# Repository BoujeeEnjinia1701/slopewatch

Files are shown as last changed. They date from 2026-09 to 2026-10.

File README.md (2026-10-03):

# SlopeWatch

     

**Area:** Mining · **TRL:** 3 of 9 (proof of concept on paper) · **Value-engineering target:** about $250 USD · **Difficulty:** 3 of 5

A network of low-cost tilt and displacement sensors for waste dumps, tailings dams, pit walls and landslide-prone slopes, reporting through FieldNode and alerting when movement accelerates.

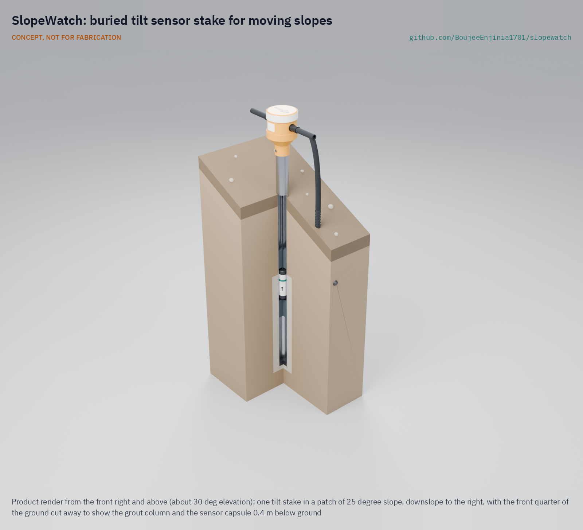
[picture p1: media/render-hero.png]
SlopeWatch: buried tilt sensor stake for moving slopes, product render


[Exploded render](media/render-exploded.png) · [Detail render](media/render-detail.png) · [Interactive 3D model](media/viewer.html) · [Concept blueprint (PDF)](media/concept-blueprint.pdf) · [General arrangement SLW-DWG-001 (PDF)](cad/drawings/SLW-DWG-001.pdf) · [Calculations SLW-CAL-001](docs/04-calcs/01-sizing.md) · [Prototype build plan](docs/05-build-plan.md) · [Design decisions register](docs/06-design-decisions.md) · [Review note](docs/REVIEW.md)

## Concept rationale

Many slopes speed up before they fail, and the rate of movement, not a single position, is what tells people to leave. SlopeWatch measures that rate with MEMS tilt sensors buried in grouted stakes and a crack gauge at the crest, following a published surface-tilt method with precaution and warning thresholds of 0.01 and 0.1 degrees per hour ([Uchimura et al., 2015](https://www.sciencedirect.com/science/article/pii/S0038080615001122)). All sensors share one FieldNode power and radio core, and the siren and beacon on site are driven by that node directly, so the alarm still works when the network does not.

It is open and garage-buildable because the sites that most need monitoring, small mines, quarries and hillside villages, cannot buy slope radar or pay for geotechnical staff. The stakes are steel pipe and hand-mixed grout, the electronics are off the shelf, and the data format and alert rules are open, so a local partner can build, repair and audit the system and an engineer can check every reading.

## Burning platform

Landslides killed 55,997 people in 4,862 non-seismic events from 2004 to 2016, and slides triggered by human activity, including illegal mining and hill cutting, are increasing ([Froude and Petley, 2018](https://nhess.copernicus.org/articles/18/2161/2018/)). Mining failures add to the toll: the Brumadinho tailings dam collapse in Brazil killed 270 people in 2019 ([Zhu, Zhang and Puzrin, 2024](https://www.nature.com/articles/s43247-023-01086-9)), and the 2020 slope failure at the Hpakant jade mines in Myanmar killed at least 172 miners after about half a year of accelerating movement visible from satellite ([Hpakant multi-sensor study, 2021](https://www.sciencedirect.com/science/article/pii/S0924271621001489)).

The people most exposed have the least monitoring. An estimated 44 million people work in artisanal and small-scale mining across 80 countries ([World Bank, 2021](https://www.worldbank.org/en/news/press-release/2021/05/03/better-working-conditions-can-improve-safety-and-productivity-of-artisanal-and-small-scale-miners-around-t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)), mostly without any instrument on the pit walls and dumps above them. Not every failure gives surface warning (Brumadinho moved only about 30 mm in its final year; [Zhu, Zhang and Puzrin, 2024](https://www.nature.com/articles/s43247-023-01086-9)), so SlopeWatch is a first layer for slopes that move progressively, not a guarantee.

## Where it could be used

### By industry

| Industry | Use |
| --- | --- |
| Artisanal and small-scale mining | Tilt stakes on pit walls and benches above working areas, with a siren where people dig |
| Quarrying and aggregates | Monitoring benches, stockpiles and overburden dumps at sites with no geotechnical system |
| Mine waste management | Waste rock dumps and, with the owner's and engineer of record's permission, a supplementary layer on tailings embankments |
| Roads and railways | Cut slopes above roads in hill districts, alerting maintenance crews after heavy rain |
| Disaster risk management | Community landslide early warning run by a district disaster office or village committee |
| Research and education | An open, repeatable field instrument for university geotechnical projects and threshold studies |

### By country or region

| Country or region | Why it matters there |
| --- | --- |
| Brazil | The Fundão (2015, 19 deaths) and Brumadinho (2019, 270 deaths) tailings failures ([UK House of Commons Library](https://commonslibrary.parliament.uk/research-briefings/cdp-2023-0133/); [Zhu, Zhang and Puzrin, 2024](https://www.nature.com/articles/s43247-023-01086-9)) show the stakes; Brumadinho moved only about 30 mm in its last year, so SlopeWatch would suit the many smaller dumps and pit walls that move progressively, not a dam of that kind. |
| Myanmar | The 2020 Hpakant jade mine failure killed at least 172 miners after months of accelerating movement ([Hpakant multi-sensor study, 2021](https://www.sciencedirect.com/science/article/pii/S0924271621001489)); a rate-of-movement alarm is built to catch that kind of acceleration. |
| Ghana | On 3 September 2026 an illegal (galamsey) gold pit collapsed at Manso Keniago in the Ashanti Region, killing eight of the twelve miners inside ([Ghana Broadcasting Corporation](https://www.gbcghanaonline.com/general/eight-illegal-miners-confirmed-dead-after-pit-collapse-in-amansie-south/2026/2/)); worldwide, landslides triggered by illegal mining are increasing ([Froude and Petley, 2018](https://nhess.copernicus.org/articles/18/2161/2018/)). |
| India | Asia accounts for 75 % of fatal landslides ([Froude and Petley, 2018](https://nhess.copernicus.org/articles/18/2161/2018/)); a university wireless sensor network in Munnar, Kerala, delivered real-time warnings that led to evacuation alerts ([Amrita](https://www.amrita.edu/center/awna/landslide/)), showing that local networks can work. |
| Italy | The national inventory lists more than 620,000 landslides ([ISPRA IFFI](https://www.progettoiffi.isprambiente.it/en/inventory/)); low-cost stakes suit the many small slopes that official networks cannot cover. |
| Japan | The surface-tilt method and thresholds SlopeWatch adopts were developed on slopes in Japan and China ([Uchimura et al., 2015](https://www.sciencedirect.com/science/article/pii/S0038080615001122)), giving a high-income reference for validation. |

## What sparked the idea

The starting point was the Aberfan disaster of 21 October 1966, when colliery spoil Tip 7 slid onto a village and its school in South Wales and killed 144 people, 116 of them children ([Glamorgan Archives](https://glamarchives.gov.uk/blood/aberfan); [Institution of Civil Engineers](https://www.ice.org.uk/what-is-civil-engineering/infrastructure-projects/aberfan-disaster-lessons-learned)). An earlier tip on the same mountainside, Tip 4, had suffered a rotational slip followed by a flow slide in 1944 ([Hansard, House of Commons, 26 October 1967](https://api.parliament.uk/historic-hansard/commons/1967/oct/26/aberfan-disaster)), and on the morning of the disaster the crew found the point of Tip 7 had sunk by 9 to 10 ft (about 3 m), and then by about 20 ft (6 m), before the slide, as recorded by the Tribunal of inquiry ([Tribunal findings, quoted by the Northern Mine Research Society](https://nmrs.org.uk/mines-map/accidents-disasters/glamorganshire/aberfan-disaster-merthyr-tydfil-1966/)). The movement was seen, yet nothing turned it into a timely warning for the people below. The Tribunal found that blame rested on the National Coal Board, and the Mines and Quarries (Tips) Act 1969 followed to set safety rules for tips in Britain ([Hansard](https://api.parliament.uk/historic-hansard/commons/1967/oct/26/aberfan-disaster); [Glamorgan Archives](https://glamarchives.gov.uk/blood/aberfan)); SlopeWatch asks what a low-cost rate-of-movement alarm could do for the waste dumps and informal pits that have no such regime.

## Problem

Slope and tailings failures often give warning through slow movement, but monitoring is costly and many small mines and hillside communities have none.

## Concept

A network of low-cost tilt and displacement sensors for waste dumps, tailings dams, pit walls and landslide-prone slopes, reporting through FieldNode and alerting when movement accelerates.

Full design precis: [docs/02-concept.md](docs/02-concept.md)

## Key components

- Three tilt stakes: 48.3 mm steel pipe grouted 0.8 m into the slope, each with a sealed MEMS inclinometer capsule held on the pipe axis 0.4 m below ground, and a head made from stock drainage fittings that joins the capsule to the bus
- Crack displacement gauge (100 mm range) with its own bus reader, across a tension crack at the crest
- RS-485 sensor bus cable in conduit
- FieldNode power and radio core (shared lab component) on an existing pole at the toe, or on the optional mast
- Siren and beacon alert unit driven by the node, clamped to the pole like the FieldNode core, with a keyed silence switch on its own post about 5 m from the mast
- Gateway and alert software: any LoRaWAN server, SMS alerts and an inverse-velocity plot

Checked by calculation at TRL 3 ([SLW-CAL-001](docs/04-calcs/01-sizing.md)): readings every 10 min; the siren starts about 13 s after a confirmed warning with no network; temperature drift of a buried capsule stays within 0.0012 degrees per hour, about eight times below the precaution threshold; five sunless days in the precaution state with one alarm use about 7.3 Wh of the FieldNode cell's 13.1 Wh at -10 °C. Under Amish's decisions of 2026-09-25 ([SLW-DDR-002](docs/decisions/0002-recommendations-accepted.md)), the reference site mounts the node on an existing pole, with the mast as a site option, and the keyed silence switch stands on its own post about 5 m from the mast, where the siren gives about 95 dB(A) instead of about 105 dB(A). Value-engineering target: USD 250. Estimated cost of the constructable design: USD 304.00 per reference site for the SlopeWatch-specific parts (USD 54.00 over the target; $332.00 where a new mast is needed); the FieldNode core ($126) is costed in its own project. Siren reach near machinery, the FieldNode 12 V rail current, the FieldNode enclosure temperature and the remote alert time at the slowest radio setting are at risk. See the [design precis](docs/02-concept.md) and [requirements](docs/03-requirements.md).

The priced bill of materials is in [bom/bom.csv](bom/bom.csv); the parametric model is `cad/src/model.py`, with STEP and STL files in `cad/step/` and `cad/stl/`.

## Building the prototype

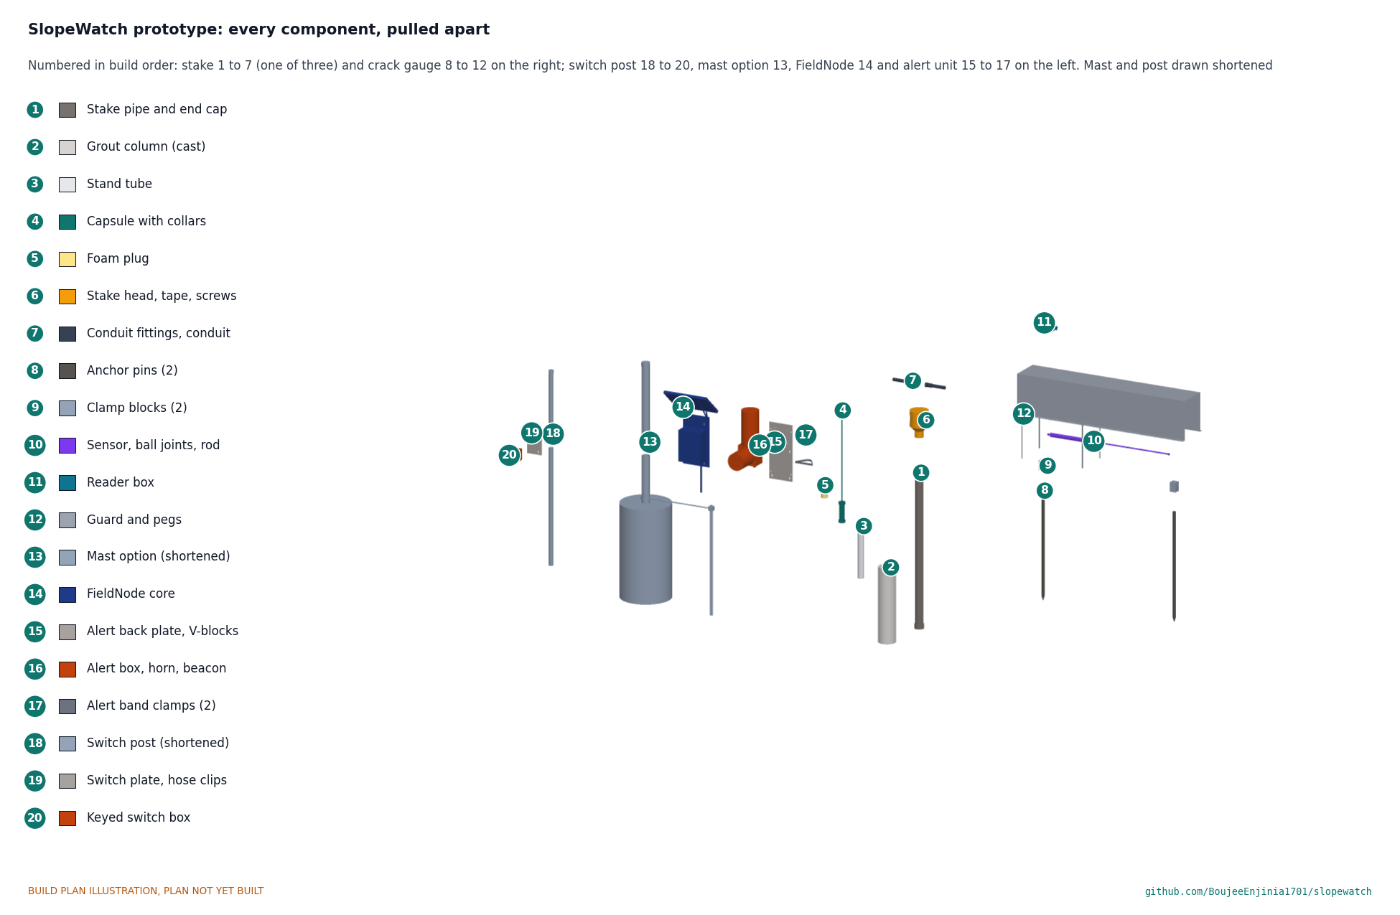
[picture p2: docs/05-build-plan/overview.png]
SlopeWatch prototype: every component pulled apart and numbered in build order


The [prototype build plan](docs/05-build-plan.md) (SLW-BLD-001) shows, in pictures, how to make each of the twenty components of one site kit and put them together in eighteen steps; nothing has been built yet. The made parts are the steel stakes with their stand tubes, printed collars and potted capsules, stake heads from stock drainage fittings, the crack gauge's pins, clamp blocks, rod and folded guard, and the aluminium and steel plates that clamp the alert unit and the keyed switch to their posts. Writing the plan made the design buildable: the capsule is now held on the pipe axis, the head can join the bus in and out, the gauge and its guard have real fixings, and the alert unit clamps to a pole the same way as the FieldNode core ([SLW-DDR-003](docs/decisions/0003-design-for-construction.md), accepted by Amish on 2026-10-02). Every picture is drawn from the model, and the model checks that each part touches what it should and clears what it should not.

## Safety

> Installing sensors on unstable ground is hazardous. Only trained teams should work on slopes, never below an actively moving face, and never on a tailings dam without the owner's permit and the engineer of record's agreement. The system is a research prototype that does not replace engineered monitoring: a silent siren is not proof of a safe slope, and some failures give no surface warning.
>
> The FieldNode core holds a LiFePO4 cell: use its fuse and cold-charge lockout. Wet cement grout burns skin and eyes; wear gloves and eye protection. Bond the mast to an earth rod and keep clear of overhead power lines.

## Repository layout

| Folder | Contents |
| --- | --- |
| `docs/` | Problem, concept, requirements, calculations and design decisions |
| `cad/src/` | build123d Python source, the source of truth for all geometry |
| `cad/step/`, `cad/stl/` | Exported models for FreeCAD, other CAD tools and printing |
| `cad/drawings/` | 2D sketches and dimensioned drawings |
| `bom/` | Bill of materials |
| `electronics/` | KiCad schematics and PCB layouts |
| `firmware/` | Microcontroller code |
| `media/` | Renders, perspectives and photos |
| `build-log/` | Dated prototyping notes |

## Documentation

Controlled documents follow the portfolio [documentation standard](.kit/STANDARDS.md). Each carries a document ID (SLW-PRC-001 for the precis), a version and a revision history. Branded PDFs are built with `python .kit/render.py` and attached to GitHub Releases when a document is tagged, for example `SLW-PRC-001/v1.0`.

## Credits

Designed by Amish Chadha. See [CONTRIBUTORS.md](CONTRIBUTORS.md) for roles. To cite this design, use [CITATION.cff](CITATION.cff) (GitHub shows it as "Cite this repository").

AI assistance (Claude) was used to accelerate concept renders, prototype documentation and first-pass sizing calculations. Design direction and all decisions are Amish Chadha's, recorded in this repository's decision records (`docs/decisions/`).

## Licenses

- **Hardware** (CAD, drawings, BOM, electronics): [CERN-OHL-S v2](LICENSE)
- **Software** (firmware, scripts, notebooks): [MIT](LICENSE-SOFTWARE)

A project of the [Design Molecule](https://designmolecule.com) lab.

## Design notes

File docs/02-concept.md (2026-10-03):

---
doc_id: SLW-PRC-001
title: SlopeWatch design precis
project: SlopeWatch
doc_type: Design precis
version: "0.7"
status: Draft
date: '2026-10-02'
author: Amish Chadha
license: CERN-OHL-S-2.0
revisions:
- version: "0.1"
  date: '2026-09-25'
  author: Amish Chadha
  change: Initial scaffold
- version: "0.2"
  date: '2026-09-25'
  author: Amish Chadha
  change: Populate to TRL 2 (architecture, alert logic, first-order numbers, safety, media)
- version: "0.3"
  date: '2026-09-25'
  author: Amish Chadha
  change: TRL 3 update from SLW-DDR-001 and SLW-CAL-001 (choices adopted for TRL 3 work, capsule 0.4 m deep, crack-gauge reader, beacon duty, checked numbers, cost, drawing SLW-DWG-001)
- version: "0.4"
  date: '2026-09-25'
  author: Amish Chadha
  change: Recommendations accepted by Amish (DDR-002)
- version: "0.5"
  date: '2026-10-01'
  author: Amish Chadha
  change: Constructable design (SLW-DDR-003) and build plan SLW-BLD-001; cost against the value-engineering target; key numbers from SLW-CAL-001 v0.3
- version: "0.6"
  date: '2026-10-02'
  author: Amish Chadha
  change: "Decisions of 2026-10-02 carried in: thresholds for logging only until set per site, mast conditions, second alert unit at machinery sites, cable protection and fault message, stake marking, wall holes, pinout, first partner"
- version: "0.7"
  date: '2026-10-02'
  author: Amish Chadha
  change: "Approved decisions carried into the figures: stake head marking cost, 60.3 mm site mast case and gust condition, alert back plate wall holes, port pin assignment; cost from SLW-CAL-001 v0.4"
---

# SlopeWatch design precis

SlopeWatch watches a slope for accelerating movement with three grouted tilt stakes and a crack gauge, cabled to one FieldNode core on an existing pole (or an optional mast) at the toe, and sounds a siren and beacon on site when the tilt rate passes a warning threshold, while sending an SMS through LoRaWAN. The TRL 3 calculations (SLW-CAL-001) show that the inclinometer resolves the tilt-rate thresholds with a wide margin, that a capsule 0.4 m deep keeps temperature drift within R2 even in wet soil, that the siren starts about 13 s after a confirmed warning, and that the FieldNode cell covers five sunless days with an alarm. Amish accepted the recommended choices on 2026-09-25 (SLW-DDR-002): the reference site uses an existing pole, with the mast as a site option, and the keyed silence switch stands on its own post about 5 m from the siren. Making the design physically buildable (SLW-DDR-003, accepted by Amish on 2026-10-02) added end caps, stand tubes and centring collars to the stakes, stake heads from stock drainage fittings with conduit fittings, clamp blocks and ball joints on the crack gauge, and a pole mounting for the alert unit; the prototype build plan is SLW-BLD-001. Value-engineering target: USD 250. Estimated cost of the constructable design: USD 304.00 for the SlopeWatch-specific parts of the reference site (USD 54.00 over the target), or $332.00 where a new mast is needed; the FieldNode core ($126) is costed in its own project. The main risks are siren reach near machinery, the unrated FieldNode 12 V rail current and the remote alert time at the slowest radio setting.

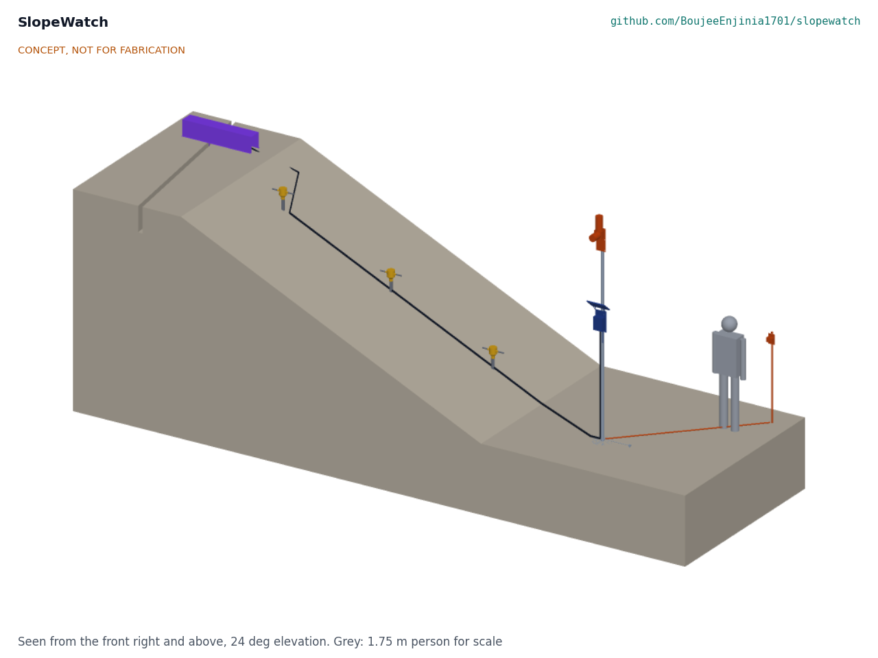
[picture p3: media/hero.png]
Hero render


*Figure 1. SlopeWatch on a 25 degree slope (spacing compressed for the picture; the reference site has stakes 10 m apart): three tilt stakes on the fall line, a crack gauge (purple) across a tension crack at the crest, the mast (a site option; an existing pole in the reference site) with FieldNode core, siren and beacon at the toe, and the keyed switch on its own post. Grey figure: 1.75 m person for scale.*

## How it works

1. **Sense tilt.** Each tilt stake is a 48 mm steel pipe grouted 0.8 m into the slope's surface layer. A sealed capsule with a MEMS inclinometer sits inside the pipe 0.4 m below ground, between two foam plugs. When the surface layer creeps downslope, the stake rotates with it; the approach and its thresholds follow Uchimura et al. ([2015](https://www.sciencedirect.com/science/article/pii/S0038080615001122)).
2. **Sense cracks.** A crack gauge spans a tension crack near the crest, where movement often shows first: two anchor pins either side of the crack and a 100 mm linear displacement sensor between them, under a guard, with a small reader board that puts the gauge on the same bus as the capsules.
3. **Collect.** A four-core cable in conduit links all sensors on an RS-485 bus to one of the FieldNode core's M12 ports, powered from its 5 V rail. Every 10 min the node switches the bus on for about 12 s, reads a 10 s average from each capsule and the gauge, and switches it off.
4. **Decide.** The node computes the tilt and opening rate for each sensor and runs the alert rules below. Raw readings are kept on the node's flash for at least 90 days.
5. **Alarm.** In the warning state the node drives the siren and beacon through the second M12 port from its 12 V rail, with no network needed, and raises its uplink rate from hourly to every 10 min.
6. **Notify and review.** Readings reach any LoRaWAN server (the lab's TwinKit gateway or The Things Network). An open alert service sends SMS or app messages to named people and plots inverse velocity against time ([Fukuzono, 1985](https://www.jstage.jst.go.jp/article/jls1964/22/2/22_2_8/_article)) for the engineer.

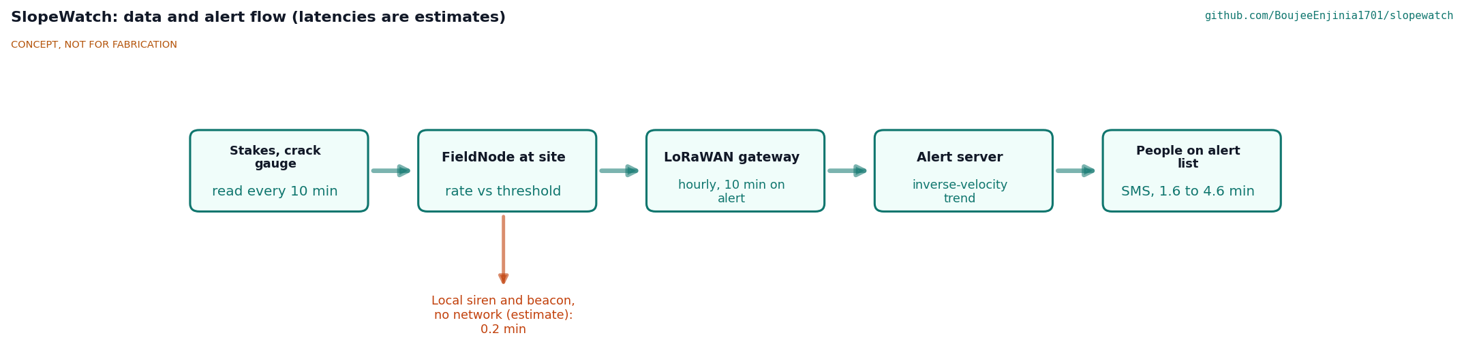
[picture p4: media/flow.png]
Data and alert flow


*Figure 2. Data and alert flow for one site. The local siren path does not depend on the network. All latencies are estimates.*

### Alert rules

The tilt rules below were decided by Amish on 2026-09-25 (SLW-DDR-001 D6, SLW-DDR-002). The crack-opening thresholds are placeholders. A geotechnical partner sets the thresholds per site before any alarm goes live; until then the tilt-rate thresholds and the crack placeholders are used for logging only, not for public alarms (decided by Amish, 2026-10-02; SLW-DDR-001 O3).

Table 1. Alert states.

| State | Entered when | Action |
| --- | --- | --- |
| Normal | No condition below | Read every 10 min; uplink hourly |
| Precaution | Any stake tilts faster than 0.01 degrees per hour averaged over 3 h, or the crack opens faster than 1 mm per day over 24 h (placeholder) | Uplink every 10 min; message to the site manager and engineer; beacon flashes slowly at 1 % duty or less (for example 100 ms every 10 s) |
| Warning | Any stake tilts faster than 0.1 degrees per hour over 1 h, confirmed on two consecutive readings, or the crack opens faster than 1 mm per hour (placeholder) | Siren and fast beacon on site; SMS to everyone on the list; inverse-velocity plot flagged |
| Silenced | Keyed switch on its post about 5 m from the mast | Siren off for 30 min, beacon stays on; the node re-arms automatically |

## Main components

Numbers match the exploded view (Figure 3) and `bom/bom.csv`.

Table 2. Main components.

| # | Component | Choice (decided by Amish, 2026-09-25) | Notes |
| --- | --- | --- | --- |
| 1 | Tilt stake (3 per site) | 48.3 x 3.2 mm galvanized steel pipe, 1.0 m long, 0.8 m in ground, screwed end cap, lower 450 mm in a 110 mm grout column | Couples the stake to the surface layer; steel passes R2 (SLW-CAL-001, section B) |
| 2 | Tilt sensor capsule (3) | Murata SCL3300 inclinometer in mode 1, small microcontroller, RS-485 transceiver and 3.3 V regulator, potted in a 34 x 130 mm tube with two centring collars | Sits 0.4 m below ground on a stand tube, under a foam plug, to damp temperature swings |
| 3 | Stake head (3) | 110 mm PVC drainage reducer, pipe and cap, with conduit fittings for the bus in (upslope) and out (downslope) | Keeps rain out of the pipe; joins the capsule to the bus; marks the stake: signal amber with a retroreflective band, a stake ID label and a downslope arrow on the crown (decided 2026-10-02) |
| 4 | Crack displacement gauge | 100 mm linear potentiometer displacement sensor on ball joints between clamp blocks on two anchor pins, under a folded guard, with an RS-485 reader | Re-settable when the crack opens past range |
| 5 | Sensor bus cable | Four-core shielded outdoor cable (power and RS-485) in corrugated conduit, about 60 m | Surface-laid in the prototype; buried in conduit where the ground allows, armoured cable only across rockfall zones; a fault message whenever a stake stops answering (decided 2026-10-02) |
| 6 | FieldNode core | Lab shared node: IP65 box, 6 W panel, LiFePO4 3.2 V 6 Ah, MPPT charger, STM32WL-class LoRaWAN radio, two M12 ports | Costed in the FieldNode project (SLW-DDR-001 D1) |
| 7 | Siren and beacon alert unit | 12 V piezo siren, about 110 dB(A) at 1 m, and an amber LED beacon, switched by the node, in an alert box on a back plate clamped to the pole with V-blocks and band clamps | Keyed silence switch on its own post about 5 m from the mast, on a 7 m lead (SLW-DDR-002) |
| 8 | Mast and footing (site option) | 48.3 x 3.2 mm galvanized pipe, 3.2 m above ground, in a 320 mm x 0.6 m concrete footing, with an earth rod | Only where no existing pole or building can carry the node (SLW-DDR-002); built for the first prototype; 60.3 mm pipe for site installations unless local gust data show winds well below 35 m/s (decided 2026-10-02) |
| 9 | Gateway and alert software | Any LoRaWAN server; open alert service with SMS and inverse-velocity plot | Not shown in the media; gateway (TwinKit, about $290) not in site cost |

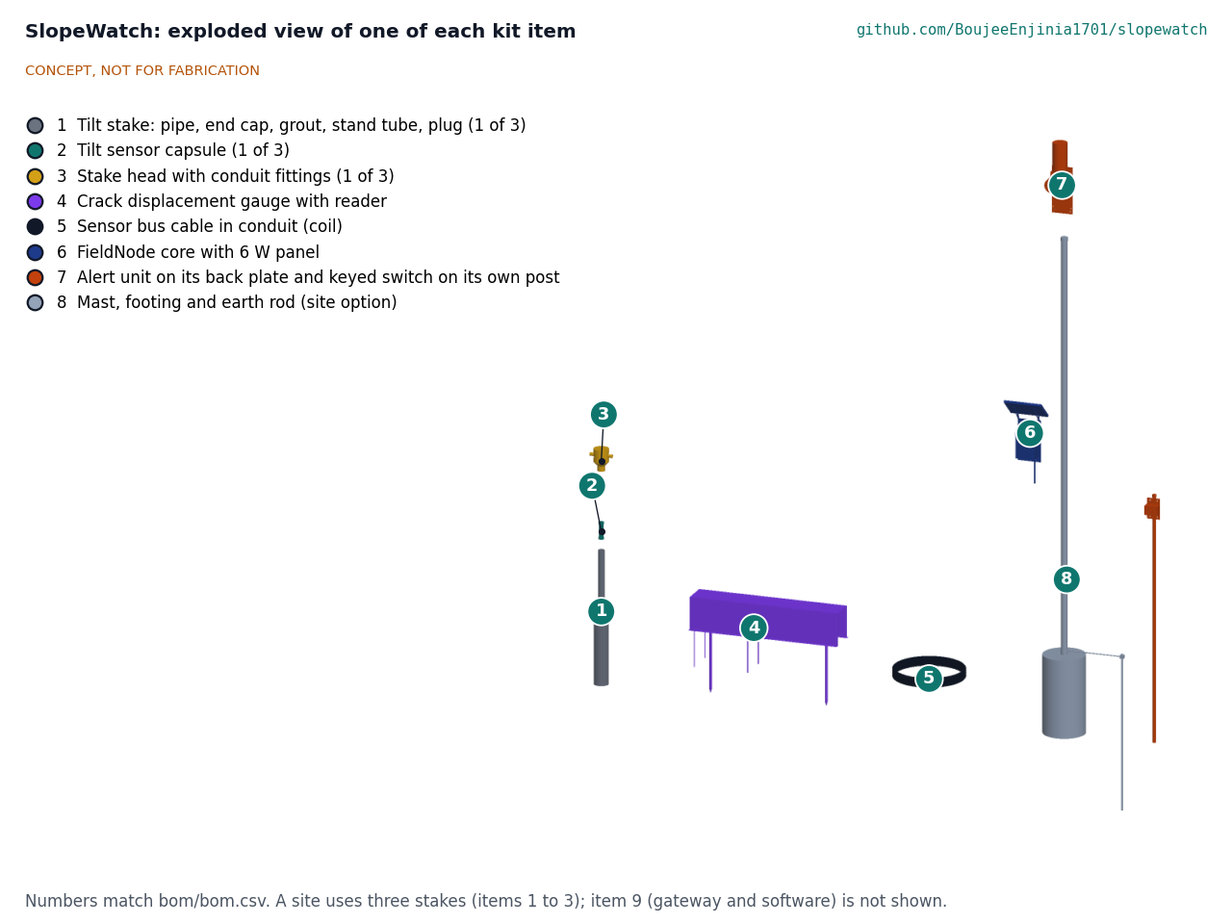
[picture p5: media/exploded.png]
Exploded view


*Figure 3. Exploded view of one of each kit item, with numbered callouts matching the BOM. A site uses three stakes (items 1 to 3).*

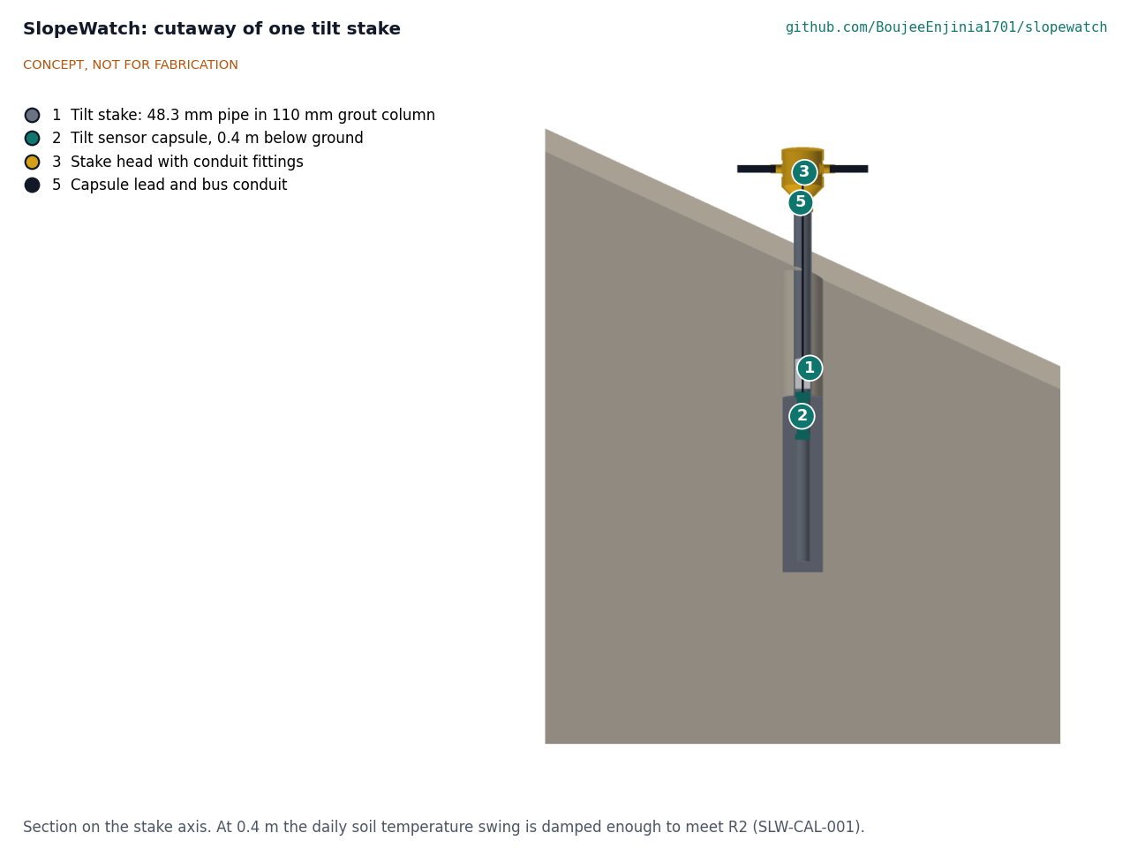
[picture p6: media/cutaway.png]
Cutaway of one tilt stake


*Figure 4. Section through one tilt stake on its axis, showing the grout column, the capsule 0.4 m below ground between foam plugs, and the lead to the cable gland.*

The general arrangement drawing [SLW-DWG-001](../cad/drawings/SLW-DWG-001.pdf) (Rev P4) gives the main dimensions of the stake, crack gauge, mast and switch post, generated from the parametric model `cad/src/model.py`.

## Key numbers (SLW-CAL-001)

All values are calculations for a paper proof of concept, from `docs/04-calcs/sizing.py`. They replace the TRL 2 estimates.

Table 3. Key numbers and requirement status.

| Quantity | Value | Requirement |
| --- | --- | --- |
| Inclinometer output step; noise over a 10 s average | 0.0055 degrees; 0.00054 degrees (mode 1, ±90 degrees) | R1 met on paper |
| Tilt-rate noise over 1 h | 0.00061 degrees per hour, 164 times below the warning rate | |
| Thermal drift, capsule 0.4 m deep, wet soil | 0.0092 degrees per day, peak 0.0012 degrees per hour | R2 met on paper |
| Same at 0.3 m (TRL 2 depth), wet soil | 0.0170 degrees per day, peak 0.0022 degrees per hour | Would miss R2 |
| Crack gauge step; thermal swing of the gauge | 0.024 mm; 0.39 mm per day (precaution rate taken over 24 h) | R3 met by design |
| Airtime per uplink | 0.45 s (SF10), 1.81 s (SF12); 0.30 % of time at SF12 | R4 met on paper |
| Confirmed warning to siren | about 13 s | R5 met by design |
| Warning to SMS | 1.6 min at the first try; 4.6 min at SF12 with one lost uplink | R6 at risk |
| Siren at 100 m | 65.5 to 68.5 dB(A) in open ground; about 5 m of reach over running plant | R7 at risk |
| Sensor load; precaution load | 2.67 mW; 29.8 mW with the beacon at 1 % duty | Within the FieldNode 100 mW allowance |
| 30 min alarm | 3.00 Wh, 0.45 A at 12 V, 2.00 A from the cell | R8 at risk on rail current |
| 5 sunless days in precaution with one alarm | 7.3 Wh of 13.1 Wh usable at -10 °C | R8 met on energy |
| Bus cable; voltage drop | 59.2 m; 0.096 V on the 5 V rail | |
| Mast in a 35 m/s gust (alert unit side-mounted) | 48.3 mm test mast 136 MPa (factor 1.7), footing factor 2.2; 60.3 mm site mast 82 MPa (factor 2.9), footing factor 2.1; 48.3 mm only where the local gust is below 33 m/s | |
| Siren level at the keyed switch | about 95 dB(A) on its post 5 m away (42 min NIOSH allowance); about 106 dB(A) on the mast (4 min) | Safety |
| Stake installation | 44 min estimated; 3.7 L of grout | R10 not verifiable at TRL 3 |
| 90 days of raw data | 363 kB | R12 met on paper |

### Cost

Table 4. Parts cost for the reference site (see `bom/bom.csv`). Value-engineering target: USD 250 (`budget_usd`, a hypothetical control target, not a limit). Estimated cost of the constructable design: USD 304.00 (USD 54.00 over the target).

| Group | Cost | Requirement |
| --- | --- | --- |
| Stakes, capsules and heads (items 1 to 3, three sets) | $162.00 | |
| Crack gauge with reader, cable, alert unit with switch post, consumables (items 4, 5, 7, 10) | $142.00 | |
| **SlopeWatch-specific parts, reference site (existing pole)** | **$304.00** | R11 over the value-engineering target by $54.00 |
| Optional mast and footing (item 8), where no pole exists | +$28, giving $332.00; the 60.3 mm site mast (item 11) +$37 in its place | Site option (SLW-DDR-002) |
| Site options outside the totals: second alert unit (item 12), armoured cable per 10 m (item 13), alert unit battery (item 14) | $64, $38, $20 | Decided 2026-10-02 |
| FieldNode core (item 6, costed in FieldNode) | $126 | Outside R11 |
| Reference site total with FieldNode | $430.00 | |
| LoRaWAN gateway, if the site has no coverage | not in site cost (TwinKit gateway about $290) | |

## Key design choices

Amish accepted every recommended choice on 2026-09-25 ("i accept all your recommendations, go with them across all repos"), recorded in SLW-DDR-002. Each choice below is decided by Amish, 2026-09-25: go with recommendation.

- **Budget (D1).** The FieldNode core is costed in its own project, as SunSpoke does with the SwapCell pack; the $250 value-engineering target covers SlopeWatch-specific parts.
- **Reference site on an existing pole (DDR-002 item 4).** The node and alert unit go on an existing pole or building; the mast and footing (item 8) are a site option. This closed the $11 gap that a new mast left at the time.
- **Tailings dams in the pitch (D2).** Kept, with the scope limits in SLW-PRB-001 stated in every document: supplementary layer only, installed with the owner's and engineer of record's permission, no claim to detect brittle failure.
- **Surface tilt stakes plus a crack gauge (D3),** rather than borehole in-place inclinometers (deep movement, but a drill rig and far higher cost), GNSS receivers (costly and slower to resolve millimeters) or crack gauges alone.
- **Wired bus to one FieldNode (D4).** About $41 per extra stake plus cable, against a FieldNode on every stake. A wireless stake variant is recorded for later.
- **Inclinometer (D5).** SCL3300 in mode 1, with an ADXL355-class accelerometer as the fallback.
- **Alert rules (D6).** The published 0.01 and 0.1 degrees per hour tilt-rate thresholds as defaults; warning on one stake confirmed on two consecutive readings (20 min); keyed 30 min silence that re-arms. Site values are set by an engineer after a baseline period. The precaution beacon flashes at 1 % duty or less (DDR-002 item 7).
- **Alert unit location (D7).** On the pole or mast at the toe; a second unit near the work face or in the village, linked by LoRa, as an option after co-design. At sites with running machinery the second unit at the work face is required (decided 2026-10-02).
- **Wall and timber pole fixing (decided 2026-10-02).** Both back plates get four wall holes so the node and the alert unit can be coach-screwed to a timber pole or wall; the change is to be agreed with FieldNode.
- **M12 pinout (decided 2026-10-02).** FieldNode's candidate pinout (pin 1 switched rail, pin 2 data A, pin 3 ground, pin 4 data B, pin 5 analog): SlopeWatch uses 12 V on pin 1, the bus on pins 2 and 4, and the keyed switch input on pin 5 of port B.
- **Keyed switch on its own post (DDR-002 item 6).** The switch box stands on a 26.9 mm post about 5 m from the siren, on a 7 m lead in conduit, where the siren gives about 95 dB(A) instead of about 105 dB(A) under it (SLW-CAL-001, section E).
- **Own gateway at SF12 sites (DDR-002 item 8).** A site whose uplinks need SF12 uses a TwinKit gateway, because hourly uplinks at SF12 exceed The Things Network's 30 s daily fair use.
- **Changes from the calculations.** The capsule sits 0.4 m deep with foam plugs; the crack gauge has its own reader; the crack precaution rate is taken over 24 h.

## Safety

> **Safety:** SlopeWatch is installed on ground that may already be moving and is meant to protect people from a slope failure. The two main hazards are harm to the installers and false confidence in the system. It is a research prototype and does not replace engineered monitoring, a trigger action response plan or evacuation planning.

- **Working on unstable slopes.** Install and service only with a partner's trained team, after a visual check by a competent person; never work below an actively moving face, below overhanging material or on a tailings dam crest or face without the owner's permit and the engineer of record's approval. Use a spotter, keep an escape route clear, and stop work in or after heavy rain.
- **False confidence and missed warnings.** A system that is silent is not proof of a safe slope. Brittle failures, failures deeper than the stakes, failures between stakes, earthquakes and heavy rain can all bring a slope down with little surface warning. Every site sign, SMS and document must say what SlopeWatch cannot detect. Flat batteries, cut cables and silenced sirens must raise a fault message.
- **False alarms.** Repeated false alarms teach people to ignore the siren. Thresholds and confirmation rules must be set with the community and a geotechnical partner, per site, before any alarm goes live, and reviewed after each alarm; until then the system logs only.
- **Lithium cell.** The FieldNode core holds a 19 Wh LiFePO4 cell, which supplies about 2 A during an alarm. Use the FieldNode's fuse and cold-charge lockout, do not charge a damaged cell, and keep the box out of standing water.
- **Cement grout.** Wet cement is alkaline and can burn skin and eyes. Wear gloves and eye protection and wash off splashes at once.
- **Mast and height.** The prototype's 48.3 mm mast has a factor of 1.7 on yield in a 35 m/s gust: use it only on a fenced test slope and keep everyone from under it in high wind; site installations use the 60.3 mm mast unless local gust data show winds well below 35 m/s. Where the optional mast is used, erecting a 3.2 m mast needs two people; keep well clear of overhead power lines. An exposed mast on a ridge can attract lightning: bond the mast to an earth rod and fit surge protection where the long bus cable enters the node.
- **Noise.** A 110 dB(A) siren can damage hearing at close range: about 105 dB(A) directly below it, where the NIOSH limit allows about 4 min. The keyed switch therefore stands on its own post about 5 m away, at about 95 dB(A) (about 43 min allowed; SLW-CAL-001, section E). Mount the siren at least 3 m above ground, silence it only with the keyed switch, and keep people away from the mast during an alarm.

## Open questions

- FieldNode to confirm that its 12 V rail supplies at least 0.5 A continuously for 30 min (R8); decided by Amish as a request to FieldNode (SLW-DDR-002), not yet actioned there. If it is not rated before the TRL 4 build, the alert unit gets its own small battery (decided 2026-10-02).
- Set crack-gauge and tilt thresholds per site with a geotechnical partner before any alarm goes live (decided 2026-10-02; SLW-DDR-001 O3).
- Confirm LoRaWAN coverage at candidate sites; a site that needs SF12 gets a TwinKit gateway (SLW-DDR-002).
- Approach the first partner (decided 2026-10-02, not yet agreed): an operating aggregate quarry with a geotechnical engineer on staff, testing on a bench away from the work face; a hillside community and its district disaster office only after TRL 4 (SLW-DDR-001 O2).
- Measure temperature drift of a buried capsule in a chamber (CalRig) and at a site; this is TRL 4 work and on hold.

Concept media: [blueprint sheet](../media/concept-blueprint.pdf), [interactive 3D model](../media/viewer.html).

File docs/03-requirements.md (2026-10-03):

---
doc_id: SLW-REQ-001
title: SlopeWatch requirements
project: SlopeWatch
doc_type: Requirements
version: "0.7"
status: Draft
date: '2026-10-02'
author: Amish Chadha
license: CERN-OHL-S-2.0
revisions:
- version: "0.1"
  date: '2026-09-25'
  author: Amish Chadha
  change: Initial scaffold
- version: "0.2"
  date: '2026-09-25'
  author: Amish Chadha
  change: First measurable requirements for TRL 2, with status against the concept estimates
- version: "0.3"
  date: '2026-09-25'
  author: Amish Chadha
  change: TRL 3 status from SLW-CAL-001; R11 redefined to SlopeWatch-specific parts (SLW-DDR-001 D1); reference-site layout and FieldNode port assumptions stated
- version: "0.4"
  date: '2026-09-25'
  author: Amish Chadha
  change: Recommendations accepted by Amish (DDR-002)
- version: "0.5"
  date: '2026-10-01'
  author: Amish Chadha
  change: Status from SLW-CAL-001 v0.3 for the constructable design (SLW-DDR-003); R11 reported against the value-engineering target
- version: "0.6"
  date: '2026-10-02'
  author: Amish Chadha
  change: R7, R8 and threshold notes from the decisions of 2026-10-02 (SLW-DEC-001); no requirement changed status
- version: "0.7"
  date: '2026-10-02'
  author: Amish Chadha
  change: "R11 figures from SLW-CAL-001 v0.4 (stake head marking, USD 54.00 over the target); no requirement changed status"
---

# SlopeWatch requirements

These are first-pass requirements for one monitored site. Four of the thirteen are met on paper by calculation and two by design; four are at risk, two can only be shown in the field, and R11 (cost) is reported against its value-engineering target (SLW-CAL-001 v0.4, Table 3). None is unmet. The `budget_usd` figure of $250 is a hypothetical value-engineering target, not a spending limit. Value-engineering target: USD 250. Estimated cost of the constructable design (SLW-DDR-003): USD 304.00 for the reference site (USD 54.00 over the target), and $332.00 where a new mast is needed. Amish decided on 2026-09-25 (SLW-DDR-002) that the reference site mounts the node on an existing pole, with a new mast as a site option. R11 was redefined under SLW-DDR-001 D1 (the FieldNode core is costed in the FieldNode project), now also decided by Amish. Targets are still proposals, not yet validated with users, and will be revised after co-design sessions (see SLW-PRB-001). "Met on paper" means shown by calculation, not by test.

The **reference site** is a slope or dump face up to about 50 m wide with three tilt stakes 10 m apart on the fall line, one crack gauge across a tension crack at the crest, and the FieldNode core and alert unit on an existing pole or building 15 m beyond the toe, within 60 m of cable, with the keyed silence switch on its own post about 5 m from the siren. Where no pole exists, the optional mast (BOM line 8) takes its place (SLW-DDR-002).

Table 1. SlopeWatch requirements for one site.

| ID | Requirement | Target | Verification (TRL 3 or later) | Status at TRL 3 (SLW-CAL-001) |
| --- | --- | --- | --- | --- |
| R1 | Measure surface tilt | Resolution 0.01 degrees or finer; range ±30 degrees or more on two axes | Datasheet and calculation; later bench tilt table | Met on paper: 0.0055 degree step and ±90 degrees in the sensor's mode 1 (modes 3 and 4 stop at ±10 degrees) |
| R2 | Limit false tilt from temperature | Apparent tilt change from the daily soil temperature cycle 0.02 degrees or less per day, and 0.002 degrees per hour or less, without software correction | Thermal calculation; later chamber test (CalRig) | Met on paper with the capsule 0.4 m deep: 0.0092 degrees per day and 0.0012 degrees per hour in wet soil; not met at the TRL 2 depth of 0.3 m in wet soil |
| R3 | Measure crack opening | Range 100 mm or more; resolution 0.1 mm; re-settable in the field without tools beyond a spanner | Datasheet and design review | Met by design (datasheet class); precaution rate taken over 24 h because of the gauge's own thermal swing |
| R4 | Sample and report often enough to see acceleration | Every sensor read every 10 min or faster; uplink every 60 min in the normal state and every 10 min in the precaution or warning state | Firmware sketch review; airtime calculation | Met on paper: 0.30 % of time at SF12 against the 1 % EU868 limit; a site that runs at SF12 uses a TwinKit gateway rather than The Things Network (SLW-DDR-002) |
| R5 | Local alarm without a network | Siren and beacon start within 60 s of a warning condition, driven by the on-site node alone | Design review; later bench test | Met by design: about 13 s |
| R6 | Remote alert | At least two named people notified by SMS or app within 5 min of a warning, where gateway and mobile coverage exist | Latency calculation; later end-to-end test | **At risk:** 1.6 min at the first try, 4.6 min at SF12 with one lost uplink; no remote alert at a site without a gateway |
| R7 | Alarm audible where people work | 65 dB(A) or more at 100 m from the mast in open ground | Spreading-loss calculation; later field measurement | **At risk:** 65.5 to 68.5 dB(A) in open ground; **not met** near running machinery. The keyed switch now sits about 5 m from the mast, at about 95 dB(A) instead of 105 dB(A) (SLW-DDR-002). Sites with running machinery get a second alert unit at the work face, linked by LoRa (decided 2026-10-02) |
| R8 | Energy autonomy | 5 days with no sun, including one 30 min alarm, on the FieldNode cell | Energy calculation | Met on energy (7.3 Wh of 13.1 Wh at -10 °C, with the precaution beacon at 1 % duty or less, decided in SLW-DDR-002); **at risk** on the FieldNode 12 V rail current (0.45 A, no rating stated; FieldNode asked to rate it at 0.5 A or more, SLW-DDR-002); if FieldNode has not rated it before the TRL 4 build, the alert unit gets its own small battery (decided 2026-10-02) |
| R9 | Survive burial and weather | Capsule and stake head IP67 and buried to 0.4 m; node IP65; operate -10 to 50 °C; cable in conduit rated for burial and UV | Datasheets and design review | **At risk:** SlopeWatch parts met by choice of parts; the FieldNode enclosure exceeds 60 °C in 45 °C sun (FND-CAL-001) |
| R10 | Installable by a small team | Each stake installed by two trained people with hand tools (post-hole auger or driven pilot, hand-mixed grout) in 45 min or less; no work below an actively moving face | Method review; later timed trial | **Not verifiable at TRL 3:** 44 min estimated for the constructable design, at the limit |
| R11 | Affordable | Parts specific to SlopeWatch for one reference site (node on an existing pole) within the $250 value-engineering target, excluding the FieldNode core (costed in the FieldNode project), any LoRaWAN gateway and the optional mast, which is a site option (SLW-DDR-002) | Priced BOM (`bom/bom.csv`) | Over the value-engineering target by $54.00: $304.00 for the constructable design; $332.00 at a site that needs the optional mast |
| R12 | Open, local data | 90 days or more of raw readings kept on the node; open CSV export; works with any LoRaWAN server | Storage calculation and design review | Met on paper: 363 kB for 90 days on 16 MB of flash |
| R13 | Trustworthy alarms | No more than one false warning per site per year, and a documented statement of the failure modes the system cannot detect | Field trial with partner | **Not verifiable at TRL 3**; statement in SLW-PRC-001 |

## Assumptions

- Tilt thresholds of 0.01 degrees per hour (precaution) and 0.1 degrees per hour (warning) follow Uchimura et al. (2015); site-specific thresholds must be set with a geotechnical engineer after a baseline period. Until a geotechnical partner has set them for a site, the thresholds drive logging only, not public alarms (decided 2026-10-02).
- The FieldNode core provides about 19 Wh of LiFePO4 storage (3.2 V, 6 Ah), switched 3.3, 5 and 12 V rails on two M12 5-pin ports (one rail per port), SPI flash and a LoRaWAN radio, as described in FND-PRC-001 and FND-REQ-001 v0.3. SlopeWatch uses one port at 5 V for the sensor bus and the other at 12 V for the alert unit.
- Siren sound level 110 dB(A) at 1 m, from typical 12 V piezo sirens; spherical spreading with air absorption and 0 to 3 dB of ground attenuation (SLW-CAL-001, section E).
- Soil temperature ranges and properties as in SLW-CAL-001, Table 1.
- Stake spacing and site layout will change after co-design; R11 is stated for the reference site only.
- Network rule (SLW-DDR-002): a site whose uplinks need SF12 uses its own gateway (TwinKit), because hourly uplinks at SF12 take 43.5 s a day, over The Things Network's 30 s fair-use allowance.

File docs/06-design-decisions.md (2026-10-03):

---
doc_id: SLW-DEC-001
title: SlopeWatch design decisions register
project: SlopeWatch
doc_type: Design decisions register
version: "0.3"
status: Draft
date: '2026-10-02'
author: Amish Chadha
license: CERN-OHL-S-2.0
revisions:
  - version: "0.1"
    date: '2026-10-01'
    author: Amish Chadha
    change: Register opened with the open decisions from the review note, SLW-DDR-001 to SLW-DDR-003 and the build plan work; budget treated as a value-engineering target
  - version: "0.2"
    date: '2026-10-02'
    author: Amish Chadha
    change: Amish approved the recommendations for open decisions 1 to 12 (SLW-DDR-003 accepted); moved to decisions made
  - version: "0.3"
    date: '2026-10-02'
    author: Amish Chadha
    change: Decisions of 2026-10-02 priced in the BOM (stake head marking and four site options); value engineering figures updated (SLW-CAL-001 v0.4)
---

# SlopeWatch design decisions register

Every design decision still to be made, and every decision made, in one place. Each decision is argued in full in its decision record under `docs/decisions/`; this register is the index Amish works from. The build plan (`docs/05-build-plan.md`) describes the design as it stands and does not list open decisions.

## Open decisions

None. All open decisions were decided on 2026-10-02.

## To confirm when parts are bought

| # | What to confirm | Why it matters | Source |
| --- | --- | --- | --- |
| 1 | The 1.5 in end cap thread matches the pipe thread (BSP or NPT) | The cap must seal against grout and water | SLW-DDR-003, P2 |
| 2 | The 110 x 50 mm reducer's 50 mm socket is 50 to 51 mm inside | The tape wrap takes up only about 1 mm a side | SLW-DDR-003, P3 |
| 3 | The capsule board is at most 28 mm wide and fits the 30 mm bore of the tube | Sets the capsule tube size | SLW-DDR-003, P1 |
| 4 | The displacement sensor has an M6 rod-end ball joint at each end and a removable plunger-end joint, and its plunger thread fits the coupling | The rod and the ball joints are sized to it | SLW-DDR-003, P5 |
| 5 | The alert and switch boxes have four corner screw holes outside the lid seal, and their spacing matches the plate holes | The plates are drilled to suit | SLW-DDR-003, P8, P9 |
| 6 | The horn has a sealing flange and the beacon a gasketed base that cover a 10 mm hole | Keeps the alert box sealed | SLW-DDR-003, P8 |
| 7 | The conduit fittings' hole size and lock nut size fit inside the 110 mm head | Sets the 20.5 mm holes and the lock nut clearance | SLW-DDR-003, P4 |
| 8 | The existing pole at the test site, if used, is round, 40 to 70 mm, and sound enough to carry the node and alert unit in wind | The fixing and the wind case depend on it | SLW-CAL-001 [H1] |

## Value engineering

Value-engineering target: USD 250 (a hypothetical control target, not a limit). Estimated cost of the constructable design: USD 304.00 for the SlopeWatch-specific parts of the reference site, node on an existing pole (USD 54.00 over the target); USD 332.00 where the optional mast is needed. The FieldNode core (USD 126) is costed in its own project. Main cost drivers and savings worth trying:

- The largest lines are the three tilt sensor capsules (USD 82.50, mostly the three inclinometers at about USD 18 each), the crack gauge with its reader (USD 46), the alert unit with its switch post (USD 43), the bus cable in conduit (USD 42) and the three stakes (USD 39).
- Making the design constructable added USD 51.50: end caps and stand tubes (USD 12), collars (USD 1.50), stake heads from drainage fittings with conduit fittings and connectors (USD 18), the gauge's clamp blocks, ball joints, rod coupling, folded guard and pegs (USD 8), the alert and switch mounting plates and clamps (USD 10), and tape and a plug (USD 2).
- Decided on 2026-10-02 and now priced (bom/bom.csv): stake head marking (amber paint, retroreflective band, ID label and arrow, USD 2.50 a stake, USD 7.50 in the reference site); the wall holes in the alert back plate at no change in price; and, as site options outside every total, the 60.3 mm mast for site installations (USD 37.00, USD 9.00 more than line 8), a second alert unit at a machinery site (USD 64.00), armoured bus cable across a rockfall zone (USD 38.00 per 10 m) and an alert unit battery if FieldNode has not rated its 12 V rail (USD 20.00).
- Savings worth trying: bury the bus cable without conduit where the ground is soft and stable (up to about USD 15); buy the inclinometers and boards in a batch for several sites; make the guard from offcut sheet; use plain M20 cable glands on the stake heads where the conduit stops short of the head (about USD 2 a stake); price a second-source crack sensor with ball joints included.

## Decisions made

| Date | Decision | Decided by | Record |
| --- | --- | --- | --- |
| 2026-09-25 | TRL 2 review items D1 to D7: FieldNode core costed in FieldNode; tailings dams kept in the pitch with limits; surface tilt stakes plus a crack gauge; wired RS-485 bus; SCL3300 in mode 1; published tilt-rate thresholds and keyed 30 min silence; alert unit at the toe | Amish: "i accept all your recommendations, go with them across all repos." | SLW-DDR-001, SLW-DDR-002 |
| 2026-09-25 | Reference site on an existing pole, mast a site option; FieldNode asked to rate its 12 V rail; keyed switch on its own post about 5 m from the siren; precaution beacon at 1 % duty or less; own TwinKit gateway at SF12 sites | Amish, same instruction: go with recommendation | SLW-DDR-002, items 8 to 12 |
| 2026-09-30 | Make the design physically buildable while drawing the build plan, keeping what the product does; changes recorded for review and accepted on 2026-10-02 (below) | Amish: "If you are realising that the design cannot be built as per concept - fix the design assumptions to match and be physically feasible as you draw the illustrations." | SLW-DDR-003 (changes open for his review) |
| 2026-09-30 | Build plan format approved; open decisions kept out of the build plan, in this register | Amish: "this is the correct build plan ... this is a good quality document format. Extend this across all the other repos" | SLW-BLD-001, SLW-DEC-001 |
| 2026-10-01 | `budget_usd` is a hypothetical value-engineering target, not a limit; cost reported against it | Amish: "the budgets are a hypothethical control target to ensure we are thinking along a value engineering lens. its ok to ensure wording reflects that the hypothesis budget was x - the real cost being accrued is y" | This register, Value engineering; SLW-CAL-001 v0.3 |
| 2026-10-02 | Design for construction accepted: the changes P1 to P11, as made | Amish: "i approve your recommendations for all 555 open decisions." | SLW-DDR-003, Table 1 |
| 2026-10-02 | Mast factor of 1.7 on yield accepted for the prototype on a fenced test slope with no one under the mast in high wind; any site installation uses the 60.3 mm mast unless local gust data show winds well below 35 m/s | Amish: "i approve your recommendations for all 555 open decisions." | SLW-DDR-003, A1; SLW-CAL-001 [H2] |
| 2026-10-02 | Four wall holes are added to both back plates so the node and the alert unit can be coach-screwed to a timber pole or wall; the change is to be agreed with FieldNode | Amish: "i approve your recommendations for all 555 open decisions." | SLW-DDR-003, A2 |
| 2026-10-02 | The optional mast is built for the first prototype | Amish: "i approve your recommendations for all 555 open decisions." | SLW-DDR-003, A3 |
| 2026-10-02 | The `problem` wording "often give warning" is accepted | Amish: "i approve your recommendations for all 555 open decisions." | SLW-DDR-001 O1, SLW-DDR-002 |
| 2026-10-02 | First co-design partner and site type to approach: an operating aggregate quarry with a geotechnical engineer on staff, testing on a bench away from the work face; a hillside community and its district disaster office only after TRL 4 | Amish: "i approve your recommendations for all 555 open decisions." | SLW-DDR-001 O2 |
| 2026-10-02 | A geotechnical partner sets thresholds per site before any alarm goes live; until then the published tilt-rate thresholds and the crack-gauge placeholders are used for logging only, not for public alarms | Amish: "i approve your recommendations for all 555 open decisions." | SLW-DDR-001 O3 |
| 2026-10-02 | At sites with running machinery, a second alert unit at the work face, linked by LoRa; pagers stay a later option | Amish: "i approve your recommendations for all 555 open decisions." | SLW-PRC-001, open questions; SLW-CAL-001 [E3] |
| 2026-10-02 | A fault message whenever a stake stops answering; the bus runs in buried conduit where the ground allows, and armoured cable only across rockfall zones | Amish: "i approve your recommendations for all 555 open decisions." | SLW-PRC-001, open questions |
| 2026-10-02 | Stake heads in signal amber with a retroreflective band, a stake ID label and a downslope arrow on the crown | Amish: "i approve your recommendations for all 555 open decisions." | REVIEW 2026-09-26 |
| 2026-10-02 | The request to FieldNode for a 12 V rail rated at least 0.5 A continuous stands; if FieldNode has not rated it before the TRL 4 build, the alert unit gets its own small battery | Amish: "i approve your recommendations for all 555 open decisions." | SLW-DDR-002 item 9 |
| 2026-10-02 | FieldNode's candidate pinout adopted (pin 1 switched rail, pin 2 data A, pin 3 ground, pin 4 data B, pin 5 analog); SlopeWatch uses 12 V on pin 1 with the bus on pins 2 and 4, and the keyed switch input on pin 5 of port B | Amish: "i approve your recommendations for all 555 open decisions." | FND-DDR-001 O2 |

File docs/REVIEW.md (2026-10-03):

# Review note: SlopeWatch

## Session 2026-09-25: /populate to a strong TRL 2

### What was done

- `docs/01-problem.md` (SLW-PRB-001 v0.2): problem with cited figures, users, operating environment, constraints, out of scope (including failure modes it cannot detect), cited prior work, open questions; co-design checklist kept.
- `docs/03-requirements.md` (SLW-REQ-001 v0.2): 13 measurable requirements (R1 to R13) for a defined reference site, with a status column against the concept estimates.
- `docs/02-concept.md` (SLW-PRC-001 v0.2): how it works, proposed alert states, numbered components, first-order numbers (tilt resolution, temperature drift, crack gauge, airtime, energy, alarm reach, cost), design choices, safety, open questions.
- `cad/src/concept_media.py`: massing model of a 25 degree slope with three tilt stakes, crack gauge, bus cable, mast with FieldNode core, siren and beacon, and a 1.75 m person on the toe bench; a separate kit layout for the exploded view and a single-stake section for the cutaway.
- `media/`: `hero.png`, `concept-blueprint.png`/`.pdf`/`.svg`, `model.glb` and `viewer.html`, `exploded.png` (callouts 1 to 8 match the BOM), `cutaway.png` (one stake on its axis), `flow.png` (data and alert flow, latencies marked as estimates). Temporary `media/_views*` folders removed.
- `bom/bom.csv`: 10 lines with indicative prices, numbered to match the exploded view; `bom/bom-notes.md` updated.
- `README.md`: hero image and links line; concept rationale, burning platform, industry and region tables and spark expanded with cited sources; key components and safety updated.
- `project.yaml`: `problem` reworded from "Slope and tailings failures give warning" to "Slope and tailings failures often give warning", because the Brumadinho failure showed only about 30 mm of surface movement in its last year (Zhu, Zhang and Puzrin, 2024). Meaning kept; pitch, budget, TRL and other fields unchanged.
- `docs/pdf/`: branded PDFs of the three controlled documents.

### Key results (estimates, to be checked at TRL 3)

| Quantity | Estimate | Requirement |
| --- | --- | --- |
| Tilt sensitivity (SCL3300 datasheet) | 0.005 degrees | R1 met |
| Temperature drift, capsule 300 mm deep | about 0.010 to 0.015 degrees per day, peak about 0.002 degrees per hour | R2 met, thin margin |
| Same sensor unburied | about 0.1 degrees per day | Would trip precaution daily |
| Airtime at 6 uplinks per hour | 0.07 % (SF10) to 0.25 % (SF12) of the 1 % EU868 limit | R4 met |
| Average sensor load on FieldNode | under 1 mW | R8 met on energy |
| 30 min alarm | about 3.2 Wh (17 % of the cell), about 2 A from the cell | R8 at risk on 12 V rail current |
| Siren at 100 m | about 65 to 70 dB(A) in open ground | R7 at risk; not met near machinery |
| Parts per site | about $380 with FieldNode, about $254 without | **R11 not met** |

Requirements not met or at risk:

- **R11 (cost) not met:** about $380 per site with the FieldNode core (52 % over $250), about $254 without it (2 % over).
- **R6 (remote alert) not met** at sites without LoRaWAN and mobile coverage; the local siren still works.
- **R7 (alarm reach) at risk** in quiet ground and **not met** near running machinery.
- **R8 at risk:** the FieldNode README does not state the 12 V rail current; the alert unit needs about 0.45 A.
- **R2 thin margin:** heat conducted down a sunlit steel pipe is not included.
- **R9, R10 unverified; R13 cannot be verified at TRL 2.**

### Proposed, awaiting Amish

Status update 2026-09-25: items 1 to 7 are decided by Amish, 2026-09-25: go with recommendation (SLW-DDR-002); items 8 and 9 had no recommendation and remain "Proposed, awaiting Amish".

1. **Budget.** (A) Raise `budget_usd` to $400 so a full site with its FieldNode fits. (B) Cost the FieldNode core in its own project, as SunSpoke does with SwapCell, and use an existing pole instead of the mast where possible, so SlopeWatch-specific parts fit $250. (C) Two stakes per site (about $339 with FieldNode). Recommendation: B. `project.yaml` budget unchanged. Decided by Amish, 2026-09-25: go with recommendation (SLW-DDR-002).
2. **Tailings dams in the pitch.** Keep them with explicit limits (supplementary layer, owner and engineer of record permission, no claim to detect brittle failure), or narrow the pitch to waste dumps, pit walls and natural slopes. Recommendation: keep, with the limits stated. Pitch unchanged. Decided by Amish, 2026-09-25: go with recommendation (SLW-DDR-002).
3. Surface tilt stakes plus one crack gauge, rather than borehole inclinometers or GNSS. Decided by Amish, 2026-09-25: go with recommendation (SLW-DDR-002).
4. Wired RS-485 bus to one FieldNode for the prototype; wireless stakes as a later variant. Decided by Amish, 2026-09-25: go with recommendation (SLW-DDR-002).
5. Murata SCL3300 inclinometer, with an ADXL355-class accelerometer as fallback. Decided by Amish, 2026-09-25: go with recommendation (SLW-DDR-002).
6. Alert rules: published 0.01 and 0.1 degrees per hour thresholds as defaults; warning on one stake confirmed on two readings; keyed 30 min silence that re-arms. Decided by Amish, 2026-09-25: go with recommendation (SLW-DDR-002).
7. Alert unit on the mast at the toe; a second unit near the work face or in the village as an option. Decided by Amish, 2026-09-25: go with recommendation (SLW-DDR-002).
8. Accept the `problem` wording change in `project.yaml` ("often give warning"), or revert it.
9. First partner and site type for co-design (artisanal mining cooperative, quarry, or hillside community with a district disaster office).

### Safety concerns

- Installers working on moving ground; never below an active face or on a tailings dam without permits.
- False confidence: some failures give no surface warning; faults (flat battery, cut cable, silenced siren) must be reported.
- False alarms eroding trust in the siren; thresholds set with the community and an engineer.
- LiFePO4 cell in the FieldNode core; wet cement grout; mast erection near power lines; lightning on exposed masts; siren loudness at close range.

### Problems and notes

- The kit's cutaway cuts at the mean part center, which missed the stakes, and the 10 m site made the exploded view unreadable. `concept_media.py` therefore renders the exploded view from a kit layout (one of each item) and the cutaway from a single stake, both with the kit's `_render`. Scene parts in `render_all` have no explode offsets, so `render_all` does not overwrite these files.
- The 1.75 m person is passed as a context part so it stands on the toe bench; the kit helper would place it at the bottom of the ground block.
- The legacy `cad/src/model.py` placeholder is untouched (TRL 3 work).
- Sibling dependencies: FieldNode (power, radio, flash; figures from its README), TwinKit (optional gateway), CalRig (proposed for capsule temperature characterization). SwapCell is not used.

### Recommended next step

Review this note and the media, then decide items 1 and 2. If approved, run `/advance-trl3` to check the temperature drift (including pipe conduction), alarm energy and rail current, siren reach and cost by calculation, and to produce the parametric model and drawing sheet.

## Session 2026-09-25: TRL 3

On 2026-09-25 Amish asked for this batch of repos to go through the usual process with the instruction "you know the drill, nothing gets past TRL 3". He has not reviewed this repo's TRL 2 items one by one, so every item that carried a recommendation is adopted as recommended for TRL 3 under Amish's 2026-09-25 instruction, open for his review. This session ran `/advance-trl3` on that basis and stopped at TRL 3.

### What was done

- `docs/decisions/0001-trl2-review-decisions.md` (SLW-DDR-001 v0.1, status proposed): seven items adopted as recommended for TRL 3, open for Amish's review (D1 to D7), and three left open (O1 to O3).
- `docs/04-calcs/01-sizing.md` (SLW-CAL-001 v0.1) and `docs/04-calcs/sizing.py`: tilt resolution and rate noise, temperature drift with soil damping and pipe conduction, crack gauge, airtime and alert latency, siren reach, energy and rail current, bus cable, mast wind load and footing, installation time, data and cost, with a status for every requirement. The script imports the model, reads the BOM and `project.yaml`, prints every number the note quotes and writes `docs/04-calcs/results.csv`.
- `cad/src/model.py`: parametric build123d model of the tilt stake (pipe, grout column, capsule, foam plugs, head, gland, lead), the crack gauge (pins, clamps, sensor body, rod, guard, reader box) and the mast (pole, footing, earth rod, FieldNode massing from the FieldNode model's dimensions, siren, horn, beacon, switch box). Exports `cad/step/` and `cad/stl/` for `slopewatch-stake`, `slopewatch-crack-gauge`, `slopewatch-mast` and `slopewatch-arrangement`.
- `cad/src/sheets.py` and `cad/drawings/SLW-DWG-001.svg`, `.pdf`, `.png`: general arrangement at Rev P1, 1:50, with a 1:10 stake section (Detail A), marked "CONCEPT, NOT FOR FABRICATION" and "PRELIMINARY, NOT FOR FABRICATION". SLW-DWG-001 was free because the concept blueprint is SLW-DWG-010.
- `bom/bom.csv` (10 lines, all priced with a supplier or supplier type) and `bom/bom-notes.md`.
- `cad/src/concept_media.py` now takes the stake, gauge and mast from the model; all of `media/` was re-rendered and every image checked; temporary `_views` folders deleted.
- SLW-PRB-001, SLW-PRC-001 and SLW-REQ-001 revised to v0.3; `README.md` (TRL badge and line, links, key components and checked numbers) and `project.yaml` (`trl: 3`, `trl_target: 3`, evidence list) updated. PDFs rebuilt in `docs/pdf/`.

Design changes found necessary by the calculations, within the adopted choices: the capsule moves from 0.3 m to 0.4 m deep with foam plugs above and below (R2 fails at 0.3 m in wet soil); the crack gauge gets its own RS-485 reader (+$6); the precaution beacon is held to 1 % duty (at 5 % a long precaution spell drains the cell, R8); the crack-gauge precaution rate is taken over 24 h (its own thermal swing reads as 1.22 mm per day over 3 h).

### Requirement status (SLW-CAL-001, Table 3)

1 not met, 4 at risk, 4 met on paper, 2 met by design, 2 not verifiable at TRL 3.

| ID | Status | Key number |
| --- | --- | --- |
| R11 Affordable | **Not met** | $261 SlopeWatch-specific parts with a new mast against $250; $237 on an existing pole; $387 with the FieldNode core |
| R6 Remote alert | At risk | 1.6 min at the first try; 4.6 min at SF12 with one lost uplink (limit 5 min); needs coverage |
| R7 Alarm audible | At risk | 65.5 to 68.5 dB(A) at 100 m in open ground; about 5 m of useful reach over 80 dB(A) plant |
| R8 Energy autonomy | At risk | 7.3 Wh of 13.1 Wh for five sunless days in precaution with an alarm; 0.45 A on a FieldNode 12 V rail with no stated rating |
| R9 Survive burial and weather | At risk | SlopeWatch parts IP67 by choice; FieldNode enclosure above 60 °C in 45 °C sun (FND-CAL-001) |
| R1, R2, R4, R12 | Met on paper | 0.0055 degree step, ±90 degrees in mode 1; 0.0012 degrees per hour drift at 0.4 m in wet soil; 0.30 % airtime at SF12; 363 kB for 90 days |
| R3, R5 | Met by design | 0.024 mm gauge step; 13 s to siren |
| R10, R13 | Not verifiable at TRL 3 | 43 min per stake estimated (limit 45 min); false-alarm rate needs a field record |

Key numbers: tilt-rate noise 164 times below the warning rate; SF10 and SF12 airtime 0.453 s and 1.810 s (TRL 2 said 0.4 s and 1.5 s); sensor load 2.67 mW (TRL 2 said under 1 mW); 30 min alarm 3.00 Wh; bus cable 59.2 m with a 0.096 V drop; mast 115 MPa in a 35 m/s gust (factor 2.0), footing factor 2.6.

### Decisions recorded (SLW-DDR-001)

Decided by Amish, 2026-09-25: go with recommendation (SLW-DDR-002; previously adopted as recommended for TRL 3, open for his review): D1 budget option B (FieldNode core costed in FieldNode, existing pole where possible; R11 redefined to SlopeWatch-specific parts; `budget_usd` unchanged at $250, no new figure recommended); D2 tailings dams kept in the pitch with limits (pitch unchanged); D3 surface tilt stakes plus a crack gauge; D4 wired RS-485 bus; D5 SCL3300 (mode 1) with ADXL355-class fallback; D6 alert rules and thresholds; D7 alert unit on the mast at the toe, second unit optional.

### Still awaiting Amish

Status update 2026-09-25: O1 to O3 remain "Proposed, awaiting Amish"; items 4 to 8 are decided by Amish, 2026-09-25: go with recommendation (SLW-DDR-002).

1. **O1, `problem` wording** ("often give warning"), changed at TRL 2 with no recommendation. The wording stays in place; accept or revert.
2. **O2, first co-design partner and site type.** No preference stated.
3. **O3, crack-gauge thresholds** (placeholders 1 mm per day over 24 h and 1 mm per hour), to be set with a geotechnical partner.
4. **New, R11 gap with a new mast ($11).** Options: (a) treat the existing-pole case ($237) as the reference and list the mast as a site option; (b) a cheaper local mast (for example a treated timber post), which would need its own wind check; (c) raise `budget_usd` to $270. Recommendation: (a). Decided by Amish, 2026-09-25: go with recommendation (SLW-DDR-002). Applied: the existing-pole case is the reference site; `budget_usd` stays $250.
5. **New, FieldNode 12 V rail (R8).** Options: (a) ask FieldNode to specify at least 0.5 A continuous on its 12 V rail; (b) give the alert unit its own small battery and charger (roughly $15, estimate). Recommendation: (a). Decided by Amish, 2026-09-25: go with recommendation (SLW-DDR-002). Listed as a cross-repo action; FieldNode was not edited.
6. **New, keyed switch location (safety, R7).** The switch sits under a siren giving about 105 dB(A) there. Recommendation: move it about 5 m from the mast on its own lead. Decided by Amish, 2026-09-25: go with recommendation (SLW-DDR-002). Applied (switch post).
7. **New, precaution beacon duty.** Set at 1 % or less by SLW-CAL-001 (R8); flagged here because it changes how visible the precaution state is. Decided by Amish, 2026-09-25: go with recommendation (SLW-DDR-002). (1 % or less kept.)
8. **New, networks at SF12.** A site that lives at SF12 on The Things Network exceeds its 30 s per day fair use even when hourly (43.5 s). Recommendation: such sites use a TwinKit gateway. Decided by Amish, 2026-09-25: go with recommendation (SLW-DDR-002). Applied as a network rule.

Suggestion only, not in the repo: a cut-cable and flat-battery fault message as a firmware rule at TRL 4.

### Cross-repo consistency

- FieldNode (FND REVIEW, TRL 3): the FieldNode core stays $126.00, the figure used here. SlopeWatch uses one M12 port at 5 V for the bus and one at 12 V for the alert unit, consistent with FND-DDR-001's one switched rail per port; the pinout is still open there (FND O2). SlopeWatch's precaution load (29.8 mW) fits both the 115 mW and the proposed 100 mW allowance. **Conflict noted:** FieldNode's proposed firmware airtime rule (lengthen the interval at SF10 and slower on The Things Network) would stretch SlopeWatch's 10 min alert-state uplinks; SlopeWatch needs an exception for alert states or a private gateway. **Gap noted:** FieldNode does not rate its 12 V rail current (item 5 above). FieldNode's own R3 (interior temperature) is not met, which is why R9 here is at risk.
- TwinKit (TWK REVIEW, TRL 3): gateway about $290 in parts; figures here updated from $285. TwinKit's airtime figures (72 ms at SF7, 247 ms at SF9, 1.8 s at SF12) match SLW-CAL-001.
- CalRig (CLR REVIEW, TRL 2): proposed for capsule drift characterization; its 36 L chamber takes the 34 x 130 mm capsule, and its 10 to 40 °C range covers the capsule's daily swing. No conflict.
- CellGuard, MotionCore and ThermaCart are not used. SwapCell is not used.
- No other repo was edited.

### Safety concerns

- Installers working on moving ground; never below an active face or on a tailings dam without permits.
- False confidence: some failures give no surface warning; faults (flat battery, cut cable, silenced siren) must be reported.
- Siren at close range: about 105 dB(A) at the keyed switch, 4 min allowed by NIOSH; keep people away from the mast during an alarm (item 6).
- False alarms eroding trust in the siren; the crack-gauge rule must average over 24 h or its own thermal swing trips it.
- LiFePO4 cell in the FieldNode core supplying about 2 A in an alarm; wet cement grout; mast erection near power lines; lightning on exposed masts (earth rod now in the model and BOM).

### Gaps and notes

- Citations: the TRL 2 note listed no unchecked citations. The SCL3300 figures used in SLW-CAL-001 (mode ranges, noise density, 0.0055 degree output step, ±0.005 degrees per K offset drift) were checked on 2026-09-25 by WebFetch against Murata's product page and datasheet. Other citations were not re-checked this session.
- Assumptions only tests can settle: soil thermal properties, the pipe-heating model (steady state, an upper bound), siren output against its rating, auger rate and the FieldNode rail rating.
- Media: the site scene compresses the 10 m stake spacing so the parts stay visible; the calculations use the reference layout in `cad/src/model.py` (`SITE`). The kit's cutaway cuts near the mean part center, which misses the stakes, so `concept_media.py` renders the cutaway from a single stake with the kit's `_render`, as at TRL 2. In the exploded view the small capsule (item 2) sits under its callout at the scale set by the 3.8 m mast; the cutaway and Detail A on SLW-DWG-001 show it.
- Existing material beyond TRL 3: `build-log/README.md` (scaffold) is present, untouched and not extended. `electronics/` and `firmware/` hold only placeholders. No test, build or firmware material exists.

### Recommended next step

TRL 4 is on hold by Amish's instruction; this repo stops at TRL 3. Amish's review is needed on SLW-DDR-001 (D1 to D7), on O1 to O3 and on items 4 to 8 above. For the record only, TRL 4 would need: a bench build of one capsule and the crack-gauge reader on a FieldNode; a lab test report (TST, `environment: lab`) covering capsule offset drift over temperature in CalRig, tilt resolution on a tilt table, bus operation over 60 m of cable, siren output and 12 V rail current during a 30 min alarm; and build log entries. None of this has been started.

## Session 2026-09-25: recommendations accepted

On 2026-09-25 Amish wrote, in chat: "i accept all your recommendations, go with them across all repos." Every item with a recommendation is now "Decided by Amish, 2026-09-25: go with recommendation", recorded in `docs/decisions/0002-recommendations-accepted.md` (SLW-DDR-002 v0.1). This session also regenerated every PDF, drawing and media file so that the footers show designmolecule.com, and rewrote the README's "What sparked the idea".

### Decisions applied and what changed

- **D1 to D7 (SLW-DDR-001):** status changed to decided in SLW-DDR-001 v0.2 and in the documents; no numbers changed. `budget_usd` stays $250 (no new figure was recommended).
- **R11 reference site (TRL 3 item 4, option a):** the node goes on an existing pole; the mast (BOM line 8, $24) is a site option. R11 restated in SLW-REQ-001 v0.4. SlopeWatch-specific cost $261 with a new mast (not met) to **$245** for the reference site (met on paper, $5 within $250); $269 where the mast is needed.
- **Keyed switch (TRL 3 item 6):** moved from the mast to its own 26.9 mm post about 5 m away on a 7 m lead. `cad/src/model.py` gains `switch_post()`; new `cad/step/slopewatch-switch-post.step` and `.stl`; SLW-DWG-001 Rev P1 to **P2**; BOM line 7 $25 to $33. Siren level at the switch 105.4 to 95.5 dB(A); NIOSH allowance 4.3 to 43 min. With the box off the mast, the mast base moment falls from 550 to 541 N·m, stress 115 to 113 MPa (factor 2.0 to 2.1), footing factor 2.6 to 2.7.
- **Precaution beacon (item 7):** 1 % duty or less kept; wording only.
- **SF12 sites (item 8):** network rule added: a site that needs SF12 uses a TwinKit gateway (hourly SF12 uplinks take 43.5 s a day against The Things Network's 30 s).
- **FieldNode 12 V rail (item 5, option a):** a request to FieldNode; see cross-repo actions.
- Documents bumped: SLW-PRB-001 0.3 to 0.4, SLW-PRC-001 0.3 to 0.4, SLW-REQ-001 0.3 to 0.4, SLW-CAL-001 0.1 to 0.2, SLW-DDR-001 0.1 to 0.2; SLW-DDR-002 v0.1 new. `sizing.py` re-run and `results.csv` rewritten; `model.py`, `sheets.py` and `concept_media.py` re-run; hero, exploded view and blueprint checked; `media/_views*` removed. `project.yaml` evidence list gains DDR-002 and the switch-post STEP.
- **README:** "What sparked the idea" now traces the idea to the 1966 Aberfan colliery tip disaster (Tip 7 had sunk by about 20 ft before it slid), with ICE and Northern Mine Research Society sources; key numbers and components updated.

### Requirement status (SLW-CAL-001 v0.2)

0 not met, 4 at risk, 5 met on paper, 2 met by design, 2 not verifiable at TRL 3.

| ID | Status | Key number |
| --- | --- | --- |
| R6 Remote alert | At risk | 4.6 min at SF12 with one lost uplink (limit 5 min); needs coverage |
| R7 Alarm audible | At risk | 65.5 to 68.5 dB(A) at 100 m; about 5 m of reach over 80 dB(A) plant |
| R8 Energy autonomy | At risk | 7.3 Wh of 13.1 Wh; 0.45 A on an unrated FieldNode 12 V rail |
| R9 Survive burial and weather | At risk | FieldNode enclosure above 60 °C in 45 °C sun (FND-CAL-001) |
| R1, R2, R4, R11, R12 | Met on paper | R11 $245 against $250 (was not met at $261) |
| R3, R5 | Met by design | 0.024 mm gauge step; 13 s to siren |
| R10, R13 | Not verifiable at TRL 3 | 43 min per stake; false-alarm rate needs a field record |

### Still awaiting Amish

1. **O1, `problem` wording** ("often give warning"): no recommendation was made; wording stays.
2. **O2, first co-design partner and site type:** no preference stated.
3. **O3, crack-gauge thresholds:** placeholders; no recommendation.

### Cross-repo actions

- **FieldNode:** rate the 12 V rail at 0.5 A or more continuous for 30 min (SlopeWatch R8).
- **FieldNode:** its proposed airtime rule (longer intervals at SF10 and slower on The Things Network) needs an exception for SlopeWatch alert states; SlopeWatch sites that need SF12 now use a TwinKit gateway.
- **TwinKit:** note that SlopeWatch sites at SF12 rely on a TwinKit gateway (about $290 in parts, outside the SlopeWatch site cost).
- No other repo was edited.

### Safety

- The keyed switch now stands about 5 m from the siren (about 95 dB(A)); people should still keep away from the mast during an alarm.
- An existing pole must carry the node, siren and beacon in wind; the installer checks it with the site owner, since SLW-CAL-001 checks only the optional mast.
- All TRL 2 and TRL 3 safety concerns above still apply.

### TRL 4

TRL 4 remains on hold by Amish's instruction. `trl: 3` and `trl_target: 3` are unchanged. Decided but on hold: the cut-cable and flat-battery fault message (firmware), the CalRig capsule drift test, bench builds and any field trial. None was started.

## Session 2026-09-26: sources strengthened

README.md only; no controlled document changed and no budget change.

| Where | Old source | New source |
| --- | --- | --- |
| Country row: Ghana | Ghana News Agency (seven deaths, early report) | Ghana Broadcasting Corporation, the national public broadcaster (eight of twelve miners killed, confirmed by police, NADMO and the ambulance service), plus Froude and Petley (2018) on landslides from illegal mining; the unsourced "collapse regularly" claim removed |
| Country row: Brazil | House of Commons Library and Zhu, Zhang and Puzrin (2024) | Same sources; the unsourced claim that the failures "drove new rules for large dams" and that small mines "remain largely unmonitored" removed |
| Country row: Myanmar | Hpakant multi-sensor study | Same source; the unsourced claim that informal mining continues on waste slopes removed |
| Burning platform, Brumadinho 30 mm | None | Zhu, Zhang and Puzrin (2024) |
| What sparked the idea | Institution of Civil Engineers and Northern Mine Research Society | Glamorgan Archives and Hansard (House of Commons, 26 October 1967) added as primary sources; ICE kept; NMRS kept only for the Tribunal's record of the tip sinking on the morning, now attributed to the Tribunal. Corrected: the 1944 slip was on Tip 4, not ground under Tip 7. Tips Act 1969 now cited. Inspiration event unchanged |

Not verified this session: the full text of the 1967 Tribunal report (the Durham Mining Museum copy could not be fetched), so the 9 to 10 ft and 20 ft figures rest on the NMRS quotation of it.

## Session 2026-09-26: product appearance model and photoreal renders

Amish chose this repo for the first batch of product renders on 2026-09-26. This session added `cad/src/product_model.py` (an appearance model for one tilt stake, items 1 to 3 with its bus lead) and pointed the README hero image at `media/render-hero.png`, with a link to `media/render-exploded.png`. The render files are produced separately by the orchestrator. No controlled document, BOM line, budget or `model.py` dimension changed.

### What `product_model.py` adds

- `product_parts()`: 26 parts (13 shell, 9 internal, 4 context) with colour, material, BOM line, group and explode offset, all built from `PARAMS`, `SITE` and `derived()` in `model.py`.
- Stake head: 10 mm filleted crown, a molding line above the skirt, a white retroreflective band, a curved stake ID label with print and a teal tag, a raised teal arrow on the crown pointing downslope, two stainless cap screws, the reducer ring, and the M20 gland as a locknut, body and domed seal nut.
- Bus cable leaving the gland in a smooth drip loop into a short ribbed stub of the 20 mm corrugated conduit (item 5), which runs buried downslope.
- Below ground: the galvanized pipe, bottom plug and grout column; the potted sensor capsule with dark end caps, a teal band and a label with an up arrow; the two closed-cell foam plugs; and the capsule lead up to the gland.
- Context: a compact patch of 25 degree slope (subsoil, a 45 mm topsoil layer and a few surface stones). The front downslope quarter of the ground, grout, buried pipe and foam plugs is cut away so the capsule 0.4 m below ground shows.
- `TITLE` and three `RENDER_VIEWS`: hero (stake in the cut-away slope patch), exploded (head, pipe and grout, with the plugs, capsule and lead drawn out to the side) and detail (the stake head above ground, without the slope, so the head fills the frame).

### Where the appearance model differs from `model.py`

Each item is **Proposed, awaiting Amish**.

1. **Head colour.** The BOM says the head is "painted for visibility" without a colour. The model uses a signal amber with a white retroreflective band. Recommendation: adopt amber plus a retroreflective band, which reads at a distance and in headlamps on a working slope.
2. **Stake ID label and downslope arrow.** Neither is in the BOM. The label identifies each of the three stakes; the arrow on the crown shows that the gland must face downslope at installation. Recommendation: adopt both as item 10 consumables (printed outdoor label and a painted or molded arrow).
3. **Two cap screws.** `model.py` shows the head resting on its reducer ring with no fixing. The model adds two stainless screws through the head into the pipe, in the 40 mm overlap. Recommendation: adopt, so the head cannot be lifted or turned by animals or wind-blown debris; add them to item 10.
4. **Conduit stub at the stake.** `model.py` stops the bus lead 60 mm outside the head. The model adds a drip loop and a 20 mm conduit stub about 70 mm out of the ground, 175 mm downslope of the stake. Recommendation: adopt as the reference arrangement; the conduit is already in item 5.
5. **Lead routing inside the head.** In `model.py` the lead turns horizontal at 230 mm above ground; here it bends to the gland axis at 220 mm. The gland position and size are unchanged. No action needed beyond noting it.
6. **Pipe split at ground level.** The pipe is two render parts (above and below ground) so the detail view can omit the buried parts. Size and length are unchanged. No action needed.

The cable gland hex (30 mm across flats) is slightly larger than the 28 mm gland envelope in `model.py`; this is a cosmetic difference, not a change of gland size.

### Status

This is an appearance model only: no tolerances and no fabrication detail. `trl: 3` and `trl_target: 3` in `project.yaml` are unchanged, and TRL 4 remains on hold by Amish's instruction.

## Session 2026-09-27: kit 1.5.0 and image quality

- Kit 1.5.0 synced: STANDARDS v1.5 (sections 12 to 15: product renders, storefront images and image quality, public release, authorship and signing), `.kit/cards.py`, `.kit/image_qc.py`, `.kit/release_gate.py`, issue templates, and the `/render-product` and `/release` commands. `CLAUDE.md` now matches `.kit/CLAUDE.md`.
- Every `media/render-*.png` recaptioned from its original render with the new layout: the title, concept label and repository sit in a band above the render and the view note in a band below it, each line wrapped to the image width, so no text overlaps other text or the render or runs off the image. `media/card.png` and `media/social-preview.png` regenerated with the same rules.
- `python .kit/image_qc.py` and `python .kit/release_gate.py` pass. trl stays 3.

## Session 2026-10-01: build plan and design for construction (kit 1.7.0)

Amish approved the build plan format on 2026-09-30 and asked for it across all repos, with open decisions kept in a separate design decisions register. This session installed kit 1.7.0 (`CLAUDE.md` now matches `.kit/CLAUDE.md`), made the design constructable and wrote the build plan and the register. Nothing was built; TRL stays 3.

### What was done

- `cad/src/model.py`: rebuilt as separate components (`build_components()`), with 79 constructability checks (`python cad/src/model.py --check`), all passing. STEP and STL regenerated.
- `docs/decisions/0003-design-for-construction.md` (SLW-DDR-003 v0.1, Draft): every change below, made under Amish's 2026-09-30 instruction to make the design physically buildable; open for his review.
- `cad/src/build_plan_media.py`: overview, 16 making sketches (`cad/drawings/SLW-DWG-101` to `116`), 12 joint close-ups, 18 assembly step pictures, a bus wiring diagram and a site layout (`docs/05-build-plan/`).
- `docs/05-build-plan.md` (SLW-BLD-001 v0.1) and `docs/06-design-decisions.md` (SLW-DEC-001 v0.1).
- SLW-DWG-001 Rev P3 to P4; SLW-CAL-001 v0.3, SLW-REQ-001 v0.5, SLW-PRC-001 v0.5; `bom/bom.csv` and `bom/bom-notes.md`; concept media re-rendered; README links line and "Building the prototype" section; `project.yaml` gains `design_state: constructable` and the new documents in `trl_evidence`.

### Design changes made for construction (SLW-DDR-003)

1. Capsule held on the pipe axis by two printed centring collars and set at 0.4 m by a 40 mm PVC stand tube on the pipe's bottom cap (the lower foam plug is replaced by the stand tube).
2. Pipe bottom closed by a screwed 1.5 in malleable-iron end cap; hole augered 829 mm so grout runs under it.
3. Stake head made from stock 110 mm drainage fittings (110 x 50 mm reducer, 94 mm of pipe, end cap), sealed on a tape wrap and held by two M5 screws drilled through the socket into the pipe.
4. Two M20 conduit fittings on each head (bus in upslope, bus out downslope) with lever connectors inside, replacing the single cable gland.
5. Crack gauge: 40 x 40 x 60 mm aluminium clamp blocks with M8 set screws, M6 rod-end ball joints, a coupling and a 501 mm stainless extension rod.
6. Guard: folded 1.5 mm galvanized channel on feet, 48 mm above the pin tops, pegged on its upslope half only (it used to pass through both pins and float).
7. Reader box hung under the guard web on two M4 screws, with a conduit fitting on its downslope end.
8. Alert unit: alert box on a 160 x 360 mm aluminium back plate clamped to the pole or mast with two V-blocks and two band clamps (the FieldNode fixing); siren centre 3.23 m on the mast; push-on mast cap.
9. Keyed switch box on a galvanized back plate held to its post by two hose clips.
10. FieldNode massing updated to its constructable design (FND-DDR-003).
11. Earth bond with a rod clamp, a mast bonding clamp and a 16 mm² conductor.

### Key results

- Requirement status (SLW-CAL-001 v0.3): 0 not met, 4 at risk (R6, R7, R8, R9), 4 met on paper, 2 met by design, 2 not verifiable at TRL 3, and R11 over the value-engineering target.
- Value-engineering target: USD 250. Estimated cost of the constructable design: USD 296.50 for the reference site (USD 46.50 over the target); $324.50 with the optional mast.
- Optional mast in a 35 m/s gust: 136 MPa, factor 1.7 on yield (was 2.1), footing factor 2.2 (was 2.7), because the alert unit's back plate is now in the wind area.
- Crack gauge thermal swing 0.36 mm a day (was 0.39); installation estimate 44 min (was 43), at the R10 limit; level at the keyed switch 95.5 dB(A).

### Proposed, awaiting Amish

See the register (SLW-DEC-001). New from this session: accept SLW-DDR-003; the mast margin (A1, recommend accept 1.7 for the prototype); mounting on larger poles or walls (A2, recommend wall holes in both back plates); the pole for the first prototype (A3, recommend the mast). Still open from earlier sessions: O1 to O3, second alert unit near machinery, cable protection and cut-cable detection, head colour and marking, and the FieldNode 12 V rail rating and port pinout.

### Stale, to regenerate on Amish's Mac

`cad/src/product_model.py`, the photoreal renders `media/render-*.png`, `media/card.png` and `media/social-preview.png` show the concept stake head (120 mm cap, one gland, drip loop into a conduit stub); the head is now a 110 mm drainage-fitting head with two conduit fittings. They were not regenerated here. `media/render-hero.png` is not in this cloud copy.

### Safety

- The build plan carries safety stops S1 to S7 (slope work, augering, grout, the FieldNode cell, raising the mast, the first siren test, leaving the site).
- The optional mast's wind margin falls to 1.7 on yield; check it against local wind data before a site installation.
- All earlier safety concerns still apply.

### Recommended next step

Amish to review SLW-DDR-003 and decide items 1 to 4 of the register. TRL 4 (building to this plan) remains on hold.

## Session 2026-10-02: open decisions decided

On 2026-10-02 Amish approved every recommendation written for the open decisions: "i approve your recommendations for all 555 open decisions." Nothing was built or tested; TRL 4 remains on hold.

### Decisions recorded

12 decisions moved from "Open decisions" to "Decisions made" in the design decisions register, dated 2026-10-02. Design for construction (SLW-DDR-003) accepted with A1 (sharpened), A2 and A3; the problem wording kept; an operating aggregate quarry named as the first partner to approach; thresholds for logging only until set per site; a second alert unit at machinery sites; cable protection and a fault message; stake marking; a battery fallback for the alert unit; FieldNode's candidate M12 pinout adopted.

### Documents changed

- `docs/01-problem.md` (SLW-PRB-001 v0.5)
- `docs/02-concept.md` (SLW-PRC-001 v0.6)
- `docs/03-requirements.md` (SLW-REQ-001 v0.6)
- `docs/05-build-plan.md` (SLW-BLD-001 v0.2)
- `docs/06-design-decisions.md` (SLW-DEC-001 v0.2)
- `docs/decisions/0001-trl2-review-decisions.md` (SLW-DDR-001 v0.3)
- `docs/decisions/0002-recommendations-accepted.md` (SLW-DDR-002 v0.2)
- `docs/decisions/0003-design-for-construction.md` (SLW-DDR-003 v0.2)
- `bom/bom-notes.md` (not a controlled document)
- `README.md` (not a controlled document)
- `docs/pdf/`: every controlled document re-rendered.

### Follow-up actions to carry approved decisions into the design

The model, drawings, build plan pictures, BOM quantities and prices, and calculations were not changed in this session. These actions carry the approved decisions into them:

1. Decision 3 (model): Add four wall holes to the alert unit back plate in cad/src/model.py; agree the same change for the FieldNode back plate with FieldNode (cross-repo).
2. Decision 3 (drawings): Alert unit back plate making sketch: add the four wall holes and a coach-screw fixing note; build plan picture of the back plate.
3. Decision 2 (calcs): SLW-CAL-001 [H2]: add the 60.3 mm mast case for site installations and state the local gust condition.
4. Decision 2 (bom): BOM line 8: add the 60.3 mm mast as the site-installation option and price it.
5. Decision 7 (docs): Firmware notes (TRL 4): run in logging-only mode until site thresholds are set by a geotechnical partner.
6. Decision 8 (bom): Price a second alert unit as an option for sites with running machinery.
7. Decision 9 (docs): Firmware notes (TRL 4): a fault message whenever a stake stops answering.
8. Decision 9 (bom): Add armoured bus cable as a priced option for rockfall zones.
9. Decision 10 (pictures): Build plan: recolour the stake head in the step and making pictures to signal amber with a retroreflective band, ID label and downslope arrow; same in the appearance model and renders.
10. Decision 10 (bom): BOM line 3: add the amber paint, retroreflective band and labels.
11. Decision 11 (bom): If FieldNode has not rated its 12 V rail before the TRL 4 build, add a small battery for the alert unit and price it.
12. Decision 12 (drawings): Build plan section 3.17 and the wiring diagram: show the M12 pin assignment (12 V on pin 1, bus on pins 2 and 4, keyed switch input on pin 5 of port B) and label the port with its rail voltage.
13. Decision 12 (docs): Cross-repo: ask FieldNode to adopt its candidate M12 pinout and to label each port with its rail voltage.
14. Decision 1 (pictures): At the next render session on Amish's Mac, redraw the photoreal renders, card and social preview to the constructable design (stake head, conduit fittings, cap screws).

### Points found in the review

Raised when the recommendations were written (2026-10-01) and not yet acted on:

- The value-engineering section prices the FieldNode core at USD 126; FieldNode's constructable design is now USD 139.
- Open decision 11 is already decided as a request to FieldNode (SLW-DDR-002, 2026-09-25); only the fallback is open.
- FieldNode publishes a 100 mW sensor allowance, while the SlopeWatch alarm draws 0.45 A at 12 V (about 5.4 W) while sounding; FieldNode's rating needs to cover alarm peaks as well as averages.
- Cross-repo with NoiseMap: ports set to different rail voltages (3.3 V and 12 V) need clear labels.

## Session 2026-10-02: approved follow-ups carried out

Amish approved on 2026-10-02 that every follow-up action from the open-decision sign-off be carried out. trl stays 3; nothing was built, bought or tested. `budget_usd` ($250) is unchanged.

### Follow-ups

1. Done. Decision 3, model: the alert unit back plate has four 6.5 mm wall holes (70 mm each side of the centre line, 45 mm in from each end) in `cad/src/model.py`, with checks for the holes and for the coach screw heads. STEP and STL regenerated; 88 of 88 constructability checks pass, including a check that every mount and clearance still holds on the 60.3 mm mast. The FieldNode back plate part is a cross-repo action (below).
2. Done. Decision 3, drawings: making sketch SLW-DWG-111 (Rev P2) and build plan section 3.11 show the wall holes and a coach-screw fixing note.
3. Done. Decision 2, calculations: SLW-CAL-001 v0.4 adds the 60.3 x 3.6 mm site mast [H2b] (332 N, 707 N m, 82 MPa, factor 2.9, 38 mm top deflection; footing factor 2.1 [H4b]) and the local gust condition [H2c]: the 48.3 mm mast has a factor of 2.0 at a 33 m/s gust, so it is acceptable only where the local 3 s design gust is below that; otherwise 60.3 mm.
4. Done. Decision 2, BOM: new line 11, the 60.3 mm site mast, $37.00 (pipe about $6.50 per metre for 3.75 m, top cap, footing, rod and clamps); an option outside every total, +$9.00 over line 8. Line 8 stays the prototype's 48.3 mm test-slope mast.
5. Not done: logging-only firmware mode is TRL 4 firmware work.
6. Done. Decision 8: line 12, second alert unit with LoRa receiver and battery, $64.00 (option, outside the totals).
7. Not done: the stake fault message is TRL 4 firmware work.
8. Done. Decision 9: line 13, armoured bus cable per 10 m across a rockfall zone, $38.00 (option).
9. Done. Decision 10, pictures: the model now carries the marking (25 mm retroreflective band on the cap skirt, 40 x 30 mm ID label on the -Y side of the head tube, downslope arrow on the crown); stake heads are signal amber in the overview, joints, steps and SLW-DWG-105 (Rev P2). The appearance model `cad/src/product_model.py` now builds the head from the model's reducer, pipe, end cap, two M20 conduit fittings and marking.
10. Done. Decision 10, BOM: line 3 now $13.50 a stake (was $11.00): amber paint about $0.60, retroreflective tape about 0.35 m at about $3.40 per metre ($1.20), ID label and arrow vinyl about $0.70.
11. Done. Decision 11: line 14, alert unit battery fallback, $20.00 (option; fitted only if FieldNode has not rated its 12 V rail before the TRL 4 build).
12. Done. Decision 12, drawings: section 3.17 and the wiring diagram (`bus.png`) show the port A pins (1 +5 V, 2 RS-485 A, 3 0 V, 4 RS-485 B) and the port B pins used by the alert unit (1 12 V, 3 0 V, 5 keyed switch input), and label each port with its rail voltage. I read the decision's "bus on pins 2 and 4" as the bus on port A, so the alert unit leaves pins 2 and 4 of port B unused.
13. Not done here (cross-repo, listed below).
14. Not done: photoreal renders, card and social preview are made on Amish's Mac. The render scenes are exported (see below).

### Results

- Requirement status changes: none (R11 value only).
- Value-engineering target: USD 250. Estimated cost of the constructable design: USD 304.00 for the SlopeWatch-specific parts of the reference site (USD 54.00 over the target); USD 332.00 where the 48.3 mm mast is needed; USD 430.00 with the FieldNode core.
- Also corrected: Table 4 in the precis and the build plan introduction carried the old cost; the label side moved to -Y so it faces the usual camera.

### Render scenes

`/home/claude/renders/slopewatch` (hero, exploded, detail; one .npz and .json each, and `slopewatch__jobs.json`). The appearance model already existed and was updated, not created.

### Cross-repo actions

- FieldNode: add the same four wall holes to the FieldNode back plate (SLW-DEC-001, 2026-10-02).
- FieldNode: adopt its candidate M12 pinout and label each port with its rail voltage (5 V port A, 12 V port B); SlopeWatch now draws it that way.
- NoiseMap: ports set to different rail voltages (3.3 V and 12 V) need the same labels.
- FieldNode: its 12 V rail needs a rating covering alarm peaks (0.45 A at 12 V for the siren), and its core is now USD 139, not the USD 126 on BOM line 6; line 6 was not changed because it is costed in the FieldNode project.

### Documents changed

`docs/02-concept.md` v0.7, `docs/03-requirements.md` v0.7, `docs/04-calcs/01-sizing.md` v0.4 (with `sizing.py` and `results.csv`), `docs/05-build-plan.md` v0.3, `docs/06-design-decisions.md` v0.3, `docs/decisions/0003-design-for-construction.md` v0.3, `README.md`, `bom/bom.csv`, `bom/bom-notes.md`, drawings SLW-DWG-001 (Rev P5), 105, 111 and 116 (Rev P2).

## 2026-10-02: photoreal renders redone on the constructable design

Rendered with Blender Cycles on Amish's Mac from the updated appearance model; captioned with `.kit/photo_caption.py`; `media/card.png` and `media/social-preview.png` regenerated with `.kit/cards.py`. Views: hero, exploded, detail. image_qc passes. Appearance deviations are those logged above as proposed, awaiting Amish.

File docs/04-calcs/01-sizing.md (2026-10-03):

---
doc_id: SLW-CAL-001
title: SlopeWatch sizing calculations
project: SlopeWatch
doc_type: Calculation
version: "0.4"
status: Draft
date: '2026-10-01'
author: Amish Chadha
license: CERN-OHL-S-2.0
revisions:
- version: "0.1"
  date: '2026-09-25'
  author: Amish Chadha
  change: First issue for TRL 3 (tilt resolution, temperature drift with pipe conduction, crack gauge, airtime and latency, alarm reach, energy and rail current, bus cable, mast wind load, installation, data, cost)
- version: "0.2"
  date: '2026-09-25'
  author: Amish Chadha
  change: Recommendations accepted by Amish (DDR-002)
- version: "0.3"
  date: '2026-10-01'
  author: Amish Chadha
  change: Re-run for the constructable design (SLW-DDR-003); crack gauge rod, side-mounted alert unit, hole depth, install time and cost updated; cost reported against the value-engineering target
- version: "0.4"
  date: '2026-10-02'
  author: Amish Chadha
  change: "Decisions of 2026-10-02 carried in: 60.3 mm site mast case and local gust condition [H2b, H2c], stake head marking and four site options priced (BOM lines 3, 11 to 14); cost re-run; no requirement changed status"
---

# SlopeWatch sizing calculations

On paper, SlopeWatch meets six of its thirteen requirements (four by calculation, two by design), has four at risk, misses none, leaves two that only a field trial can show, and is over its value-engineering target on cost (R11). This issue (v0.3) re-runs the calculations for the constructable design of SLW-DDR-003: the parts added to make the design buildable bring the reference site to $296.50, $46.50 over the $250 value-engineering target (v0.4, after the stake head marking decided on 2026-10-02: $304.00, $54.00 over), and the side-mounted alert unit lowers the optional mast's factor on yield from 2.1 to 1.7. It keeps Amish's decisions of 2026-09-25 (SLW-DDR-002): the reference site mounts the node on an existing pole, with a new mast as a site option; and the keyed silence switch moves to its own post about 5 m from the siren, which cuts the level there from about 105 to about 95 dB(A). The four at risk are the remote alert time at the slowest radio setting (R6), siren reach (R7), the FieldNode 12 V rail current during an alarm (R8) and the FieldNode enclosure temperature (R9). The v0.1 calculations changed four details of the TRL 2 concept: the sensor capsule moves from 0.3 m to 0.4 m deep, because at 0.3 m wet soil lets the daily temperature cycle through faster than R2 allows; the crack gauge gets its own RS-485 reader; the precaution beacon is limited to 1 % duty, because a 5 % slow flash would drain the cell in a long precaution spell; and the crack-gauge precaution rate is taken over 24 h. Every number here is printed by `docs/04-calcs/sizing.py`; the tag in brackets, for example [B5], is the line of that script's output that carries it.

> **Safety:** These are first-principles estimates for a paper proof of concept. They do not show that any slope is safe or that an alarm will come in time. SlopeWatch cannot warn of brittle failures, deep-seated movement or failures between its stakes. See SLW-PRC-001, Safety.

## Scope and method

The note checks every requirement in SLW-REQ-001 v0.5 against the design in SLW-PRC-001 v0.5, the constructable design of SLW-DDR-003 and the parametric model `cad/src/model.py`. The script imports the model's `PARAMS`, `SITE` and `derived()`, so the pipe, capsule depth, grout column, gauge, mast and cable run used here are the ones in the STEP files and in drawing SLW-DWG-001. It reads `bom/bom.csv` and `budget_usd` in `project.yaml`, and writes the results table to `docs/04-calcs/results.csv`. Run it from the repo root with `python docs/04-calcs/sizing.py`.

The design case is the reference site of SLW-REQ-001: three stakes 10 m apart on the fall line of a 25 degree face (20 m of face, 8.5 m of rise), a crack gauge 8 m above the top stake, and the node on an existing pole (or the optional mast) 15 m beyond the toe, with the keyed switch on its own post about 5 m from the siren, and ambient -10 to 50 °C at the surface.

## Assumptions

*Table 1. Main assumptions.*

| Area | Assumption | Basis |
| --- | --- | --- |
| Inclinometer | SCL3300-D01 in mode 1: ±90 degrees, noise density 0.0024 degrees per √Hz, angle output 0.0055 degrees per LSB; offset temperature drift ±0.005 degrees per K | Murata [datasheet](https://www.murata.com/-/media/webrenewal/products/sensor/pdf/datasheet/datasheet_scl3300-d01.ashx) and [product page](https://www.murata.com/en-us/products/sensor/inclinometer/overview/lineup/scl3300), both checked 2026-09-25 |
| Reading | Bus on for 12 s every 10 min: 2 s start-up and a 10 s average | Design choice |
| Soil temperature | Sinusoidal daily cycle; surface range 20 K in moist and wet soil, 30 K in dry soil; diffusivity 0.3, 0.6 and 1.0 mm²/s and conductivity 0.4, 1.0 and 1.6 W/mK for dry, moist and wet soil | Handbook ranges for mineral soils; to be confirmed at a site |
| Pipe heating | 160 mm of bare pipe between ground and head in full sun (900 W/m², absorptance 0.6), 10 W/m²K to air; steel 50 W/mK; buried pipe treated as a fin losing heat to the soil; steady state (no heat capacity), so an upper bound | Screening values |
| Crack gauge | 12-bit converter on a 100 mm potentiometer of 0.1 % linearity; steel rod and aluminum body see a 30 K daily range under the guard | Typical parts |
| Radio | LoRaWAN EU868, 125 kHz, coding rate 4/5, 20-byte payload plus 13 bytes of overhead; 45 mA at 3.3 V while transmitting; network server 5 s, alert service 30 s and SMS delivery 60 s | Semtech airtime formula; service times assumed |
| Siren | 110 dB(A) at 1 m; spherical spreading; air absorption 0.015 dB/m near 3 kHz; 0 to 3 dB excess ground attenuation | Typical 12 V piezo siren; order of magnitude from ISO 9613-1 |
| Energy | FieldNode cell 3.2 V, 6 Ah, 80 % usable, 85 % of capacity at -10 °C; rail converters 90 %; core 4 mWh/day (FND-CAL-001); capsule 6 mA and reader 5.5 mA at 5 V; siren 0.25 A and beacon 0.2 A at 12 V | FieldNode figures; parts typical; cold factor assumed |
| Wind | 35 m/s gust (735 Pa); drag coefficients 1.2 (panel, pole, alert unit) and 1.3 (boxes); medium soil 18 kN/m³, Kp = 3 | Screening values as in FND-CAL-001 and WWT-CAL-001; not a code check |

## A. Tilt measurement (R1)

- **Resolution and range.** The angle output steps by 0.0055 degrees in every mode. Mode 1 spans ±90 degrees; modes 3 and 4, the low-noise inclination modes, stop at ±10 degrees [A1], which would not meet the ±30 degree range of R1. The firmware must therefore use mode 1.
- **Noise.** A 10 s average in mode 1 has 0.00054 degrees of noise [A2]. A least-squares rate over 1 h (7 readings) has 0.00061 degrees per hour of noise, 164 times below the warning rate; over 3 h (19 readings) it is 74 times below the precaution rate [A3], [A4].
- **Meaning.** The warning rate of 0.1 degrees per hour is 1.75 mm per hour at 1 m from the pivot, and the precaution change over 3 h is 5.5 output steps [A5]. **R1 is met on paper.**

## B. Temperature drift of a buried capsule (R2)

The daily soil temperature wave shrinks with depth by exp(-z/d), where d is the damping depth, 91 to 166 mm for dry to wet soil [B2]. Heat also runs down the steel pipe from its sunlit exposed length, which absorbs 4.17 W in full sun [B1] and would sit up to 8.8 K above the soil at ground level [B3]; the buried pipe sheds that heat to the soil within about 0.1 m.

*Table 2. Daily temperature range at the capsule and apparent tilt, against R2 (0.02 degrees per day and 0.002 degrees per hour) [B2].*

| Capsule depth | Soil, surface range | Soil range at capsule | Added by pipe | Apparent tilt per day | Peak apparent rate | R2 |
| --- | --- | --- | --- | --- | --- | --- |
| 0.3 m | Dry, 30 K | 1.10 K | 1.36 K | 0.0123 degrees | 0.00161 degrees/h | Met |
| 0.3 m | Moist, 20 K | 1.94 K | 0.34 K | 0.0114 degrees | 0.00149 degrees/h | Met |
| 0.3 m | Wet, 20 K | 3.28 K | 0.13 K | 0.0170 degrees | **0.00223 degrees/h** | **Not met** |
| 0.4 m | Dry, 30 K | 0.37 K | 0.82 K | 0.0059 degrees | 0.00078 degrees/h | Met |
| 0.4 m | Moist, 20 K | 0.89 K | 0.15 K | 0.0052 degrees | 0.00068 degrees/h | Met |
| 0.4 m | Wet, 20 K | 1.79 K | 0.05 K | 0.0092 degrees | 0.00120 degrees/h | Met |

- **The TRL 2 depth misses R2 in wet soil.** Wet soil carries the daily wave deeper, and the peak apparent rate at 0.3 m exceeds 0.002 degrees per hour. At 0.4 m every case passes; the design case (wet soil) has a margin of 1.66 on the hourly limit and 2.18 on the daily limit, and the precaution threshold is 8.3 times the thermal rate [B5]. The capsule now sits 0.4 m deep, the depth R9 already names.
- **Pipe conduction matters in dry soil.** In dry soil the pipe adds more than the soil does (0.82 K against 0.37 K at 0.4 m), because dry soil conducts heat away poorly. The steel pipe still passes, so the TRL 2 question of steel or plastic pipe does not need a plastic pipe for R2. Closed-cell foam plugs above and below the capsule stop air in the pipe from carrying heat down.
- **Unburied, the sensor would fail.** At the surface the same sensor would show 0.100 degrees per day and 0.0131 degrees per hour [B4], above the precaution threshold every sunny day. The TRL 2 figures stand.
- **R2 is met on paper.** It rests on the handbook soil values and on a steady-state pipe model; rain soaking into warm ground can change soil temperature faster than a daily sine wave, which only site data can show.

## C. Crack gauge (R3)

- **Resolution.** A 12-bit reading of the 100 mm stroke steps by 0.0244 mm; the 0.1 % linearity class gives 0.10 mm of absolute error [C1]. The rate of opening, which drives the alerts, depends on repeatability rather than linearity. **R3 is met by design** (datasheet class); re-setting after 100 mm needs only an Allen key on a clamp block set screw.
- **Thermal swing.** The 501 mm steel extension rod and 260 mm aluminum body under the guard change length by 0.36 mm over a 30 K day, a peak apparent rate of 0.047 mm per hour [C2]. Over a 3 h window that reads as up to 1.13 mm per day, above the 1 mm per day precaution placeholder; over a 24 h window it cancels [C3]. The crack-gauge precaution rate is therefore taken over 24 h. The 1 mm per hour warning placeholder is 21 times the thermal rate, and at that rate the stroke lasts 100 h [C4].
- **Reader.** The gauge sits about 60 m of cable from the node, too far for a clean analog signal on a cable shared with the RS-485 bus. It gets the capsule's board without the inclinometer, in a small IP67 box (BOM line 4, +$6).

## D. Sampling, airtime and alert latency (R4, R5, R6)

- **Airtime.** A 20-byte uplink takes 72 ms at SF7, 247 ms at SF9, 453 ms at SF10 and 1,810 ms at SF12 [D1]; the TRL 2 figures of 0.4 s and 1.5 s were low. Six uplinks an hour use 0.08 % of the time at SF10 and 0.30 % at SF12, within the 1 % EU868 limit [D2]. **R4 is met on paper.**
- **Fair use.** On a private TwinKit gateway only the duty cycle applies. On The Things Network, whose fair-use policy allows 30 s a day, hourly uplinks fit at SF9 and SF10 (5.9 s and 10.9 s) but not at SF12 (43.5 s), and 10 min uplinks in the precaution or warning state exceed it from SF10 upward (65.2 s at SF10) [D3]. An alert state is short, but a site that lives at SF12 on The Things Network exceeds fair use, so under SLW-DDR-002 such a site uses its own TwinKit gateway.
- **Local alarm.** From the start of the reading that confirms a warning to the siren takes 13.4 s: bus start-up, the 10 s average, polling four devices and the decision [D4]. **R5 is met by design** (60 s).
- **Remote alert.** Warning to SMS takes 95 to 97 s at the first try. If that uplink is lost, the duty-cycle wait before a retry is 45 s at SF10 and 179 s at SF12, giving 141 s (2.3 min) and 278 s (4.6 min) [D5]. **R6 is at risk**: met on paper where coverage exists, with little margin at SF12. A site without LoRaWAN coverage needs a gateway (TwinKit, about $290 in parts) or gets no remote alert.

## E. Alarm reach (R7)

- **Open ground.** The siren gives 65.5 to 68.5 dB(A) at 100 m [E1] and reaches 65 dB(A) out to about 105 to 139 m [E2]. **R7 is at risk**: met in open, quiet ground with 0.5 dB to spare over soft ground, before any allowance for a siren that falls short of its rating or for wind.
- **Near machinery.** Against 80 dB(A) of running plant, an alarm 15 dB above ambient reaches only about 5 m [E3]. Sites with machinery need a second alert unit at the work face or a radio pager for operators (D7 option).
- **Close range.** The siren now sits on the side-mounted alert box, its centre 3.23 m above ground on the mast (SLW-DDR-003; 3.26 m before). A switch box on the mast, as in v0.1, would sit at about 106 dB(A), and 2 m from the mast the level is about 102 dB(A); at 106 dB(A) the NIOSH limit allows about 4 min [E4]. Under SLW-DDR-002 the keyed switch stands on its own post about 5 m from the mast, on a 7 m lead, where the level is 95.5 dB(A) and the NIOSH allowance about 42 min [E5]. Silencing takes seconds; people should still not stand at the mast during an alarm.

## F. Energy and rail current (R8)

- **Sensor load.** The bus draws 1.44 J per reading, 2.67 mW average from the cell, or 0.064 Wh per day [F1]. The TRL 2 figure of under 1 mW assumed 2 s of power per reading; the 10 s average raises it, still far below the FieldNode 100 mW sensor allowance.
- **Uplinks.** Hourly uplinks sit inside the FieldNode core budget, which assumes a 15 min report. Uplinks every 10 min at SF12 add 10.8 mWh per day [F2].
- **Alarm.** The siren and beacon take 5.4 W at 12 V, 6.0 W from the cell: 3.00 Wh for a 30 min alarm, plus 0.67 Wh for a 30 min silenced period with the beacon flashing at 50 % [F3].
- **Precaution beacon.** A slow flash at 5 % duty would cost 3.20 Wh per day; at 1 % it costs 0.64 Wh per day [F4]. Five sunless days in precaution with one alarm need 20.06 Wh at 5 % duty, more than the 13.06 Wh the cell holds at -10 °C, but 7.26 Wh (56 %) at 1 % duty [F5], [F7]. The beacon's slow flash is therefore limited to 1 % duty (for example 100 ms every 10 s). In the normal state the same five days with one alarm need 4.01 Wh [F6]. The average load in precaution is 29.8 mW, within the FieldNode 100 mW allowance [F8].
- **Rail current.** The alarm draws 0.45 A from the 12 V rail and 2.00 A from the cell at 3.0 V (0.33 C, within the 5 A cell fuse) [F9]. FieldNode does not state the 12 V rail's current rating. **R8 is met on energy and at risk on the rail current** until FieldNode specifies at least 0.5 A continuous on its 12 V rail. Under SLW-DDR-002 that request goes to FieldNode (a cross-repo action), rather than giving the alert unit its own battery.

## G. Sensor bus cable (R4, R9)

- **Length.** The reference layout needs 53.8 m of cable, 59.2 m with 10 % slack, within the 60 m in the BOM [G1].
- **Voltage drop.** The 0.5 mm² loop measures 4.07 Ω; with all 23.5 mA drawn at the far end it drops 0.096 V of the 5 V rail, leaving 1.30 V above the capsule regulators' need [G2]. The bus uses the FieldNode 5 V port rather than 12 V, because the capsules' linear regulators would waste more than half the power at 12 V. RS-485 over 59 m is far inside its 1,200 m class limit [G3].
- **Ports.** The bus (5 V, ground, A, B) takes one FieldNode M12 5-pin port. The alert unit takes the other: 12 V, ground, siren drive, beacon drive and the silence switch, which fits FieldNode's one-rail-per-port rule (FND-DDR-001). The FieldNode pinout itself is still open (FND-DDR-001, O2).

## H. Mast in wind

- **Loads.** The mast is a site option (SLW-DDR-002); where it is used, a 35 m/s gust puts 51 N on the panel, 29 N on the node enclosure, 81 N on the alert box, horn, beacon and the part of its back plate below the box, and 136 N on the mast: 298 N and a base moment of 653 N·m [H1]. The switch box is no longer on the mast. The side-mounted alert unit of SLW-DDR-003 adds its back plate to the wind area, which v0.2 (48 N, 541 N·m) did not count.
- **Mast.** The 48.3 x 3.2 mm pipe sees 136 MPa, a factor of 1.7 on the 235 MPa yield [H2], and deflects 79 mm at the top [H3]. The alert unit on the mast adds about 70 % to the base moment of a node alone. An existing pole must carry the same loads; the installer checks it by eye and with the site owner.
- **Site mast, 60.3 mm.** Decided on 2026-10-02 (SLW-DEC-001): any site installation uses a 60.3 x 3.6 mm galvanized pipe mast unless local gust data show winds well below 35 m/s. In the same gust the larger pipe adds wind area (332 N, 707 N·m at the base) but has a section modulus of 8.58 cm³, so the stress is 82 MPa, a factor of 2.9 on yield, and the top deflects 38 mm [H2b]. Stress grows with the square of the gust: the 48.3 mm mast reaches yield at 46 m/s and has a factor of 2.0 at 33 m/s, so it is acceptable only where the local 3 s design gust is below 33 m/s; the 60.3 mm mast reaches yield at 59 m/s [H2c]. The prototype's 48.3 mm mast (factor 1.7) stays for the fenced test slope with no one under the mast in high wind. The V-blocks and band clamps fit both pipes (all constructability checks pass again on 60.3 mm).
- **Footing.** The 320 mm by 600 mm footing resists 668 N sideways in medium soil, a factor of 2.2 under the 48.3 mm mast and 683 N, a factor of 2.1, under the 60.3 mm mast [H4, H4b]. Soft or wet ground needs a site check. This is not a code check.
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

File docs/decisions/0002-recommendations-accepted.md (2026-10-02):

---
doc_id: SLW-DDR-002
title: SlopeWatch recommendations accepted
project: SlopeWatch
doc_type: Design decision record
version: "0.2"
status: Draft
date: '2026-10-02'
author: Amish Chadha
license: CERN-OHL-S-2.0
revisions:
- version: "0.1"
  date: '2026-09-25'
  author: Amish Chadha
  change: Record the recommendations accepted by Amish on 2026-09-25, what changed in the repo, and the items still open
- version: "0.2"
  date: '2026-10-02'
  author: Amish Chadha
  change: O1 to O3 decided by Amish on 2026-10-02 (recommendations approved, SLW-DEC-001)
---
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

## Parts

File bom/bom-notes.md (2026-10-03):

# BOM notes

- Every line is priced in indicative USD for one reference site (three tilt stakes 10 m apart, one crack gauge, 60 m of bus cable, node on an existing pole; line 8 mast priced as a site option), with a supplier or supplier type. Prices are not quotes.
- Line numbers match the numbered callouts in `media/exploded.png`. Lines 9 and 10 have no callout.
- Line 6 (FieldNode core, $126) is the lab's shared node, costed in the FieldNode project under SLW-DDR-001 D1 (decided by Amish, 2026-09-25, SLW-DDR-002). It is listed for completeness and is not counted against the SlopeWatch budget.
- Reference site (SLW-DDR-002): the node and alert unit go on an existing pole, so line 8 (mast and footing, $28; the prototype's 48.3 mm test-slope mast) is a site option outside the reference-site cost. `budget_usd` ($250) is a hypothetical value-engineering target, not a limit. Value-engineering target: USD 250. Estimated cost of the constructable design: USD 304.00 for the SlopeWatch-specific parts of the reference site (USD 54.00 over the target); $332.00 at a site that needs the 48.3 mm mast. With the FieldNode core the reference site comes to $430.00. `docs/04-calcs/sizing.py` sums the file and checks it against `project.yaml`.
- DDR-002 change: line 7 now includes a 26.9 mm post and a 7 m lead in conduit, so the keyed silence switch stands about 5 m from the siren (+$8, from $25 to $33).
- TRL 3 changes: line 4 adds a reader board and box (+$6), because the gauge is about 60 m of cable from the node; line 10 adds foam plugs for the capsule (+$1); line 2 specifies the SCL3300-D01 in mode 1 and a 0.4 m capsule depth; line 8 adds the earth rod to the description at no change in price.
- A LoRaWAN gateway is not included. Sites without coverage need one (TwinKit, about $290 in parts per its TRL 3 BOM).
- Design for construction (SLW-DDR-003, 2026-10-01): line 1 adds the screwed end cap and stand tube ($9 to $13); line 2 the centring collars ($27 to $27.50); line 3 becomes a head from stock drainage fittings with two conduit fittings and lever connectors ($5 to $11); line 4 adds clamp blocks, ball joints, a rod coupling, a folded guard and pegs ($38 to $46); line 7 adds the alert unit's back plate, V-blocks and band clamps and the switch back plate and hose clips ($33 to $43); line 8 adds a top cap and bonding clamps ($24 to $28); line 10 adds tape and a field-wireable plug ($9 to $11). The reference site rises from $245.00 to $296.50.
- Decided on 2026-10-02 (SLW-DEC-001) and now in `bom.csv`: line 3 stake heads in signal amber with a 25 mm retroreflective band, a stake ID label and a downslope arrow (+$2.50 a stake, $11.00 to $13.50); four 6.5 mm wall holes in the alert unit back plate (no change in price); line 5 and line 7 name the M12 pin assignment (port A pins 1 to 4, port B pins 1, 3 and 5). Lines 11 to 14 are site options priced on the same day and outside every total: 11 the 60.3 mm site mast ($37.00, replacing line 8 at a site installation, +$9.00), 12 a second alert unit at a machinery site ($64.00), 13 armoured bus cable per 10 m across a rockfall zone ($38.00), 14 an alert unit battery if FieldNode has not rated its 12 V rail ($20.00).

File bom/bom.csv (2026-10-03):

item | qty | spec | supplier | unit_cost_usd | make_buy | notes
1 Tilt stake | 3 | 48.3 x 3.2 mm galvanized steel pipe (1.5 in nominal), 1.0 m long, threaded at the bottom end; screwed 1.5 in malleable-iron end cap; 0.8 m in ground in a 110 mm augered hole 0.83 m deep; lower 450 mm in a hand-mixed cement grout column (about 3.7 L); 40 mm PVC pressure pipe stand tube about 335 mm long inside, setting the capsule depth | Local hardware store and builders' merchant | 13.00 | make | Indicative price per stake (pipe about $6; end cap about $3; grout about $3; stand tube about $1); end cap and stand tube added under SLW-DDR-003; steel kept (SLW-CAL-001 section B)
2 Tilt sensor capsule | 3 | Murata SCL3300-D01 MEMS inclinometer (mode 1), small low-power microcontroller, RS-485 transceiver and 3.3 V LDO on one board; potted in a 34 x 130 mm sealed tube, IP67 target; two 3D-printed ASA centring collars (41.5 mm OD, 15 mm long); set 0.4 m deep on the stand tube under a closed-cell foam plug | Electronics distributor (DigiKey or Mouser class) | 27.50 | make | Indicative price per capsule (sensor about $18; board parts about $6; tube and potting about $3; collars about $0.50); collars added under SLW-DDR-003
3 Stake head | 3 | Stake head from stock PVC drainage fittings: 110 x 50 mm concentric reducer (50 mm socket over the pipe on a self-amalgamating tape wrap), 94 mm of 110 mm pipe, 110 mm end cap; two M20 IP66 conduit fittings for 20 mm corrugated conduit (bus in upslope, bus out downslope); three 5-way lever connectors inside; two M5 x 16 stainless self-tapping screws into the pipe; painted signal amber (about 0.1 L of paint per head), with a 25 mm retroreflective band round the head, a printed UV-stable vinyl stake ID label and a vinyl downslope arrow on the crown | Local hardware store | 13.50 | buy | Indicative price per stake (reducer, pipe and cap about $5; two conduit fittings about $3; lever connectors about $2.50; screws about $0.50; amber paint about $0.60, band about 0.35 m of retroreflective tape at about $3.40 per metre = $1.20, ID label and arrow vinyl about $0.70, added under SLW-DEC-001, 2026-10-02); replaces the 120 mm cap, reducer ring and single gland (SLW-DDR-003)
4 Crack displacement gauge with reader | 1 | 100 mm stroke linear potentiometer displacement sensor (0.1 % linearity class) with an M6 rod-end ball joint at each end; 8 mm steel extension rod threaded M6 both ends with a coupling to the plunger; two 20 mm steel anchor pins 0.7 m long; two 40 x 40 x 60 mm aluminium clamp blocks, each with an M8 set screw and an M6 ball-joint stud; guard folded from 1.5 mm galvanized sheet (1,150 x 200 x 250 mm with foot flanges) pegged with four 8 mm x 300 mm ground pegs; reader board (capsule board without the inclinometer: 12-bit converter and RS-485) in an 80 x 60 x 45 mm IP67 box under the guard with a conduit fitting | Electronics distributor plus local fabricator | 46.00 | make | Indicative price (sensor with ball joints about $24; pins, rod and coupling about $5; clamp blocks about $4; guard sheet and pegs about $7; reader board, box and fitting about $6); clamp blocks, ball joints, folded guard and pegs specified under SLW-DDR-003; reader added at TRL 3 because the gauge is about 60 m of cable from the node (SLW-CAL-001 section C)
5 Sensor bus cable in conduit | 1 | 60 m four-core shielded outdoor cable, 0.5 mm2 (5 V, ground, RS-485 A and B), in 20 mm corrugated UV-rated conduit; one M12 5-pin plug for FieldNode port A (pin 1 +5 V, pin 2 RS-485 A, pin 3 0 V, pin 4 RS-485 B) | Electrical wholesaler | 42.00 | buy | Indicative price for the reference site (cable about $27; conduit about $15); 59.2 m needed by SLW-CAL-001 section G
6 FieldNode core | 1 | Lab shared node: IP65 enclosure, 6 W panel, LiFePO4 3.2 V 6 Ah, MPPT charger, STM32WL-class LoRaWAN radio, switched 3.3, 5 and 12 V rails on two M12 ports; pole mounting kit | FieldNode project (FND bom/bom.csv) | 126.00 | make | Costed in the FieldNode project and not in the SlopeWatch budget (SLW-DDR-001 D1); listed for completeness
7 Siren and beacon alert unit | 1 | 12 V piezo siren about 110 dB(A) at 1 m, 12 V amber LED beacon (about 0.2 A), two-channel MOSFET driver in a 120 x 90 x 120 mm IP65 alert box with two M16 glands; box on a 160 x 360 x 3 mm aluminium back plate with four 6.5 mm wall holes for coach screws (70 mm each side of the centre line, 45 mm in from each end) and with two V-blocks (60 x 33 x 20 mm aluminium) and two 12 mm stainless band clamps for a 40 to 70 mm pole or the mast; lead with M12 5-pin plug for FieldNode port B (pin 1 12 V, pin 3 0 V, pin 5 keyed switch input; pins 2 and 4 unused by the alert unit); keyed silence switch in a 100 x 60 x 70 mm IP65 box on a 100 x 160 x 3 mm galvanized back plate held by two hose clips to its own 26.9 mm galvanized post (1.4 m above ground, 0.5 m driven, plastic top cap) about 5 m from the mast, on a 7 m two-core outdoor lead in conduit | Electronics distributor plus local hardware store | 43.00 | buy | Indicative price (siren, beacon, driver, switch and boxes about $25; back plate, V-blocks and band clamps about $8; switch post, cap, back plate and hose clips about $6; lead and conduit about $4); side mounting and switch back plate added under SLW-DDR-003; switch moved off the mast under SLW-DDR-002 (about 95 dB(A) there instead of about 105 dB(A)); wall holes at no change in price (SLW-DEC-001)
8 Mast and footing | 1 | 48.3 x 3.2 mm galvanized pipe, 3.2 m above ground plus 0.55 m in a 320 mm x 0.6 m concrete footing; push-on top cap; 16 mm x 1.2 m earth rod with a rod clamp, a pipe bonding clamp and a 16 mm2 green and yellow bond conductor | Local hardware store and builders' merchant | 28.00 | make | Site option and the mast of the first prototype on a fenced test slope (factor 1.7 on yield, accepted 2026-10-02), not in the reference-site cost (SLW-DDR-002): the reference site mounts the node and alert unit on an existing 40 to 70 mm pole; this mast is added only where none exists. Top cap and bonding clamps added under SLW-DDR-003 (+$4). Indicative price; sites that are installed for use take the 60.3 mm mast of line 11 instead
9 Gateway and alert software | 1 | Any LoRaWAN network server (TwinKit gateway or The Things Network); open alert service with SMS and inverse-velocity plot | Open source | 0.00 | make | Not in site cost; a TwinKit gateway is about $290 in parts where a site has no coverage; no exploded-view callout
10 Hardware and consumables | 1 | Cable ties, conduit clips with ground pegs, heat-shrink, dielectric grease, surge protector at the node port, marking tape, closed-cell foam backer rod for the capsule plug, self-amalgamating tape for the stake heads, field-wireable M12 5-pin plug for the bus | Local hardware store | 11.00 | buy | Indicative price; foam plug added at TRL 3; tape and field-wireable plug listed under SLW-DDR-003 (+$2); no exploded-view callout
11 Site mast, 60.3 mm option | 1 | 60.3 x 3.6 mm galvanized pipe (2 in nominal), 3.2 m above ground plus 0.55 m in the same 320 mm x 0.6 m concrete footing; push-on top cap; 16 mm x 1.2 m earth rod with a rod clamp, a pipe bonding clamp and a 16 mm2 green and yellow bond conductor; the node and alert unit V-blocks and 12 mm band clamps fit it unchanged | Local hardware store and builders' merchant | 37.00 | make | Site option, replaces line 8 at any site installation unless local gust data show winds well below 35 m/s (SLW-DEC-001, 2026-10-02; SLW-CAL-001 [H2b]); not in the totals. Pipe about $6.50 per metre for 3.75 m (about $24) against about $17 for the 48.3 mm pipe; top cap about $2; footing, rod and clamps about $11. Indicative price
12 Second alert unit option | 1 | Second alert unit at the work face of a site with running machinery, linked by LoRa: 12 V piezo siren and amber beacon with MOSFET driver in an IP65 alert box on a 160 x 360 x 3 mm back plate with two V-blocks and band clamps; LoRa receiver board with antenna in an IP65 box; 12 V 7 Ah sealed lead-acid battery with a charger input and fuse | Electronics distributor plus local hardware store | 64.00 | buy | Option for sites with running machinery (SLW-DEC-001, 2026-10-02); not in the totals. Indicative price: siren, beacon, driver and box about $24, back plate, V-blocks and clamps about $8 (together about the $32 of line 7 without the switch), LoRa receiver board, antenna and box about $16, battery and fuse about $16
13 Armoured bus cable option, per 10 m | 1 | 10 m of four-core 0.5 mm2 steel-wire-armoured outdoor cable, with two armour glands, laid in place of the conduit across a rockfall zone; ends joined to the conduit at the lever connectors or an IP67 junction box | Electrical wholesaler | 38.00 | buy | Option, one unit per 10 m of rockfall zone (SLW-DEC-001, 2026-10-02); not in the totals. Indicative price: cable about $3.40 per metre ($34, against about $4.50 for the same 10 m of plain cable and conduit it replaces, which is not credited), two glands about $4
14 Alert unit battery option | 1 | 12 V 2.3 Ah sealed lead-acid battery, fuse holder with a 5 A fuse and a small 12 V charge regulator board, in the alert box or a small IP65 box beside it | Electronics distributor | 20.00 | buy | Fallback only if FieldNode has not rated its 12 V rail (0.5 A continuous) before the TRL 4 build (SLW-DEC-001, 2026-10-02); not in the totals. Indicative price: battery about $11, fuse holder and fuse about $2, charge regulator board about $7

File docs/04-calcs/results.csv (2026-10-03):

id | requirement | value | target | status
R6 | Remote alert | 4.6 min worst at SF12 with one lost uplink | 5 min, where coverage exists | At risk
R7 | Alarm audible | 65.5 to 68.5 dB(A) at 100 m | 65 dB(A) at 100 m | At risk
R8 | Energy autonomy | 7.3 Wh of 13.1 Wh worst case; 12 V rail 0.45 A unrated | 5 days, one 30 min alarm | At risk
R9 | Survive burial and weather | Capsule and gland IP67 by parts; FieldNode interior above 60 C in 45 C sun (FND-CAL-001) | IP67 at 0.4 m; -10 to 50 C | At risk
R1 | Measure surface tilt | 0.0055 deg step, 0.00054 deg noise, +-90 deg in mode 1 | 0.01 deg, +-30 deg | Met on paper
R2 | Limit false tilt from temperature | 0.0092 deg/day, 0.00120 deg/h (wet soil, 0.4 m) | 0.02 deg/day, 0.002 deg/h | Met on paper
R4 | Sample and report | 10 min reads; 10.9 s/h at SF12 | 10 min; 60 and 10 min uplinks | Met on paper
R12 | Open, local data | 363 kB for 90 days | 90 days, CSV, any server | Met on paper
R11 | Affordable | $304.00 for the reference site (existing pole); $332.00 with the optional new mast | $250 value-engineering target, SlopeWatch-specific, reference site | Over the value-engineering target by $54.00
R3 | Measure crack opening | 100 mm stroke, 0.024 mm step, 0.10 mm linearity | 100 mm, 0.1 mm | Met by design
R5 | Local alarm without a network | 13 s | 60 s | Met by design
R10 | Installable by a small team | 44 min estimate | 45 min, hand tools | Not verifiable at TRL 3
R13 | Trustworthy alarms | Needs a field record | 1 false warning per year | Not verifiable at TRL 3

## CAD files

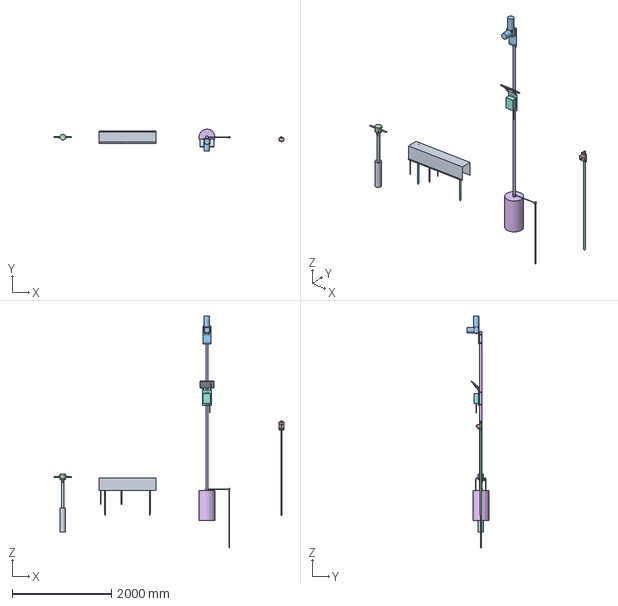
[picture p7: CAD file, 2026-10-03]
cad/step/slopewatch-arrangement.step
4628.0 x 434.9 x 4660.0 mm

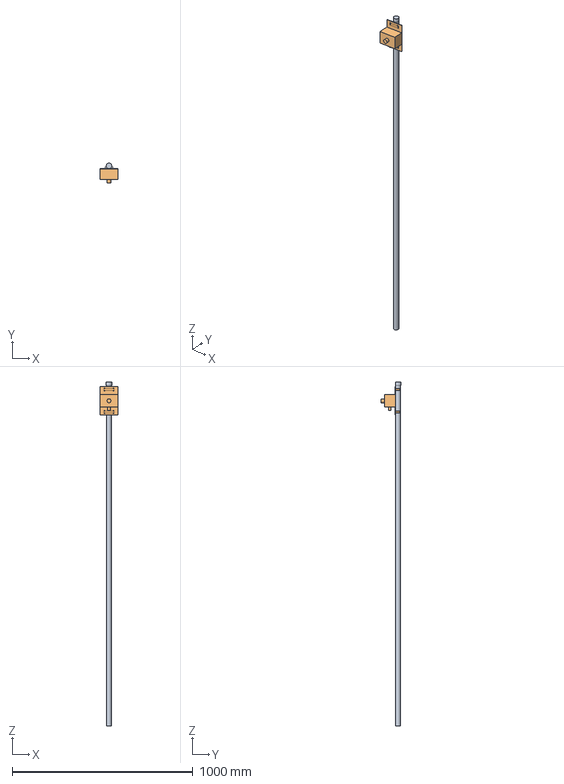
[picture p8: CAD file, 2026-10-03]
cad/step/slopewatch-switch-post.step
100.0 x 109.9 x 1904.0 mm

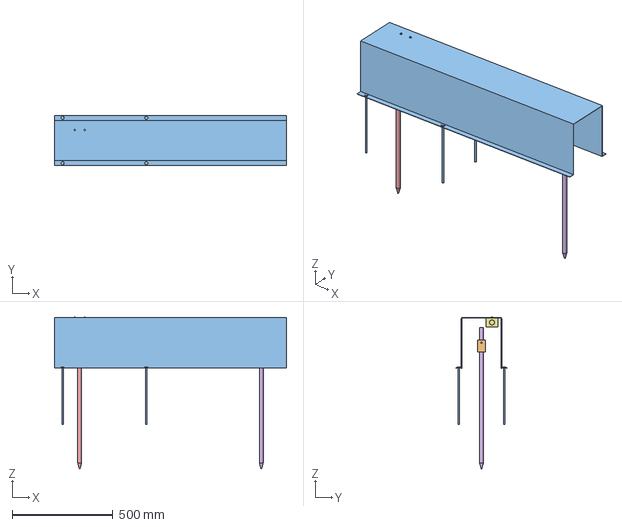
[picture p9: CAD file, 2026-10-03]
cad/step/slopewatch-crack-gauge.step
1150.0 x 250.0 x 753.0 mm

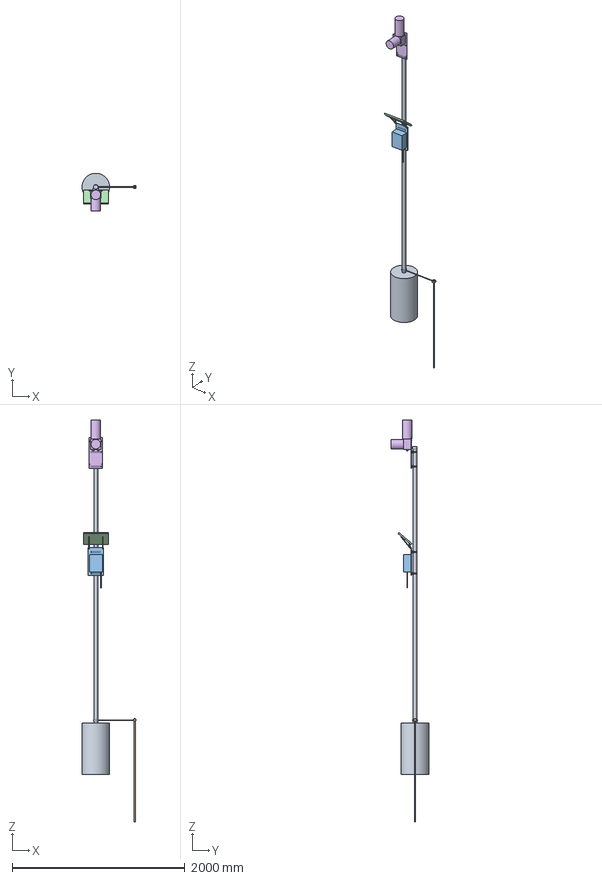
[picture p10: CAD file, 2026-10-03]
cad/step/slopewatch-mast.step
624.7 x 434.9 x 4660.0 mm

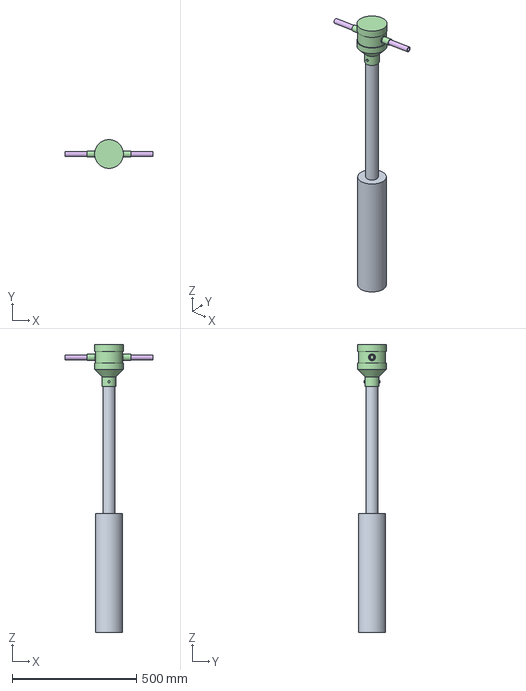
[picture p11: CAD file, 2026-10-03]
cad/step/slopewatch-stake.step
356.0 x 115.9 x 1159.0 mm

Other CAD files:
cad/stl/slopewatch-arrangement.stl
cad/stl/slopewatch-crack-gauge.stl
cad/stl/slopewatch-mast.stl
cad/stl/slopewatch-stake.stl
cad/stl/slopewatch-switch-post.stl

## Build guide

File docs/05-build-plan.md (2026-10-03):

---
doc_id: SLW-BLD-001
title: SlopeWatch prototype build plan
project: SlopeWatch
doc_type: Build plan
version: "0.3"
status: Draft
date: '2026-10-02'
author: Amish Chadha
license: CERN-OHL-S-2.0
revisions:
  - version: "0.1"
    date: '2026-10-01'
    author: Amish Chadha
    change: First build plan from the template, with pictures by component and step; design made constructable (SLW-DDR-003)
  - version: "0.2"
    date: '2026-10-02'
    author: Amish Chadha
    change: "Decisions of 2026-10-02 carried in: stake head marking, mast conditions in stop S5, logging only until thresholds are set in stop S7"
  - version: "0.3"
    date: '2026-10-02'
    author: Amish Chadha
    change: "Decisions carried into the pictures and text: wall holes in the alert unit back plate, the 60.3 mm site mast, the port pin assignment and rail voltages, stake head marking and its pictures; cost figures from SLW-CAL-001 v0.4"
---

# SlopeWatch prototype build plan

**Plan, not yet built.** How to build the first proof-of-concept prototype, component by component. Building and testing to it is TRL 4 work. Decisions still to be made are kept in the design decisions register ([docs/06-design-decisions.md](06-design-decisions.md)), not here.

## 1. What you are building

Figure 1. Every component, pulled apart and numbered in build order

*Figure 1. Every component of one site kit pulled apart and numbered in build order. One of the three tilt stakes is shown; the mast and the switch post are drawn shortened.*

The prototype is one site kit for a slope: three tilt stakes grouted into the slope, each holding a sealed tilt sensor capsule 0.4 m below ground; a crack gauge across a tension crack at the crest; one cable in conduit joining them to a FieldNode core on a pole at the toe; a siren and beacon alert unit clamped to the same pole; and a keyed silence switch on its own post about 5 m away. Figure 1 shows the 20 components in the order you make or fit them, and Figure 2 shows where each goes on the slope. The made parts are cut and drilled steel pipe and bar, a printed collar, potted capsules, stake heads assembled from stock drainage fittings, a machined aluminium clamp block, a folded steel guard and three flat plates; the boxes are bought and drilled, and the FieldNode core is built to its own plan. The work is sawing, drilling, tapping and filing steel and aluminium, one 3D print, potting electronics, augering and grouting, and wiring at screw and lever terminals. The SlopeWatch parts cost about $304 for the reference site, from the bill of materials.

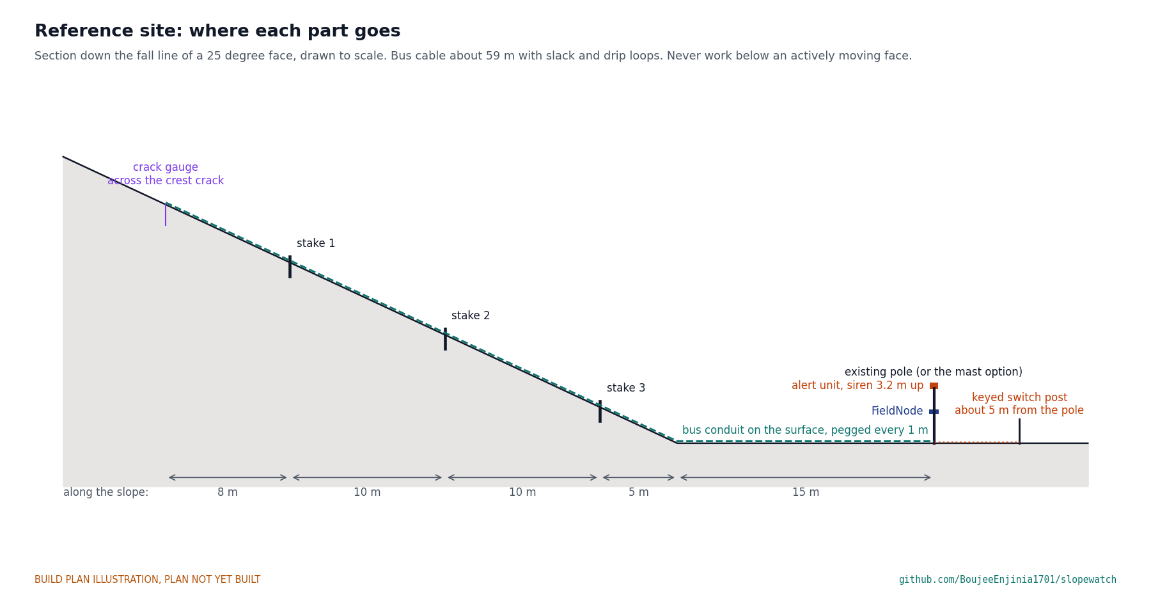
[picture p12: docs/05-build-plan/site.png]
Figure 2. Reference site layout


*Figure 2. Where each part goes on the reference site, along the fall line.*

> **Safety:** Installing on a slope that may already be moving is the main hazard. Work only with a trained team after a competent person has looked at the slope, never below an actively moving face or overhanging material, never on a tailings dam without the owner's permit and the engineer of record's agreement, and stop in or after heavy rain. Wet cement grout burns skin and eyes: wear gloves and eye protection. The siren gives about 110 dB(A) at 1 m: wear hearing protection when testing it. The FieldNode core holds a lithium iron phosphate cell: follow the safety stops in its own build plan. A silent siren is not proof of a safe slope.

## 2. What changed to make it buildable

The concept showed what SlopeWatch does; several of its parts could not be made or fixed as drawn. Each change below keeps what the system does, and all of them are recorded in decision record SLW-DDR-003, accepted by Amish on 2026-10-02.

*Table 1. Changes from the concept.*

| Component | The concept had | The buildable design has | Why |
| --- | --- | --- | --- |
| Sensor capsule | Loose in the pipe between two foam plugs, 4 mm from the wall | Two printed collars that hold it on the pipe axis, resting on a plastic stand tube that sets its depth (Figure 8) | The capsule must tilt with the pipe; the stand tube sets 0.4 m without measuring down a hole |
| Pipe bottom | An unspecified internal plug | A screwed iron end cap, with grout under it (Figure 4) | A stock fitting that keeps grout and water out |
| Stake head | A 120 mm cap on a ring that is not sold, with no fixing | A head made from stock 110 mm drainage fittings, sealed on a tape wrap and held by two screws (Figure 10) | Every part can be bought; the head cannot be lifted off |
| Bus at each stake | One cable gland | Two conduit fittings, bus in upslope and bus out downslope, joined inside the head (Figure 11) | The bus has to pass through every stake |
| Crack gauge fixings | Solid blocks round the pins, with nothing holding the sensor | Clamp blocks with set screws, ball joints and a coupled extension rod (Figures 14, 16, 17) | The crack can open, close or shear without bending the sensor |
| Crack gauge guard | Passed through the pins and floated above the ground | A folded channel on feet, pegged on its upslope half (Figure 19) | Clears the gauge; the crack can open under it |
| Reader box | Floated beside the gauge | Hangs under the guard web (Figure 19) | Protected and fixed |
| Alert unit | Stood loose on the open top of the mast | A box on a back plate clamped to the pole with V-blocks and band clamps, like the FieldNode core (Figures 23, 25) | Works on an existing pole as well as on the mast |
| Keyed switch | Floated beside its post | A back plate held to the post by two hose clips (Figure 28) | Fixed without drilling the post |
| Mast earth bond | No clamps | A rod clamp, a mast bonding clamp and a bond conductor (Figure 30) | The usual way to bond a mast |

## 3. Making the components

Make and check each component before the assembly step that needs it. Sizes are in millimetres. "Upslope" and "downslope" are along the fall line of the slope. Workshop tolerance is 0.5 mm unless a step says otherwise; drawings do not carry tolerances before TRL 4. Make three of every stake part (sections 3.1 to 3.5), one for each stake.

### 3.1 Stake pipe with end cap (make 3)

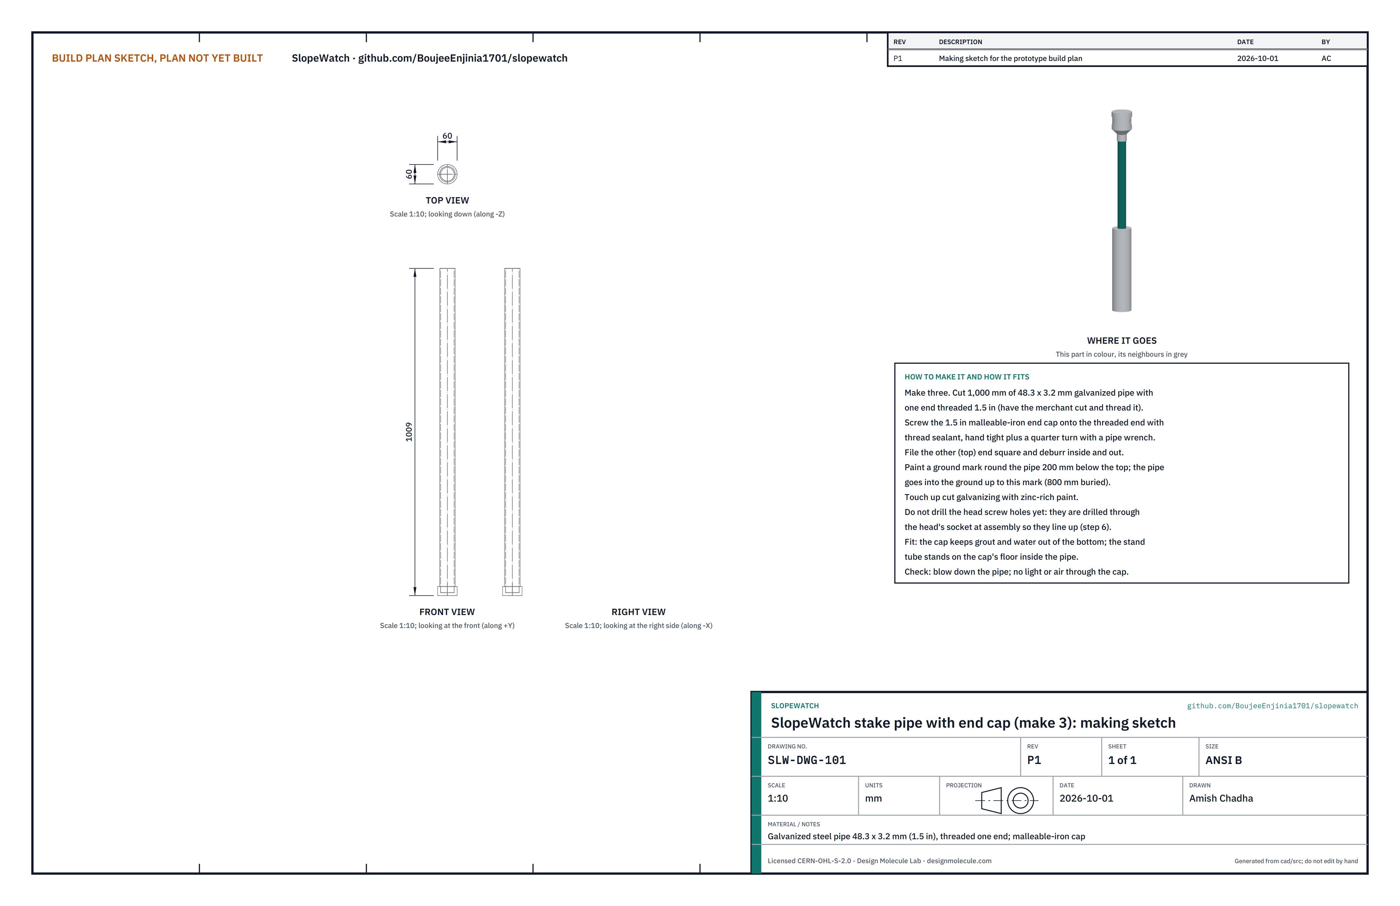
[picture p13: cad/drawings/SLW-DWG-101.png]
Figure 3. Making sketch of the stake pipe


*Figure 3. Stake pipe making sketch (SLW-DWG-101).*

**What it is and what it is made from.** The steel tube that is grouted into the slope and tilts with it. Galvanized steel pipe 48.3 mm outside and 3.2 mm wall (1.5 in), 1,000 mm long, threaded at the bottom end, with a screwed 1.5 in malleable-iron end cap.

**How to make it.**

1. Have the merchant cut 1,000 mm of pipe and thread one end 1.5 in.
2. Screw the end cap onto the threaded end with thread sealant, hand tight plus a quarter turn with a pipe wrench.
3. File the top end square and deburr it inside and out.
4. Paint a ground mark round the pipe 200 mm below the top. The pipe goes into the ground up to this mark, 800 mm deep.
5. Touch up the cut galvanizing with zinc-rich paint.
6. Do not drill the head screw holes yet; they are drilled through the head at step 6 so they line up.

**How it fits the parts next to it.**

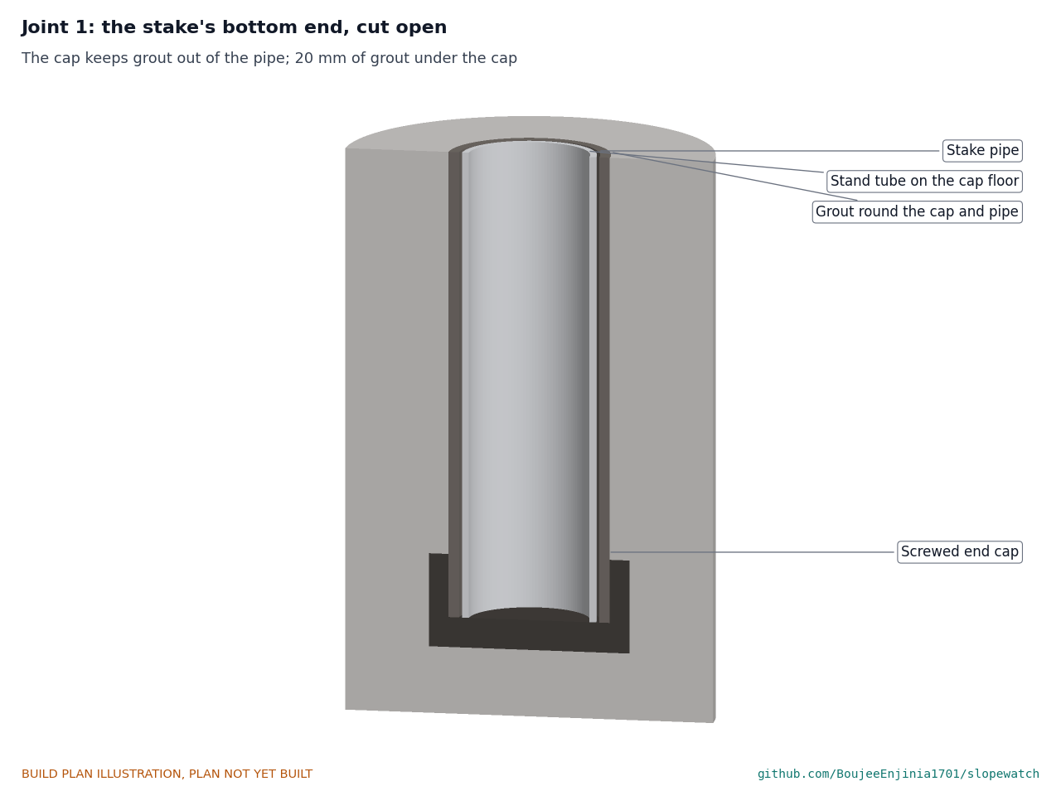
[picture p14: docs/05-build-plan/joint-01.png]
Figure 4. Joint 1: the bottom of the stake, cut open


*Figure 4. The end cap keeps grout and water out; 20 mm of grout runs under it, and the stand tube stands on the cap's floor inside.*

The pipe stands in a 110 mm hole augered 829 mm deep. Grout fills the hole from the bottom to 450 mm above the pipe's bottom end, round the cap and the pipe, and tamped soil fills the hole above the grout.

**Check before moving on.** Blow down the pipe with the cap on: no air comes out at the cap.

### 3.2 Stand tube (make 3)

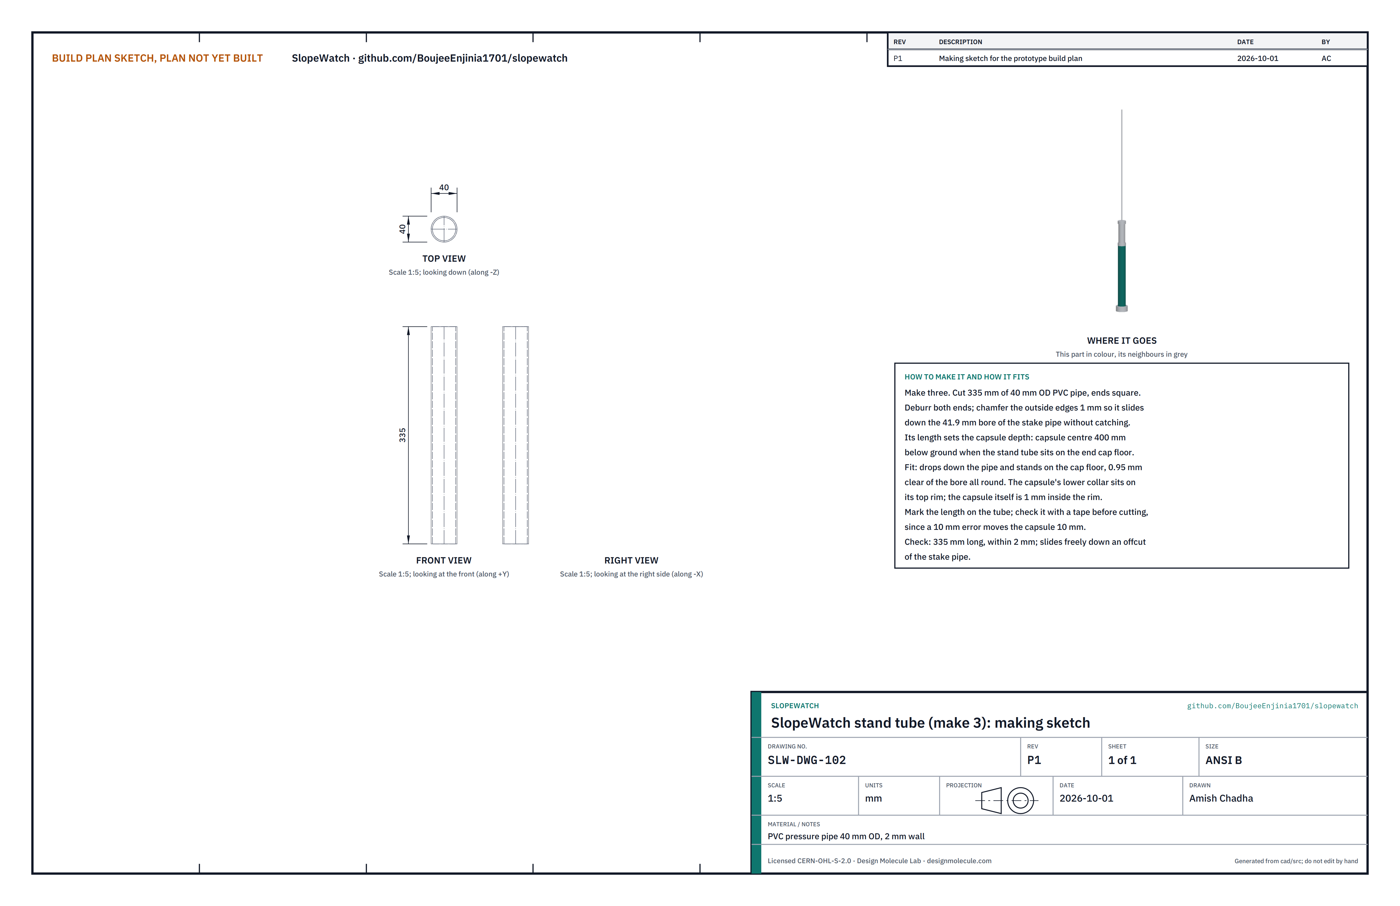
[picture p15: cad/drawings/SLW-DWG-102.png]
Figure 5. Making sketch of the stand tube


*Figure 5. Stand tube making sketch (SLW-DWG-102).*

**What it is and what it is made from.** A plastic tube that stands inside the stake pipe and sets the depth of the capsule. PVC pressure pipe 40 mm outside, 2 mm wall, 335 mm long.

**How to make it.**

1. Measure and mark 335 mm; check the mark with a tape, since a 10 mm error moves the capsule 10 mm.
2. Cut square and deburr both ends.
3. Chamfer the outside edges by 1 mm so the tube slides down the pipe without catching.

**How it fits the parts next to it.** It drops down the pipe and stands on the end cap's floor, 1 mm clear of the bore all round. The capsule's lower collar sits on its top rim (Figure 8).

**Check before moving on.** 335 mm long, within 2 mm, and it slides freely down an offcut of the stake pipe.

### 3.3 Centring collars (make 6)

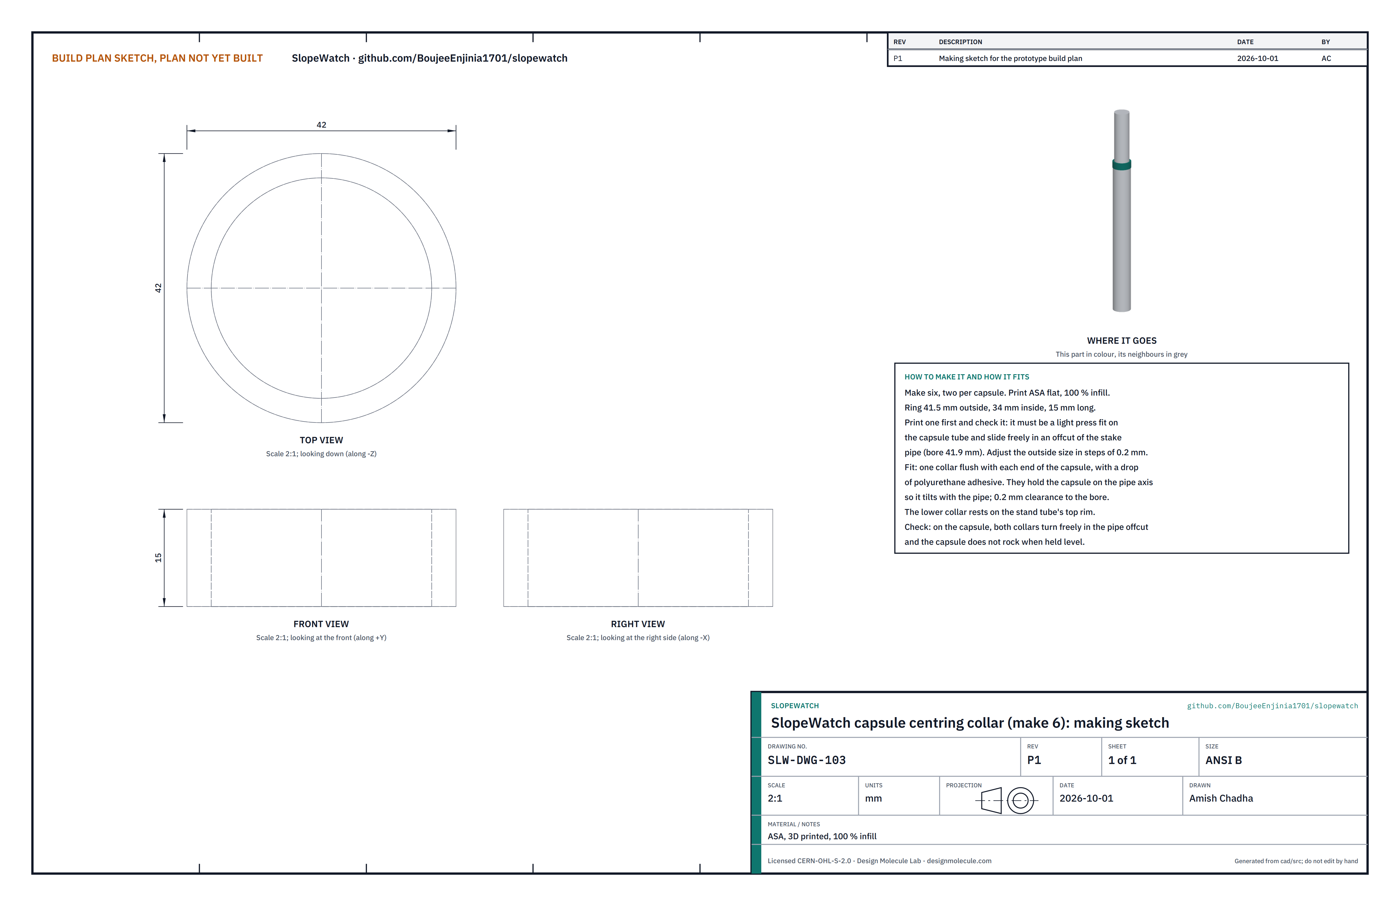
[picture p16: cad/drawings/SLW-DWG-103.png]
Figure 6. Making sketch of the centring collar


*Figure 6. Centring collar making sketch (SLW-DWG-103).*

**What it is and what it is made from.** A ring on each end of the capsule that holds it on the axis of the pipe, so the capsule tilts exactly as the pipe tilts. ASA plastic, 3D printed at 100 % infill, 41.5 mm outside, 34 mm inside and 15 mm long. Two per capsule.

**How to make it.**

1. Print one collar flat in ASA in an enclosed printer.
2. Try it: it must be a light press fit on the capsule tube and slide freely in an offcut of the stake pipe. If not, change the outside size in steps of 0.2 mm and print again.
3. Print the other five.

**How it fits the parts next to it.** One collar is glued flush with each end of the capsule with a drop of polyurethane adhesive. In the pipe there is 0.2 mm between the collar and the bore.

**Check before moving on.** On a capsule, both collars turn freely in the pipe offcut, and the capsule does not rock in it.

### 3.4 Sensor capsule (make 3)

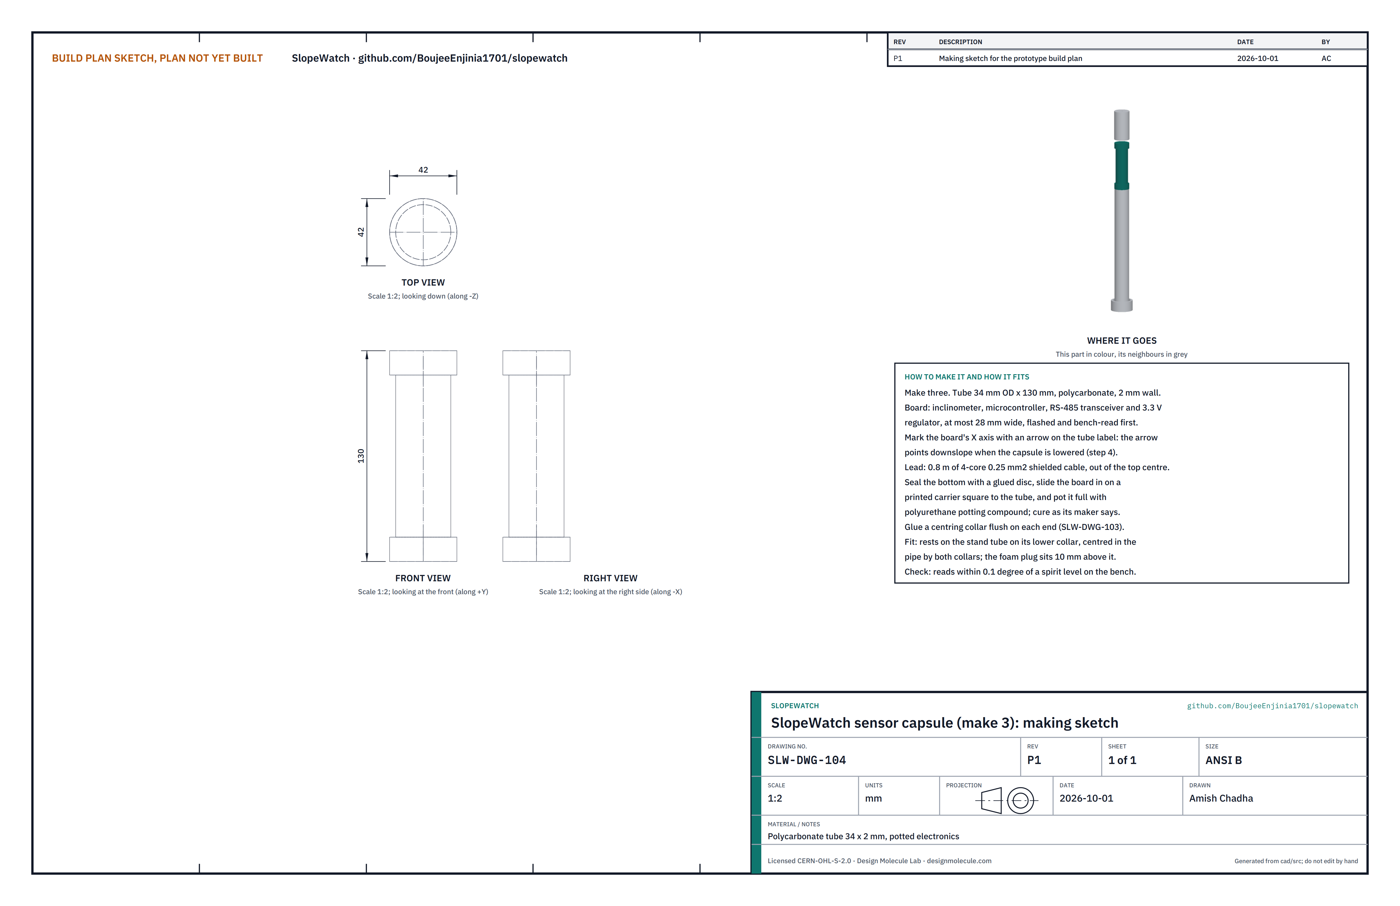
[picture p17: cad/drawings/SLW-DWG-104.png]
Figure 7. Making sketch of the sensor capsule


*Figure 7. Sensor capsule making sketch (SLW-DWG-104).*

**What it is and what it is made from.** The sealed tilt sensor. A board carrying the inclinometer, a small microcontroller, an RS-485 transceiver and a 3.3 V regulator, potted in a polycarbonate tube 34 mm outside, 2 mm wall and 130 mm long, with a 0.8 m lead of four-core 0.25 mm² shielded cable out of the top centre.

**How to make it.**

1. Flash the board and read its tilt on the bench before potting it.
2. Mark the board's X axis with an arrow on a label on the tube. The arrow points downslope when the capsule is installed.
3. Glue a disc into the bottom of the tube.
4. Slide the board in on a printed carrier that holds it square to the tube, lead out of the top.
5. Fill the tube with polyurethane potting compound and cure it as its maker says.
6. Glue a centring collar flush on each end (section 3.3).

**How it fits the parts next to it.**

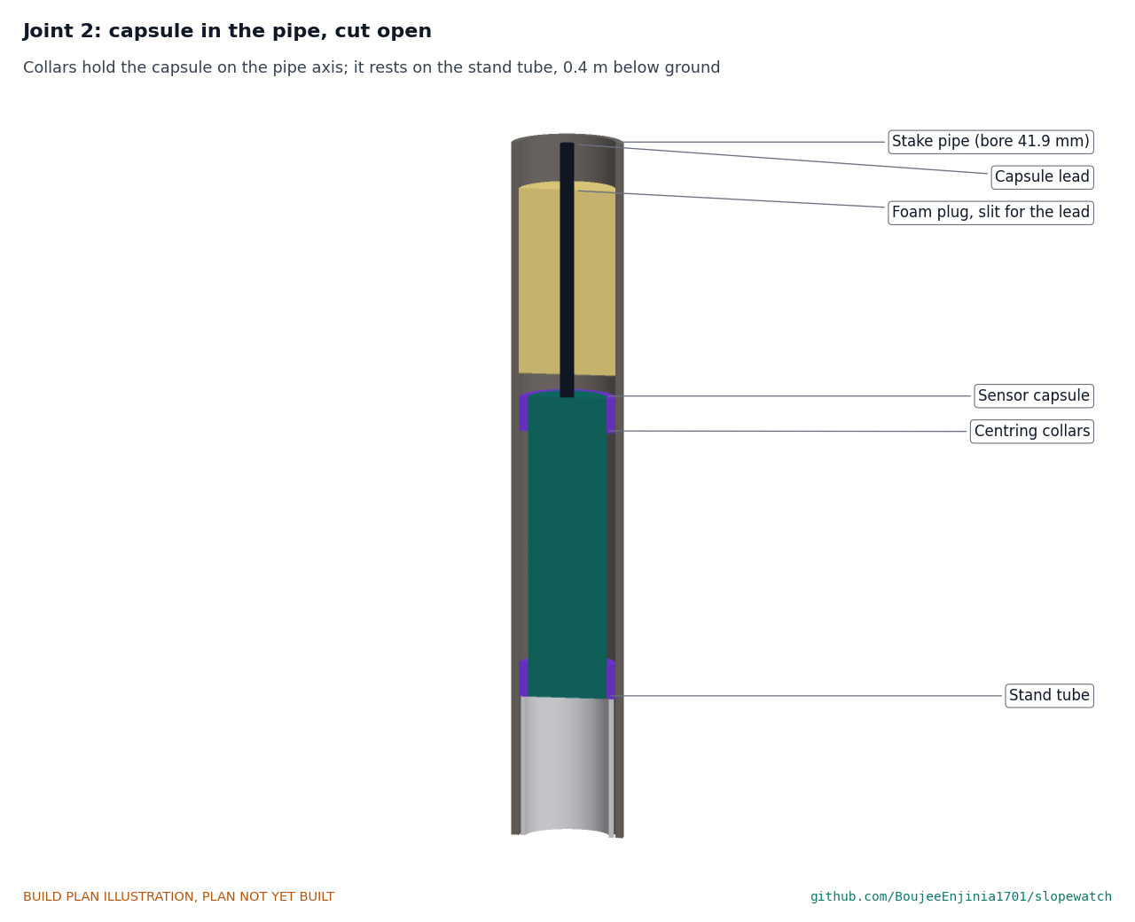
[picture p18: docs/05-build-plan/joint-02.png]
Figure 8. Joint 2: the capsule in the pipe, cut open


*Figure 8. The collars hold the capsule on the pipe axis; the lower collar rests on the stand tube; the foam plug sits 10 mm above the capsule with the lead through its slit.*

The capsule hangs on its lead as it goes down the pipe and comes to rest on the stand tube's rim, its centre 400 mm below ground. An 80 mm foam plug, slit for the lead, is pushed down to 10 mm above it.

**Check before moving on.** Laid on a level bench, the capsule reads within 0.1 degree of a spirit level in both directions.

### 3.5 Stake head (make 3)

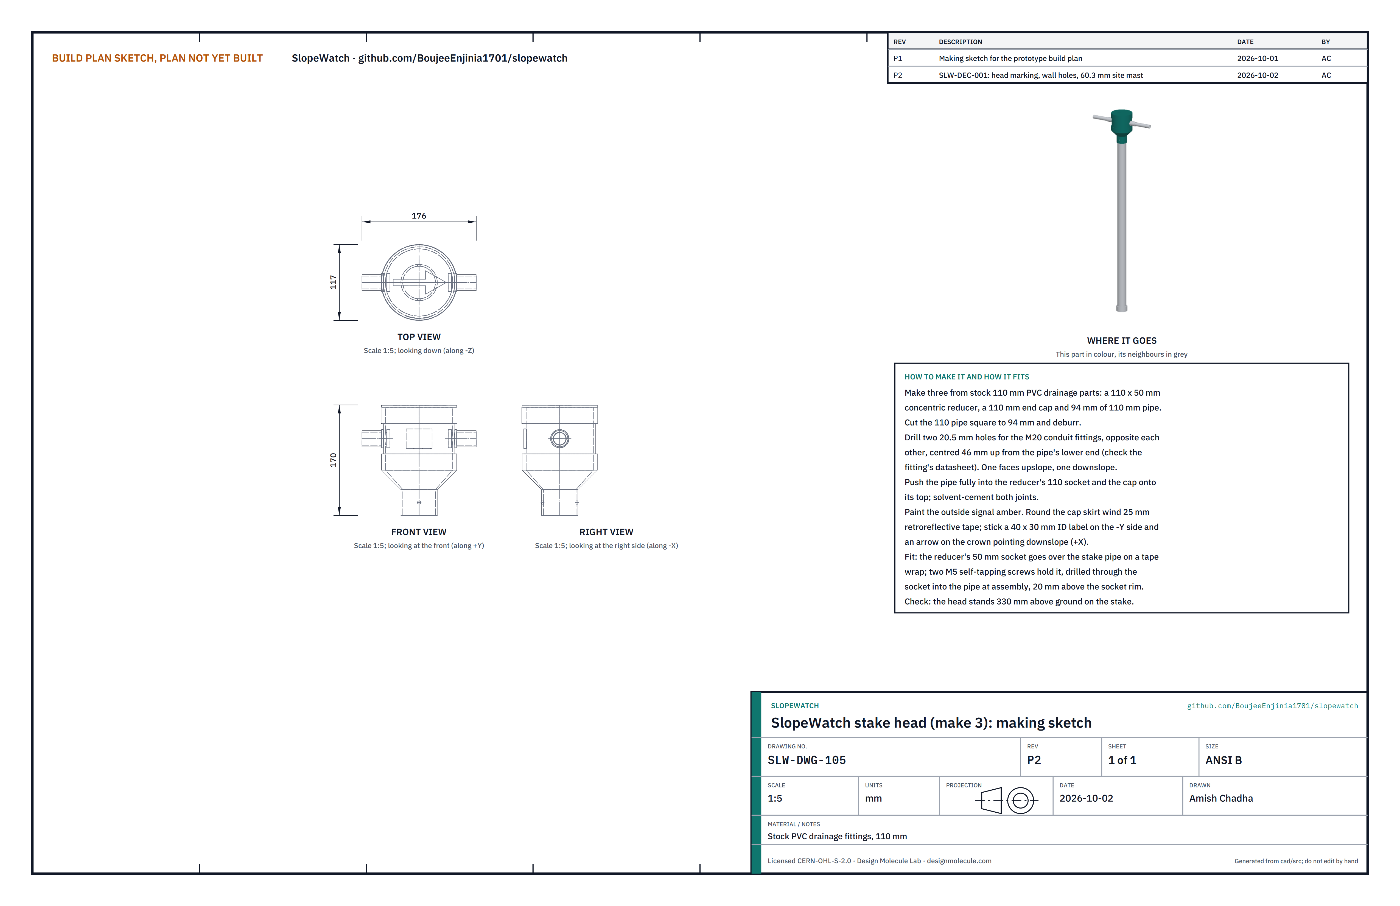
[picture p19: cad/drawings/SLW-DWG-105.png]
Figure 9. Making sketch of the stake head


*Figure 9. Stake head making sketch (SLW-DWG-105).*

**What it is and what it is made from.** A rain-proof head on top of the stake, where the capsule's lead joins the bus. Stock 110 mm PVC drainage fittings: a 110 x 50 mm concentric reducer, 94 mm of 110 mm pipe and a 110 mm end cap, with two M20 conduit fittings for 20 mm corrugated conduit.

**How to make it.**

1. Cut the 110 mm pipe square to 94 mm and deburr it.
2. Drill two 20.5 mm holes opposite each other, centred 46 mm up from the pipe's lower end; check the hole size on the conduit fitting's datasheet first.
3. Push the pipe fully into the reducer's 110 mm socket and solvent-cement it.
4. Dry-fit the end cap; it is cemented after the bus is joined (step 7).
5. Paint the head signal amber with a retroreflective band, and fix a stake ID label and a downslope arrow on the crown, so the stake is seen and can be reported on.

**How it fits the parts next to it.**

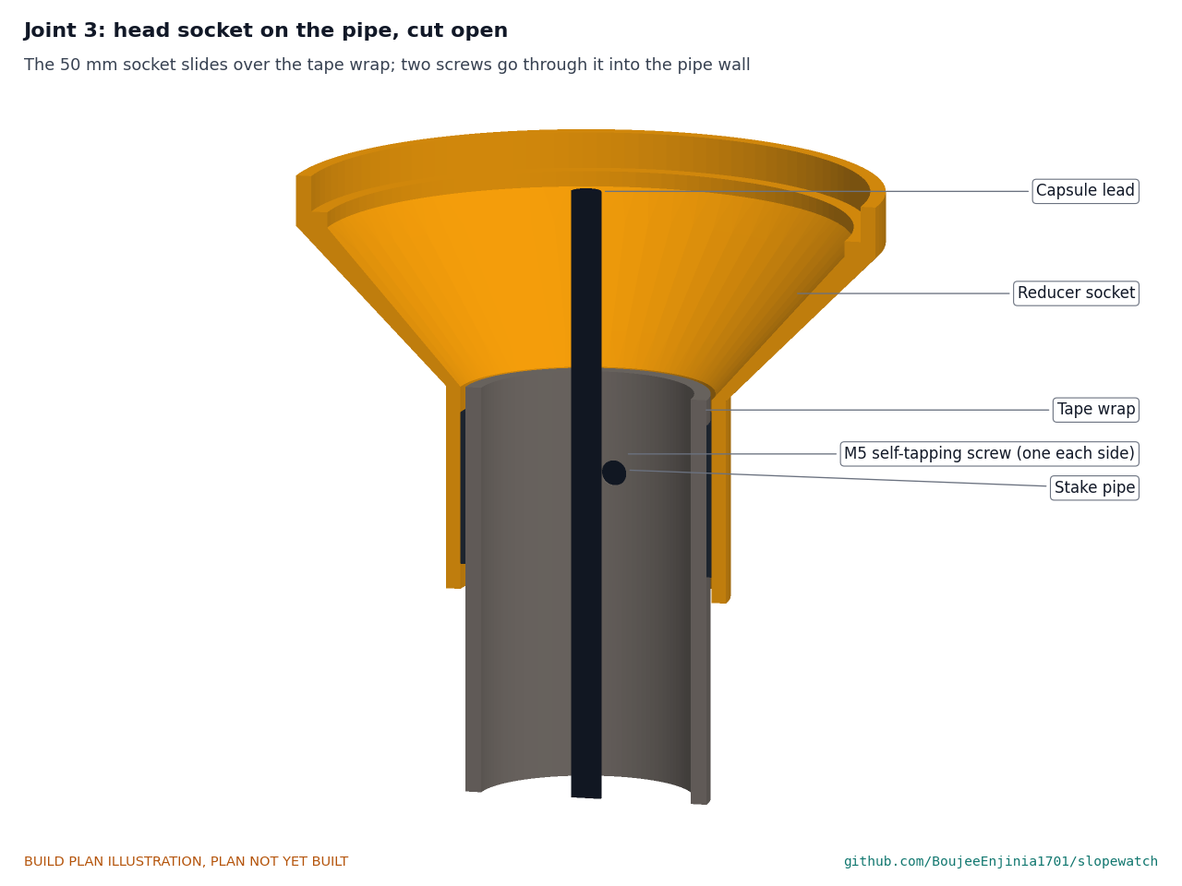
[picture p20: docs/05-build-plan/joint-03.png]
Figure 10. Joint 3: the head socket on the pipe, cut open


*Figure 10. The 50 mm socket slides over a tape wrap on the top of the pipe; two screws go through the socket into the pipe wall.*

The reducer's 50 mm socket goes 40 mm over the top of the stake pipe. Three turns of self-amalgamating tape round the pipe take up the gap and seal it. Two M5 stainless self-tapping screws, one each side, go through the socket into 4.2 mm holes in the pipe wall, 20 mm above the socket's rim.

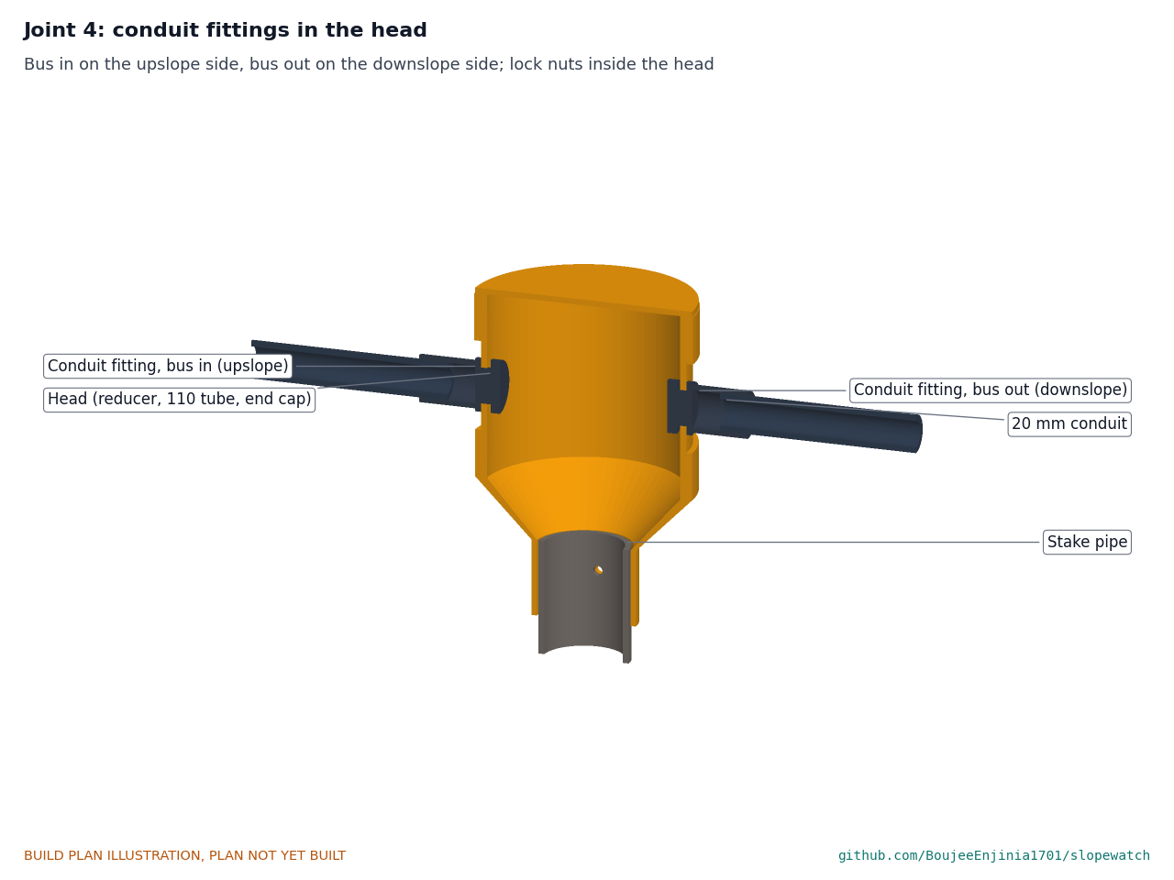
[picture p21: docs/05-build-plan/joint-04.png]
Figure 11. Joint 4: the conduit fittings in the head


*Figure 11. The bus comes in on the upslope side and goes out on the downslope side; each fitting's lock nut is inside the head.*

**Check before moving on.** The head stands 330 mm above the ground mark on a pipe offcut, and both fittings point along the same line.

### 3.6 Anchor pins (make 2)

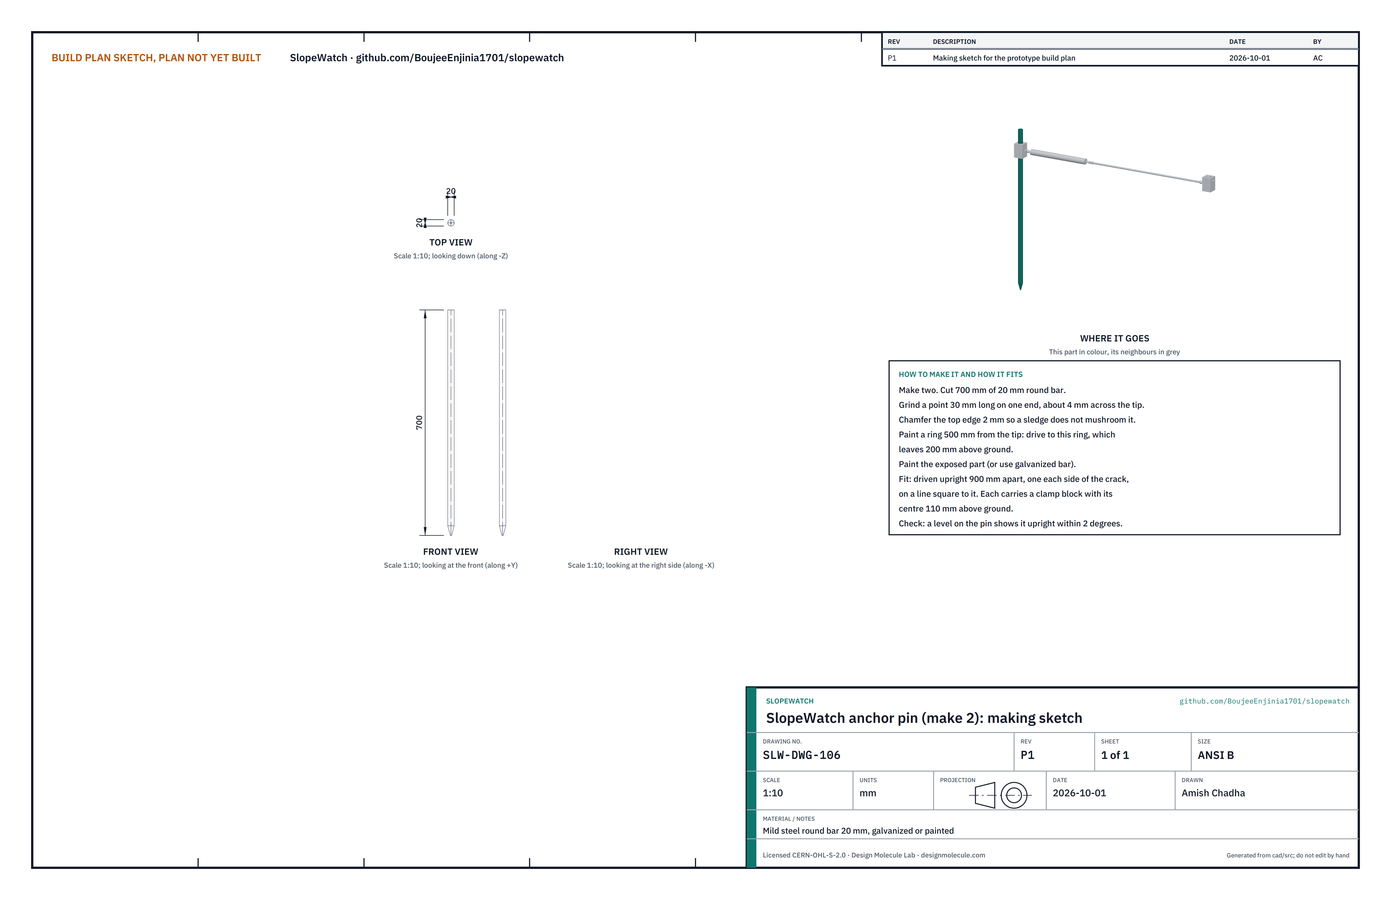
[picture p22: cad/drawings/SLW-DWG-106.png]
Figure 12. Making sketch of the anchor pin


*Figure 12. Anchor pin making sketch (SLW-DWG-106).*

**What it is and what it is made from.** The two steel pins driven into the ground either side of the crack; each carries one end of the crack gauge. Mild steel round bar 20 mm, 700 mm long, galvanized or painted.

**How to make it.**

1. Cut 700 mm of bar.
2. Grind a point 30 mm long on one end, about 4 mm across the tip.
3. Chamfer the top edge by 2 mm so a sledge does not spread it.
4. Paint a ring 500 mm from the tip; the pin is driven to this ring, leaving 200 mm above ground.

**How it fits the parts next to it.** Driven upright 900 mm apart, one each side of the crack, on a line square to it. Each carries a clamp block (Figure 14).

**Check before moving on.** A level on the pin shows it upright within 2 degrees.

### 3.7 Clamp blocks (make 2)

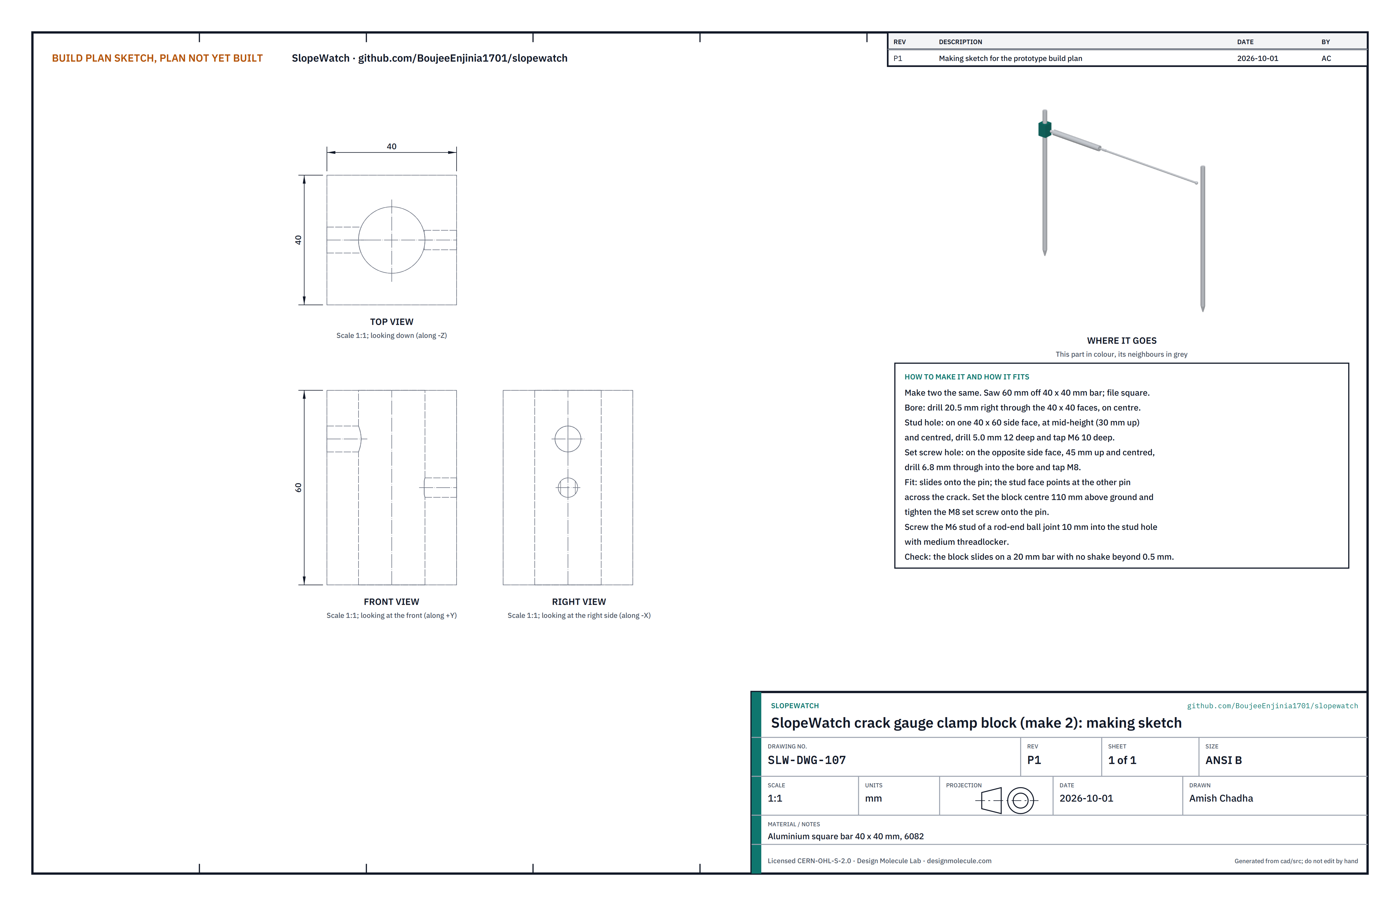
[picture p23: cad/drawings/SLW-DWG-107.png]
Figure 13. Making sketch of the clamp block


*Figure 13. Clamp block making sketch (SLW-DWG-107).*

**What it is and what it is made from.** A block that slides onto an anchor pin and carries a ball joint for the gauge. Aluminium square bar 40 x 40 mm, 6082 class, 60 mm long. Both blocks are the same.

**How to make it.**

1. Saw 60 mm off the bar and file it square.
2. Drill a 20.5 mm hole right through the middle of the two 40 x 40 mm faces.
3. On one 40 x 60 mm side face, at mid-height and centred, drill 5.0 mm 12 deep and tap M6 10 deep for the ball-joint stud.
4. On the opposite side face, 45 mm up and centred, drill 6.8 mm through into the bore and tap M8 for the set screw.
5. Deburr all edges and the bore.

**How it fits the parts next to it.**

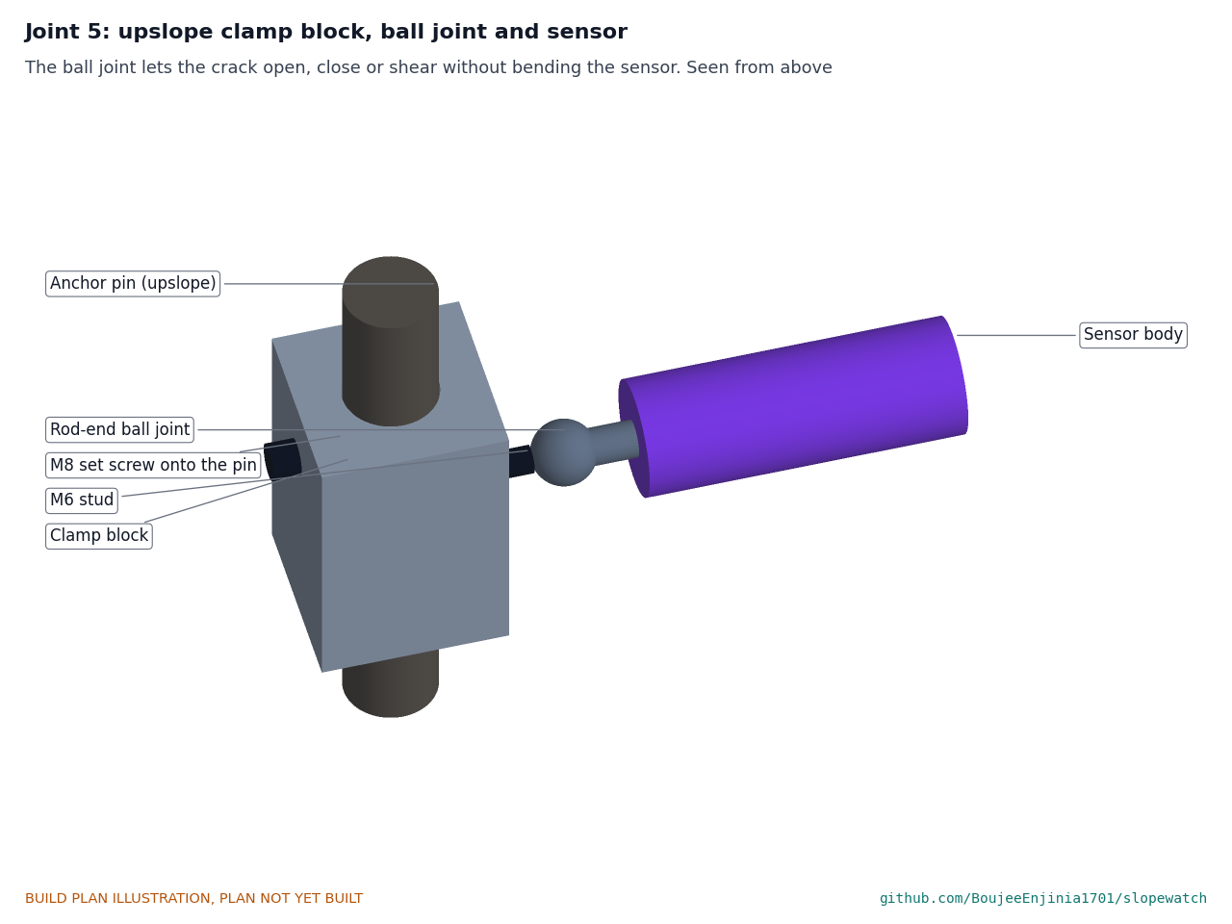
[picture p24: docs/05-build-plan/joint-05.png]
Figure 14. Joint 5: the upslope clamp block, ball joint and sensor


*Figure 14. The block slides onto the pin, the set screw bears on the pin, and the sensor hangs on the ball joint.*

Each block slides onto its pin with its stud face pointing at the other pin, and is set with its centre 110 mm above the ground. The M8 set screw on the outer face clamps it to the pin. The M6 stud of a rod-end ball joint screws 10 mm into the stud hole with medium threadlocker.

**Check before moving on.** The block slides on a 20 mm bar with no more than 0.5 mm of shake.

### 3.8 Extension rod

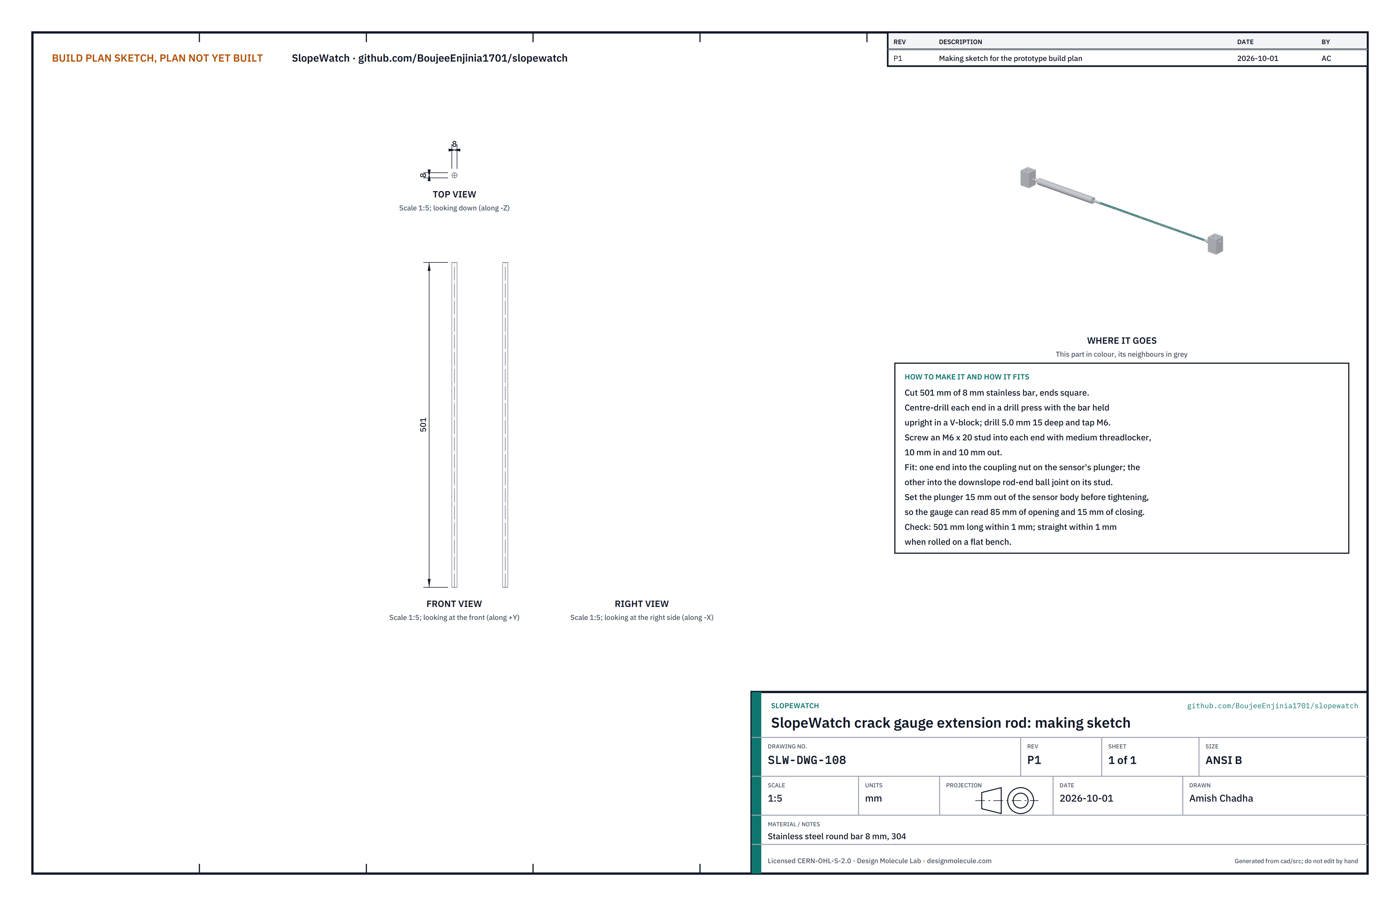
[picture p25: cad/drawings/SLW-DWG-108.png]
Figure 15. Making sketch of the extension rod


*Figure 15. Extension rod making sketch (SLW-DWG-108).*

**What it is and what it is made from.** The rod that carries the sensor's movement across the crack to the downslope pin. Stainless steel round bar 8 mm, 501 mm long, with an M6 stud in each end.

**How to make it.**

1. Cut 501 mm of bar, ends square.
2. Hold the bar upright in a V-block in a drill press, centre-drill each end, drill 5.0 mm 15 deep and tap M6.
3. Screw an M6 x 20 stud into each end with medium threadlocker, 10 mm in and 10 mm out.

**How it fits the parts next to it.**

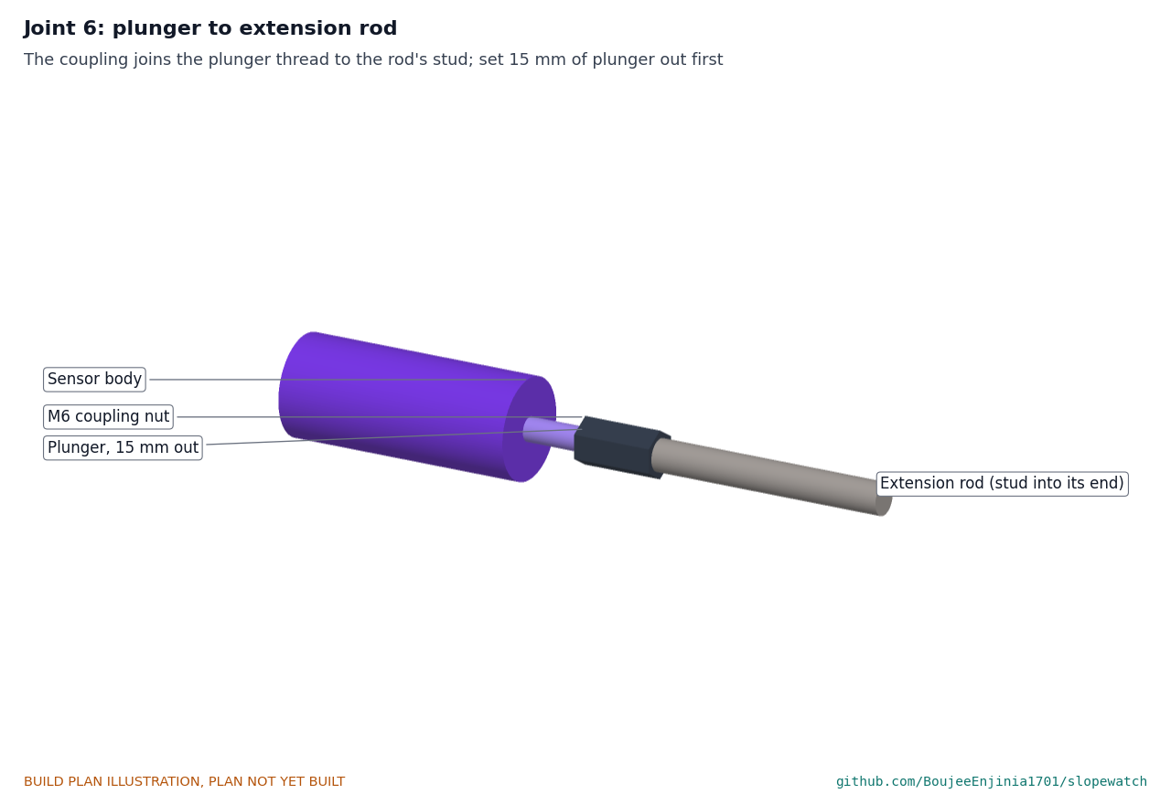
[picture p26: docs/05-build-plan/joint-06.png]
Figure 16. Joint 6: plunger to extension rod


*Figure 16. A coupling nut joins the sensor's plunger to the rod.*

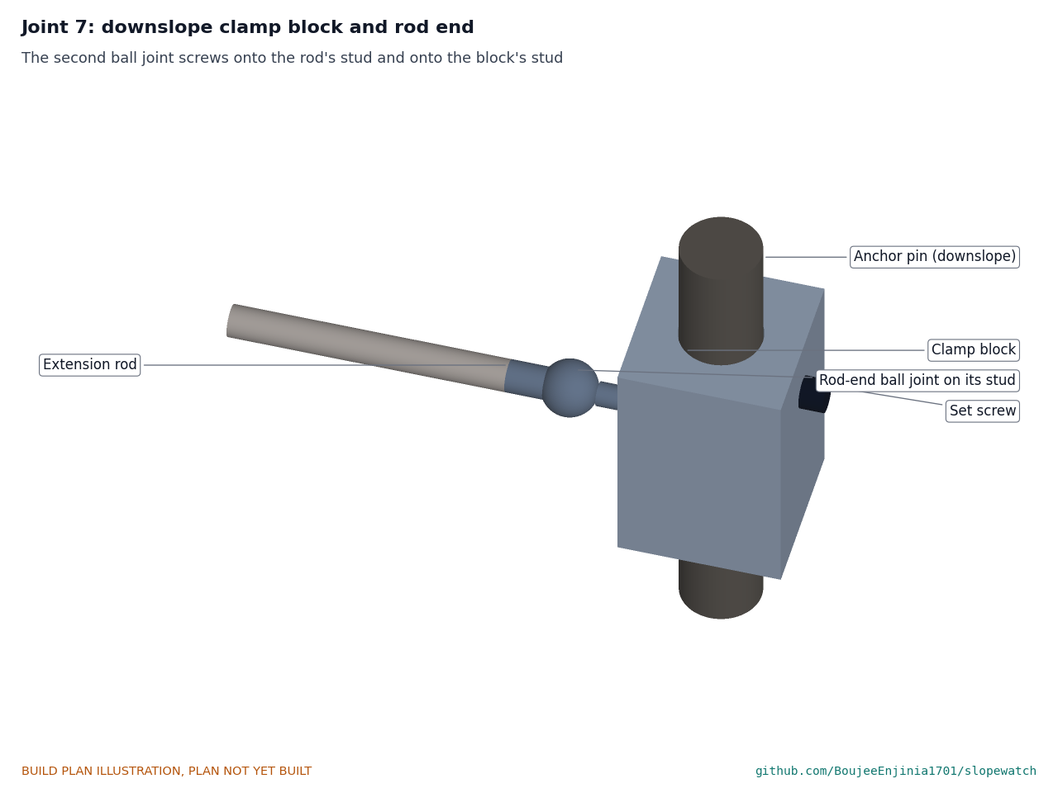
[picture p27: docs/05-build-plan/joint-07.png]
Figure 17. Joint 7: the downslope clamp block and rod end


*Figure 17. The rod's other end screws into the second ball joint, which sits on the downslope block's stud.*

Set the plunger 15 mm out of the sensor body before tightening the coupling, so the gauge can read 85 mm of opening and 15 mm of closing.

**Check before moving on.** 501 mm long within 1 mm, and straight within 1 mm when rolled on a flat bench.

### 3.9 Guard

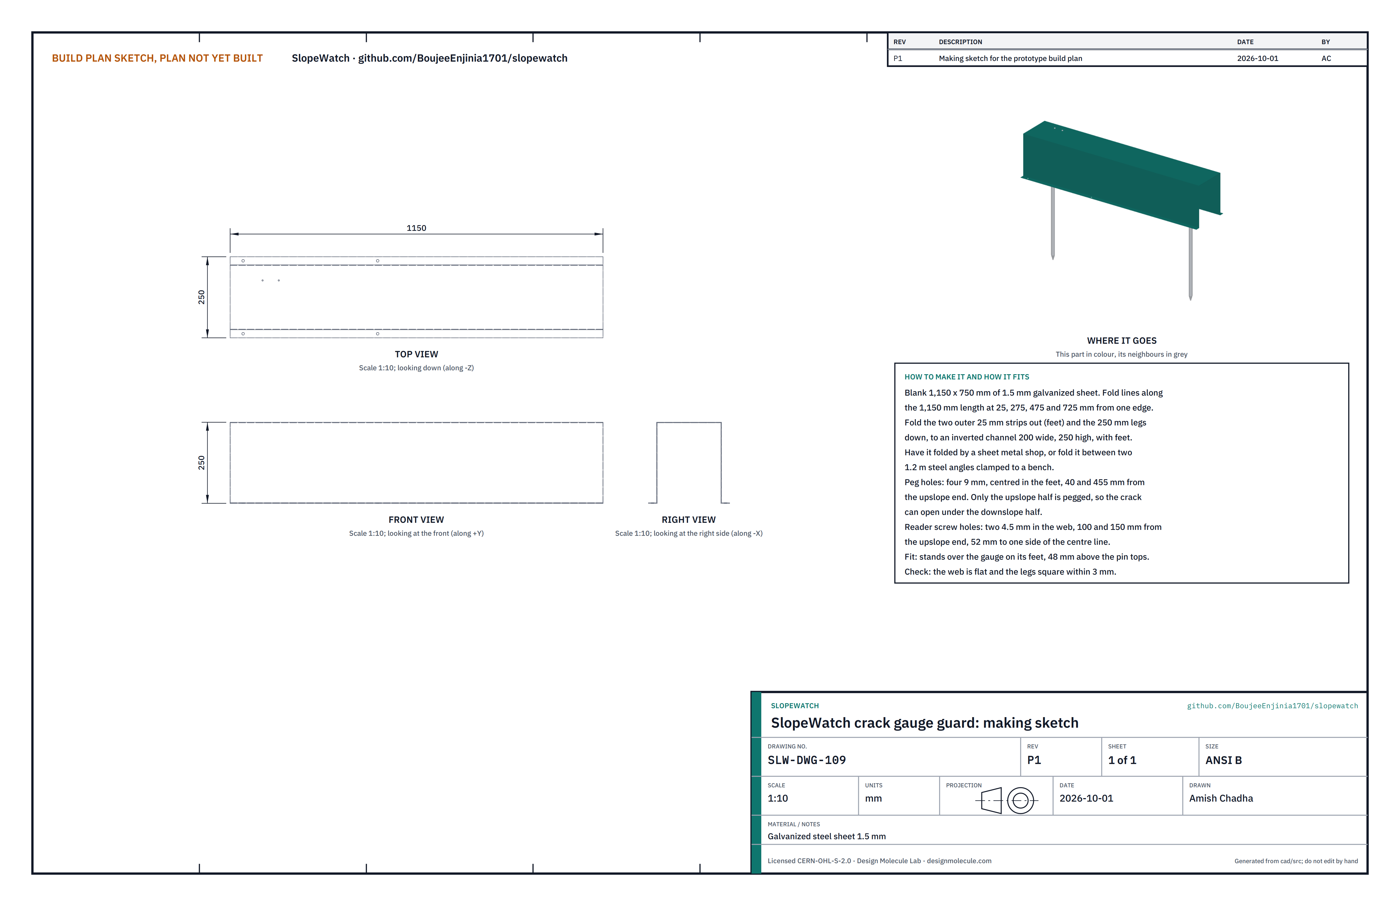
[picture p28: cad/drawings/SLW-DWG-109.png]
Figure 18. Making sketch of the guard


*Figure 18. Guard making sketch (SLW-DWG-109).*

**What it is and what it is made from.** A cover over the crack gauge that keeps off sun, rain, animals and boots. Galvanized steel sheet 1.5 mm, folded to a channel 1,150 long, 200 wide and 250 high, with 25 mm feet.

**How to make it.**

1. Cut a blank 1,150 x 750 mm.
2. Mark fold lines along the 1,150 mm length at 25, 275, 475 and 725 mm from one edge.
3. Fold the two outer 25 mm strips outward (the feet) and the two 250 mm legs down. Have a sheet metal shop fold it, or fold it between two 1.2 m steel angles clamped to a bench.
4. Drill four 9 mm peg holes centred in the feet, 40 and 455 mm from the upslope end.
5. Drill two 4.5 mm holes in the web for the reader box, 100 and 150 mm from the upslope end and 52 mm to one side of the centre line.

**How it fits the parts next to it.**

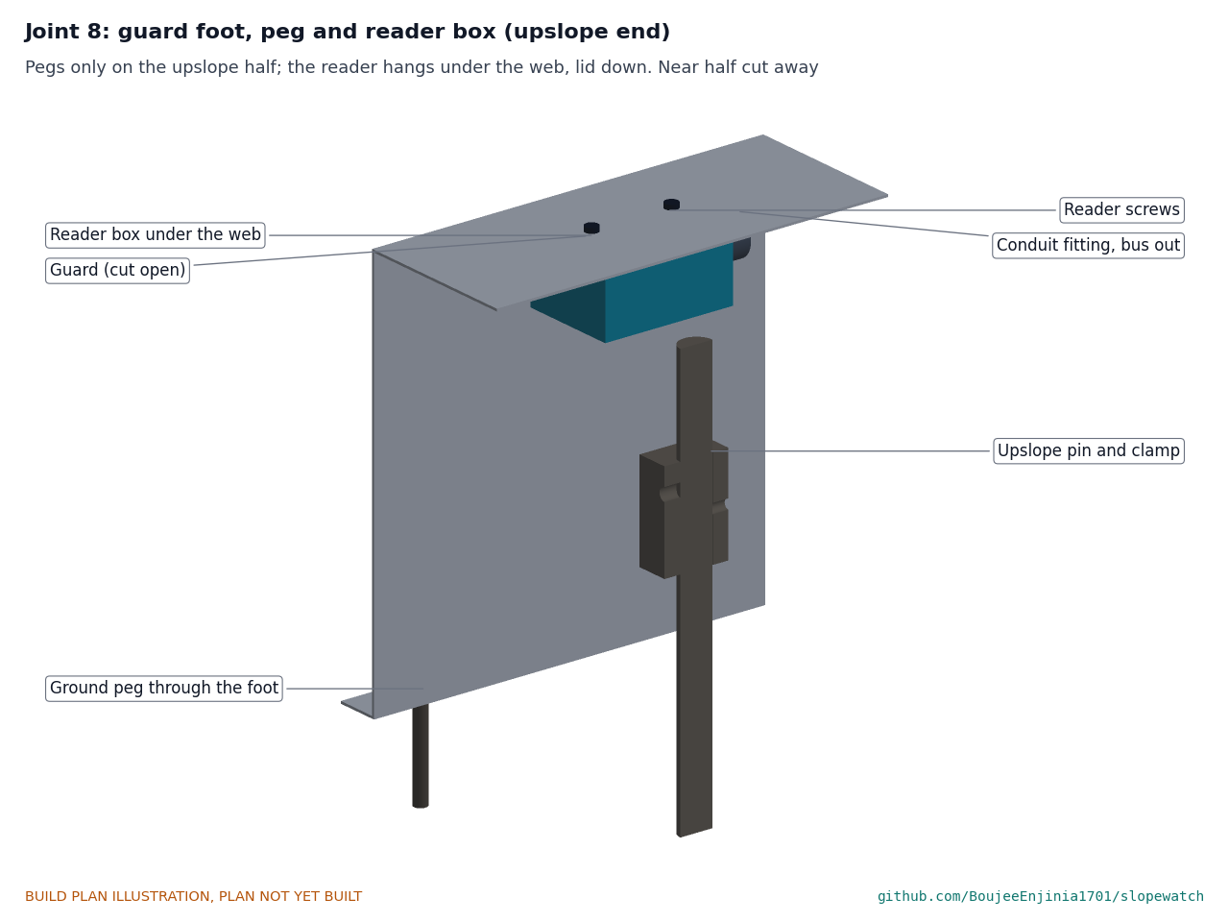
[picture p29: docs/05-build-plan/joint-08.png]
Figure 19. Joint 8: guard foot, peg and reader box at the upslope end


*Figure 19. The guard stands on its feet 48 mm above the pin tops; pegs hold its upslope half; the reader box hangs under the web.*

Four 8 mm x 300 mm ground pegs go through the feet on the upslope half only, so the ground can open under the downslope half without the guard holding the crack together.

**Check before moving on.** The web is flat and the legs square to it within 3 mm.

### 3.10 Reader box

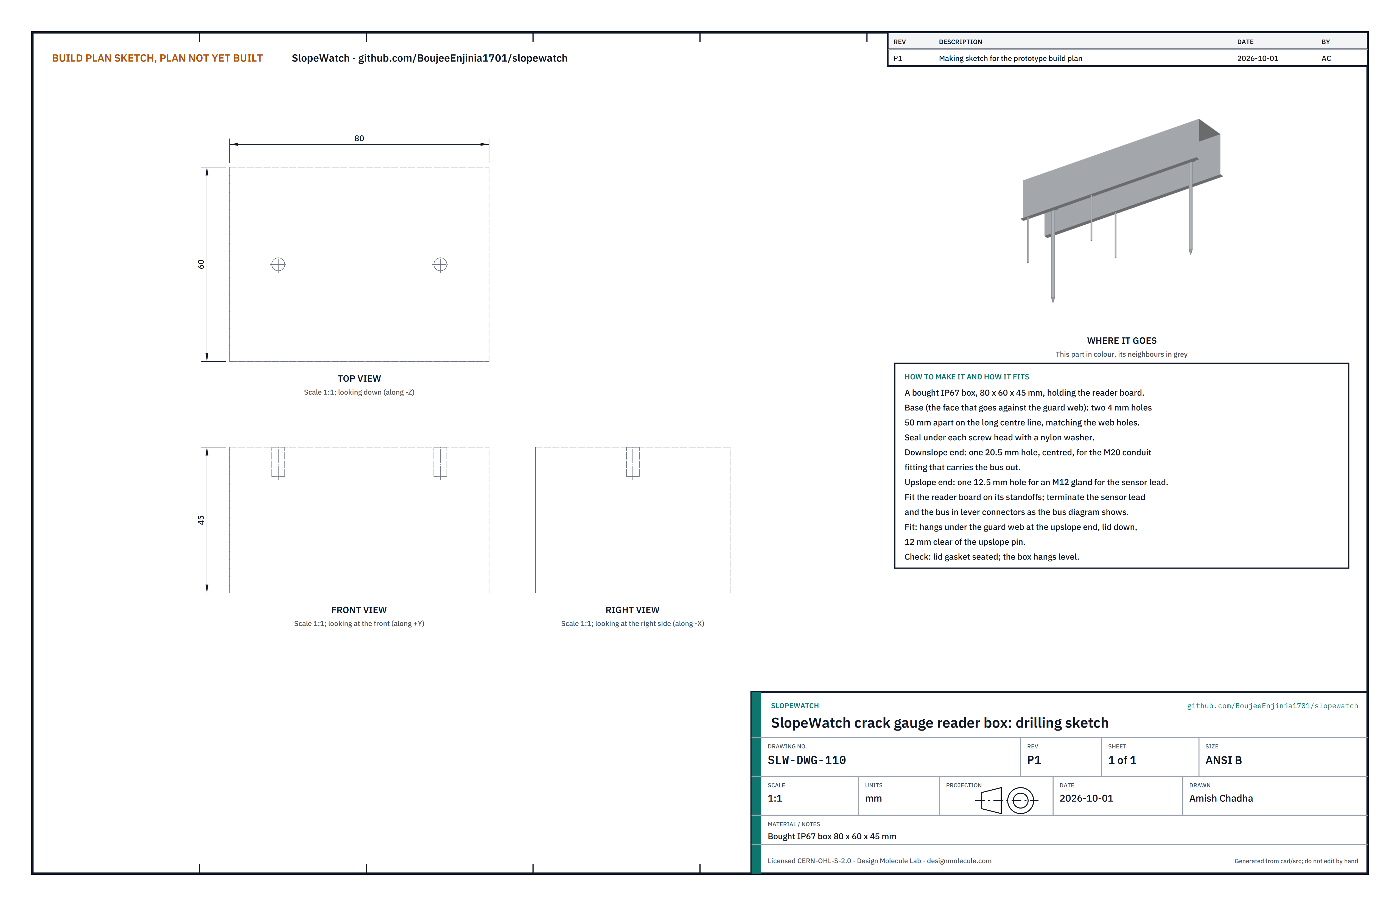
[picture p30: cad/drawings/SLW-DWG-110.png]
Figure 20. Drilling sketch of the reader box


*Figure 20. Reader box drilling sketch (SLW-DWG-110).*

**What it is and what it is made from.** A bought IP67 box, 80 x 60 x 45 mm, holding the reader board that turns the crack gauge's signal into a bus reading. The board is the capsule's board without the inclinometer.

**How to make it.**

1. In the base, drill two 4 mm holes 50 mm apart on the long centre line, to match the guard's web holes.
2. In the downslope end, drill one 20.5 mm hole, centred, for an M20 conduit fitting.
3. In the upslope end, drill one 12.5 mm hole for an M12 gland for the sensor lead.
4. Fit the reader board on its standoffs, and wire the sensor lead and the bus to it as Figure 31 shows.

**How it fits the parts next to it.** It hangs under the guard web at the upslope end, lid down, on two M4 screws with nylon sealing washers, 12 mm clear of the upslope pin (Figure 19). The bus conduit runs from its fitting along the ground inside the guard and out of the guard's open downslope end, with a 0.5 m slack loop.

**Check before moving on.** The lid gasket is seated and the box hangs level.

### 3.11 Alert unit back plate

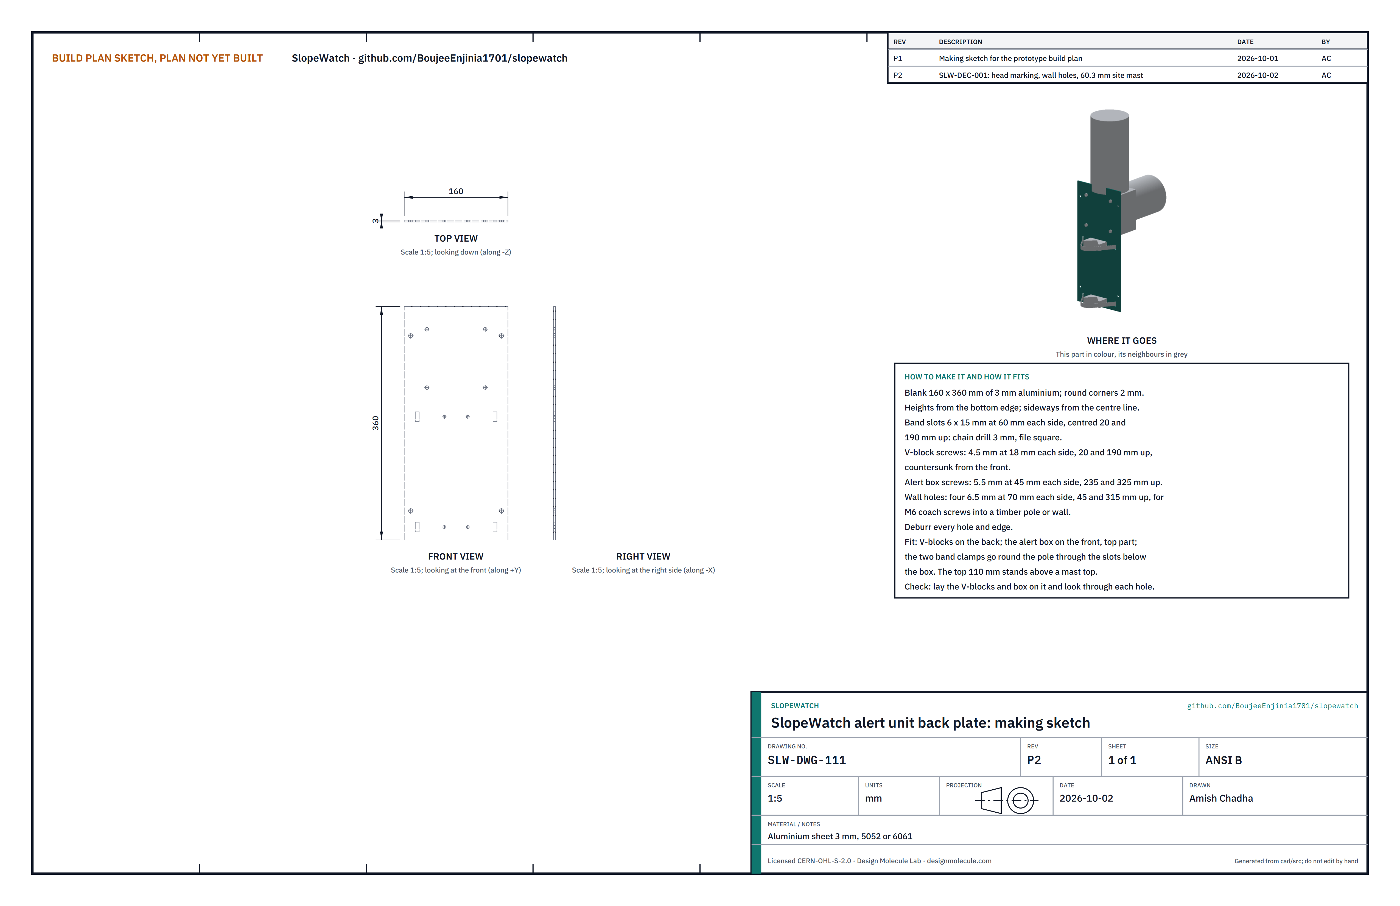
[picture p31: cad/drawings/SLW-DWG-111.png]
Figure 21. Making sketch of the alert unit back plate


*Figure 21. Alert unit back plate making sketch (SLW-DWG-111).*

**What it is and what it is made from.** The plate the alert box is screwed to and that clamps to the pole. Aluminium sheet 3 mm, 5052 or 6061 class, 160 x 360 mm.

**How to make it.** Measure heights up from the bottom edge and sideways from the centre line.

1. Cut the blank, square, and round the corners to about 2 mm.
2. Band slots: four slots 6 wide and 15 tall, 60 each side of centre, centred 20 and 190 up. Chain drill with a 3 mm drill and file them square.
3. V-block screw holes: four 4.5 mm holes, 18 each side of centre, 20 and 190 up, countersunk from the front.
4. Alert box screw holes: four 5.5 mm holes, 45 each side of centre, 235 and 325 up.
5. Wall holes: four 6.5 mm holes, 70 each side of centre, 45 and 315 up (45 in from each end), for coach screws when the unit goes on a timber pole or a wall instead of a steel pole.
6. Deburr every hole on both faces.

**How it fits the parts next to it.** The V-blocks sit on its back, the alert box on the top part of its front. The two band clamps go round the pole and through the slots, below the box. On the mast, the top 110 mm of the plate stands above the mast top so the beacon clears it. On a timber pole or wall, leave off the V-blocks and bands and fix the plate with four M6 coach screws through the wall holes; the screw heads clear the alert box by 3 mm.

**Check before moving on.** Lay the V-blocks and the box on it and look through each hole: they line up without forcing a screw.

### 3.12 V-blocks (make 2)

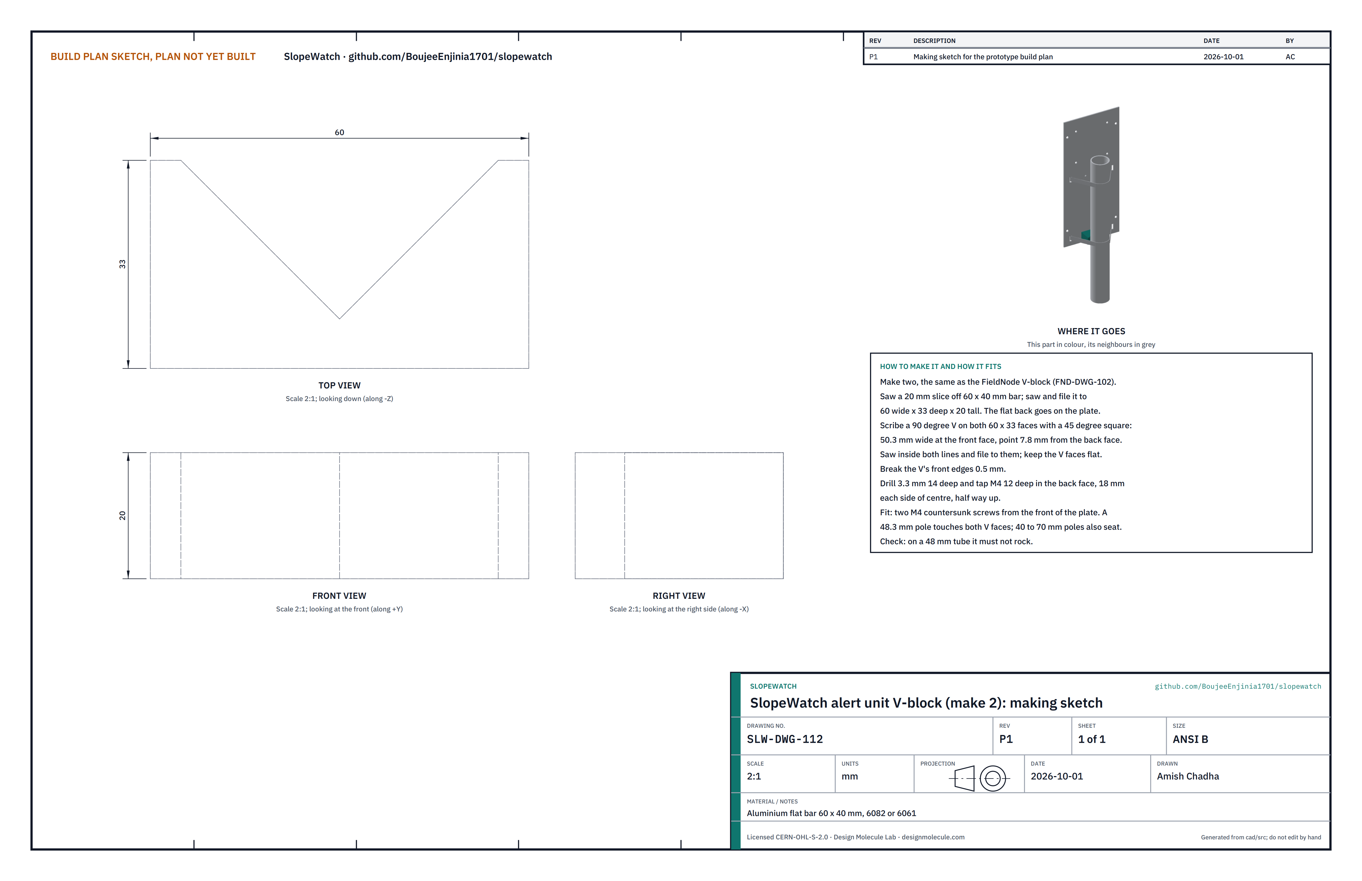
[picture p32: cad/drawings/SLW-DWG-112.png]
Figure 22. Making sketch of the V-block


*Figure 22. V-block making sketch (SLW-DWG-112).*

**What it is and what it is made from.** A block with a V cut in it that the pole sits in, one at each band clamp. Aluminium flat bar 60 x 40 mm, 6082 or 6061 class. It is the same part as the FieldNode V-block.

**How to make it.**

1. Saw two 20 mm slices off the bar; saw and file each to 60 wide, 33 deep and 20 tall. The 60 x 20 mm face is the back face; file it flat.
2. On each 60 x 33 mm face, scribe the V with a 45 degree square: 50.3 mm wide at the front face, its point 7.8 mm from the back face.
3. Saw just inside both lines and file to them, keeping the V faces flat.
4. Break the sharp front edges of the V by 0.5 mm.
5. In the back face, 18 each side of centre and half way up, drill 3.3 mm 14 deep and tap M4 12 deep.

**How it fits the parts next to it.**

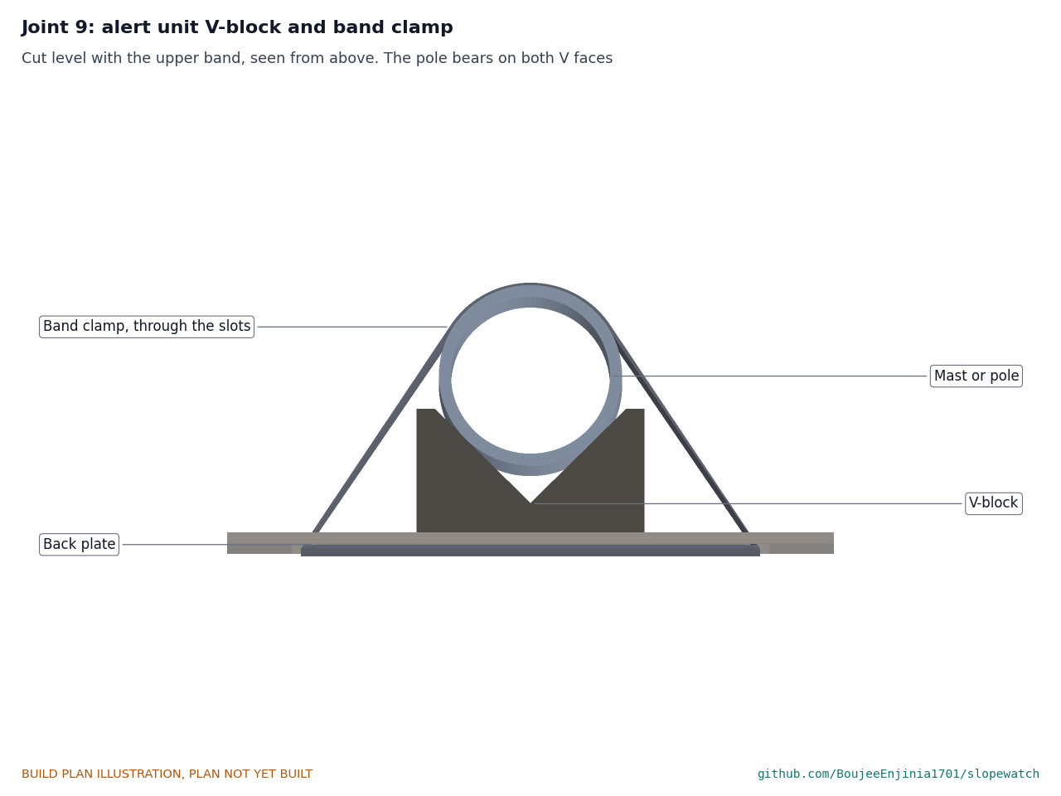
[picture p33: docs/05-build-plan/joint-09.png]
Figure 23. Joint 9: V-block and band clamp, seen from above


*Figure 23. The pole bears on both faces of the V; the band goes round the pole, through the plate's slots and across the plate front.*

Each block is held to the back of the plate by two M4 countersunk screws put in from the front with a drop of medium threadlocker. A 48.3 mm pole touches both faces of the V and never the bottom; poles of 40 to 70 mm also seat on both faces.

**Check before moving on.** Held against a 48 mm tube, the block does not rock.

### 3.13 Alert box

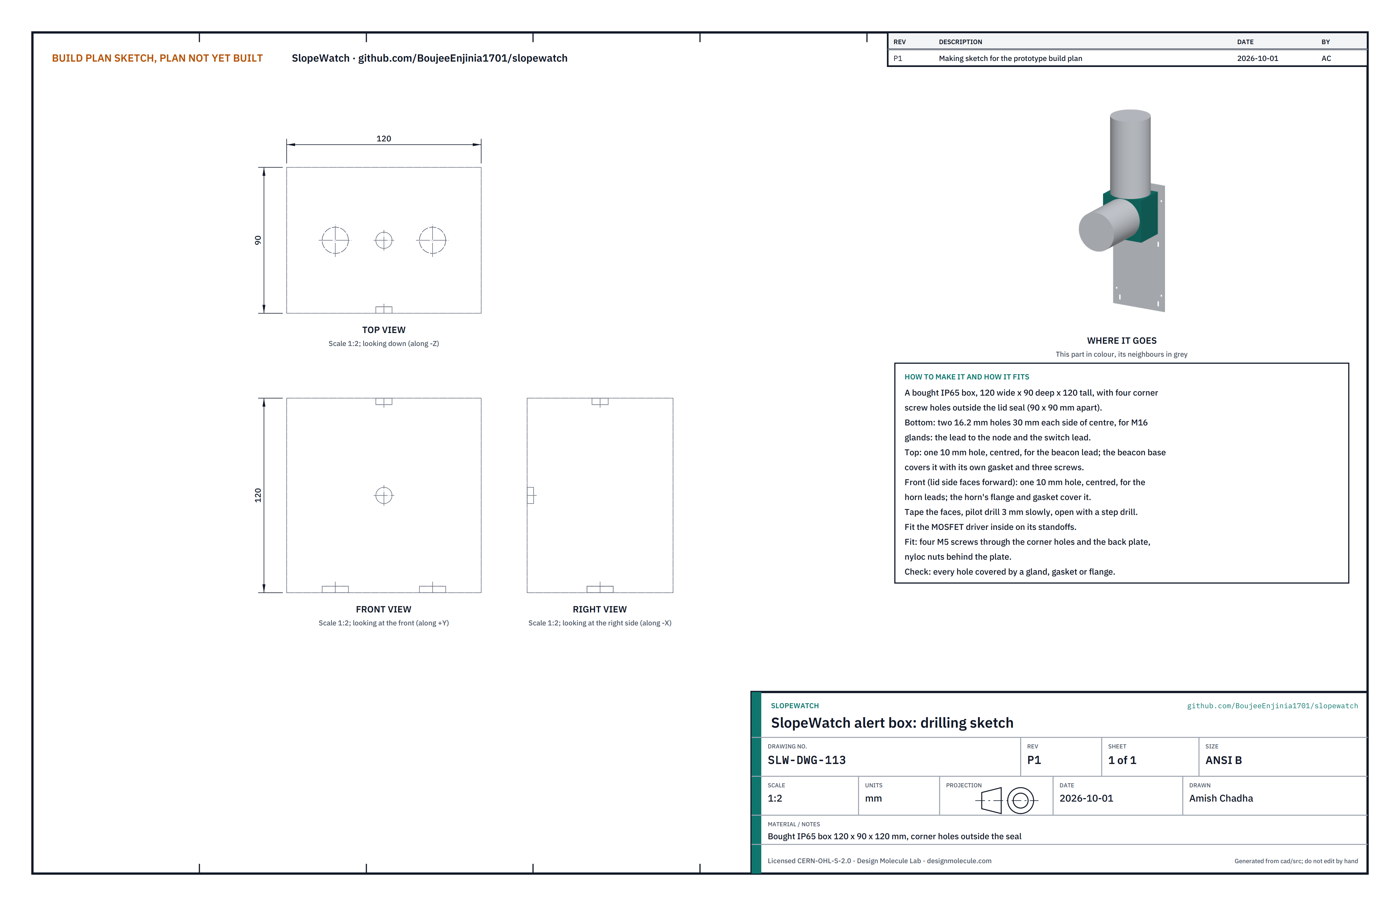
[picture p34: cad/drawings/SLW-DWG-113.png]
Figure 24. Drilling sketch of the alert box


*Figure 24. Alert box drilling sketch (SLW-DWG-113).*

**What it is and what it is made from.** A bought IP65 box, 120 wide, 90 deep and 120 tall, with four corner screw holes outside the lid seal. It holds the siren and beacon driver; the horn mounts on its front and the beacon on its top.

**How to make it.**

1. Tape the faces. Pilot drill every hole 3 mm slowly and open it with a step drill.
2. Bottom: two 16.2 mm holes 30 each side of centre for M16 glands, one for the lead to the node and one for the switch lead.
3. Top: one 10 mm hole, centred, for the beacon lead.
4. Front: one 10 mm hole, centred, for the horn leads.
5. Fit the driver inside on its standoffs. Fit the horn with its flange and gasket over the front hole and the beacon with its base gasket over the top hole, each with the screws its maker supplies.

**How it fits the parts next to it.**

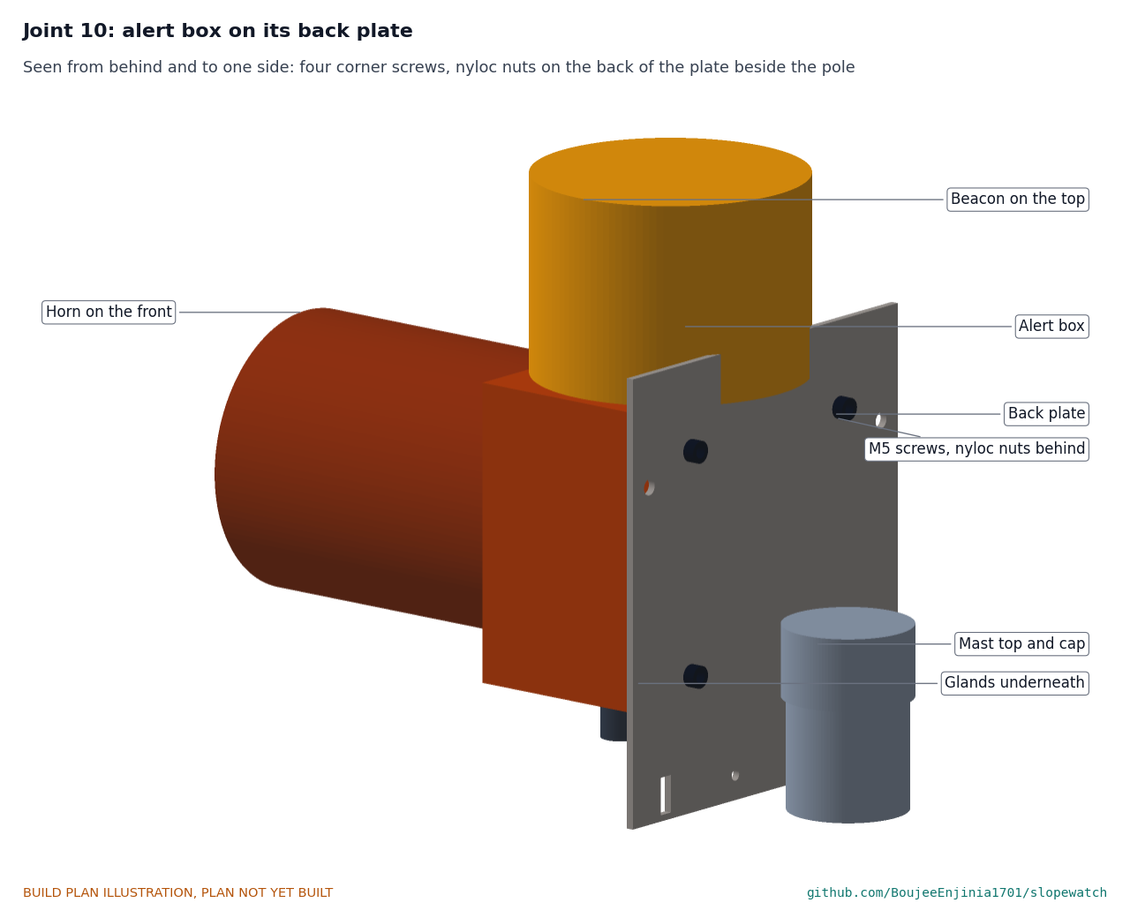
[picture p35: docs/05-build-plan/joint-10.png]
Figure 25. Joint 10: the alert box on its back plate


*Figure 25. Seen from behind: four screws through the box's corner holes and the plate, nyloc nuts on the back of the plate beside the pole.*

**Check before moving on.** Every hole in the box is covered by a gland, a gasket or a flange.

### 3.14 Switch post

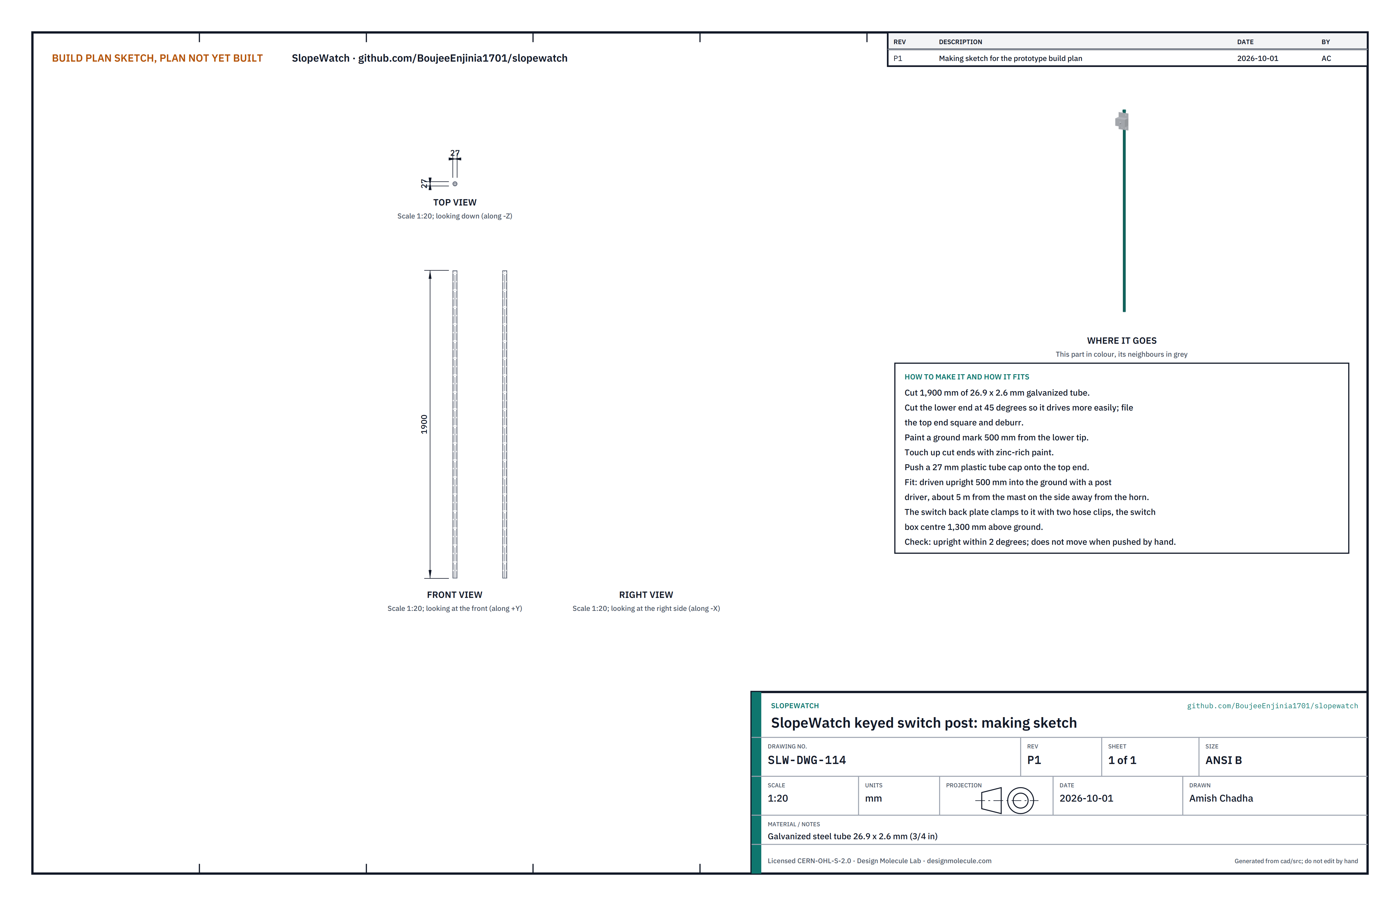
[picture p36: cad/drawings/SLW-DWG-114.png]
Figure 26. Making sketch of the switch post


*Figure 26. Switch post making sketch (SLW-DWG-114).*

**What it is and what it is made from.** The post that carries the keyed silence switch about 5 m from the siren, where the sound is about 95 dB(A) instead of about 106 dB(A) at the pole. Galvanized steel tube 26.9 x 2.6 mm (0.75 in), 1,900 mm long, with a push-on plastic cap.

**How to make it.**

1. Cut 1,900 mm of tube; cut the lower end at 45 degrees so it drives more easily, and file the top end square.
2. Paint a ground mark 500 mm from the lower tip.
3. Touch up the cut ends with zinc-rich paint and push the cap onto the top.

**How it fits the parts next to it.** Driven upright 500 mm into the ground, about 5 m from the pole on the side away from the horn. The switch back plate clamps to it with the box centre 1,300 mm above the ground (Figure 28).

**Check before moving on.** Upright within 2 degrees, and it does not move when pushed by hand.

### 3.15 Switch back plate

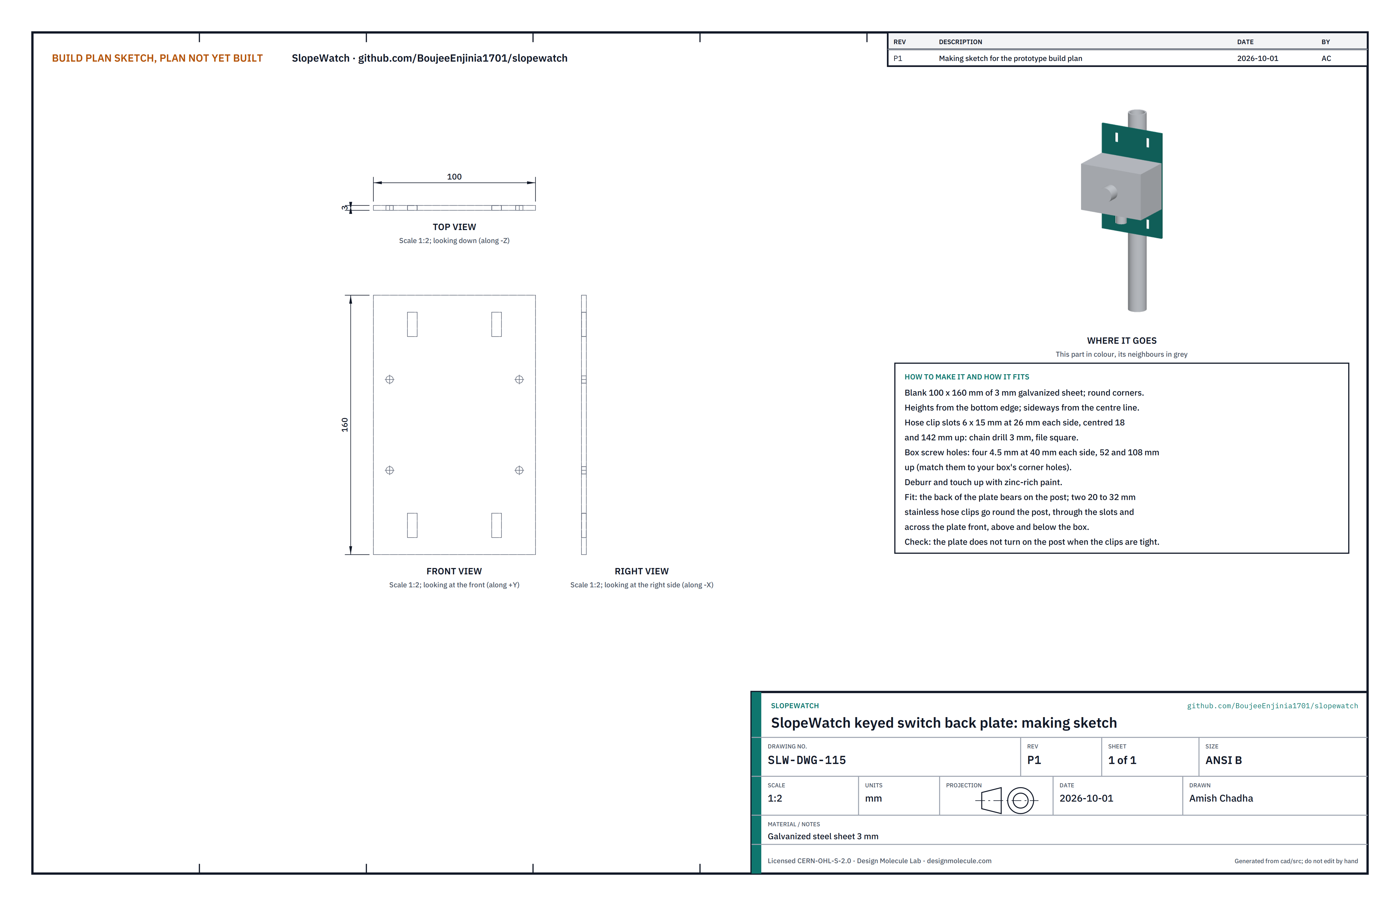
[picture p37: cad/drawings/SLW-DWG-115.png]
Figure 27. Making sketch of the switch back plate


*Figure 27. Switch back plate making sketch (SLW-DWG-115).*

**What it is and what it is made from.** The plate that holds the keyed switch box on its post. Galvanized steel sheet 3 mm, 100 x 160 mm.

**How to make it.** Measure heights up from the bottom edge and sideways from the centre line.

1. Cut the blank and round the corners.
2. Hose clip slots: four slots 6 wide and 15 tall, 26 each side of centre, centred 18 and 142 up; chain drill 3 mm and file square.
3. Box screw holes: four 4.5 mm holes, 40 each side of centre, 52 and 108 up; check them against your box's corner holes first.
4. Deburr and touch up with zinc-rich paint.

**How it fits the parts next to it.**

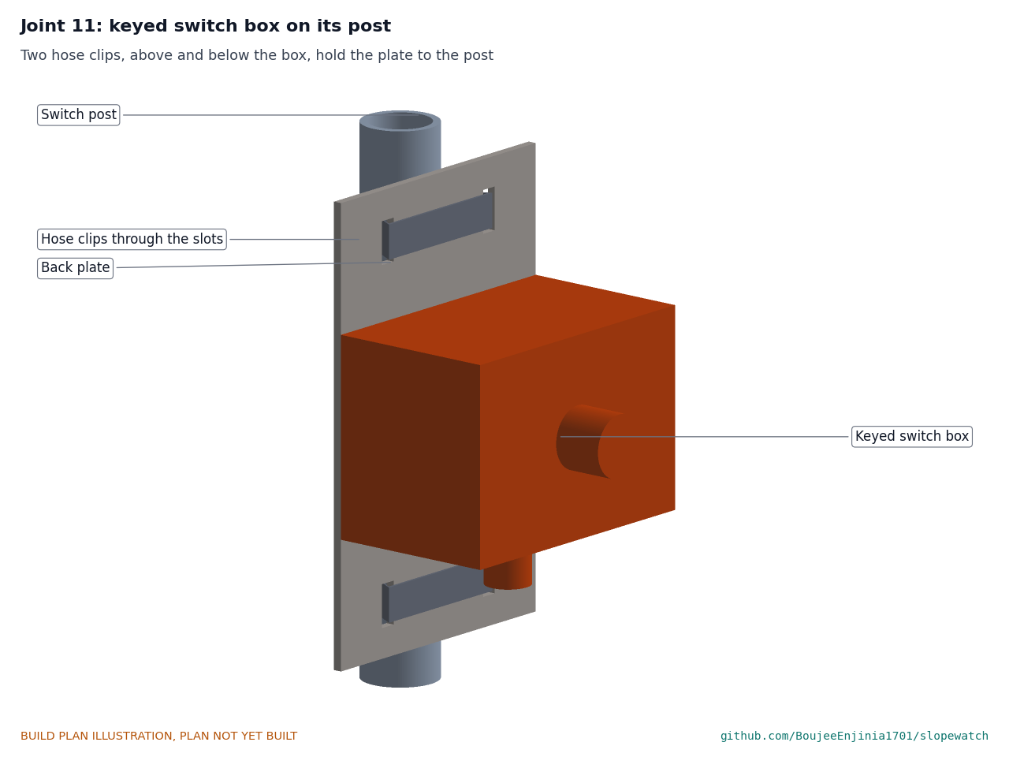
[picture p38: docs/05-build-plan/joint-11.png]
Figure 28. Joint 11: the keyed switch box on its post


*Figure 28. The plate bears on the post; two hose clips, above and below the box, hold it there.*

The switch box (a bought IP65 box, 100 x 60 x 70 mm, with the keyed switch on its front and an M16 gland underneath) is screwed to the plate through its corner holes with four M4 screws.

**Check before moving on.** With the clips tight, the plate does not turn on the post.

### 3.16 Mast (site option)

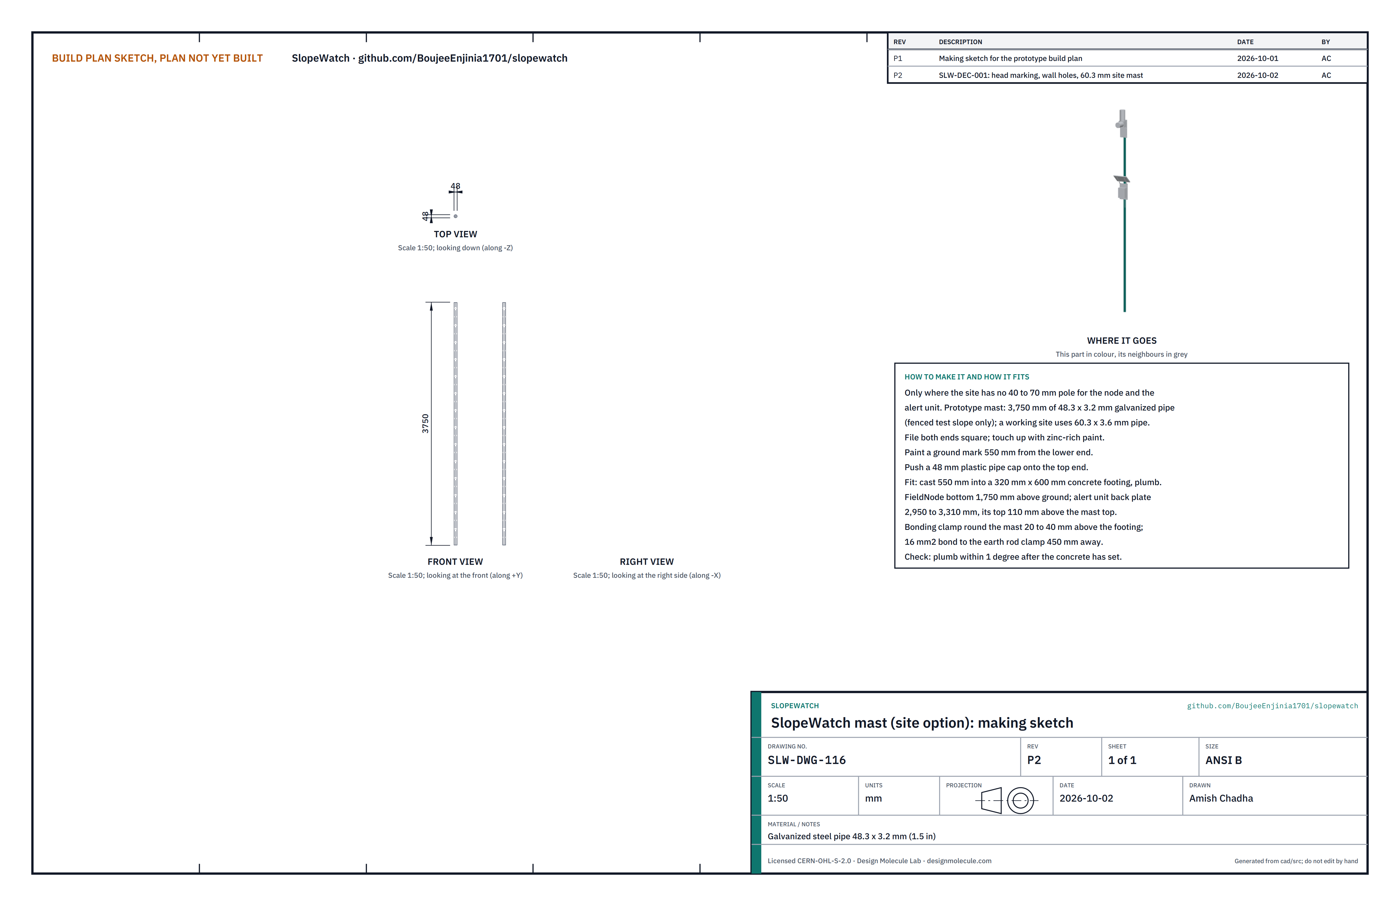
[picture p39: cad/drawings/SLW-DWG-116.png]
Figure 29. Making sketch of the mast


*Figure 29. Mast making sketch (SLW-DWG-116).*

**What it is and what it is made from.** Only where the site has no 40 to 70 mm pole for the FieldNode core and the alert unit. The prototype's mast is galvanized steel pipe 48.3 x 3.2 mm and stands on a fenced test slope only. A mast for a working site is the heavier 60.3 x 3.6 mm pipe, unless local gust data show winds well below 35 m/s (the 48.3 mm pipe has a factor of 1.7 on yield in a 35 m/s gust, the 60.3 mm pipe 2.9); the V-blocks and bands fit both. Pipe, 3,750 mm long, cast 550 mm into a concrete footing 320 mm across and 600 mm deep, with a push-on top cap, a 16 mm earth rod 1.2 m long and a bond.

**How to make it.**

1. Cut 3,750 mm of pipe; file both ends square and touch them up.
2. Paint a ground mark 550 mm from the lower end.
3. Push the cap onto the top end.

**How it fits the parts next to it.**

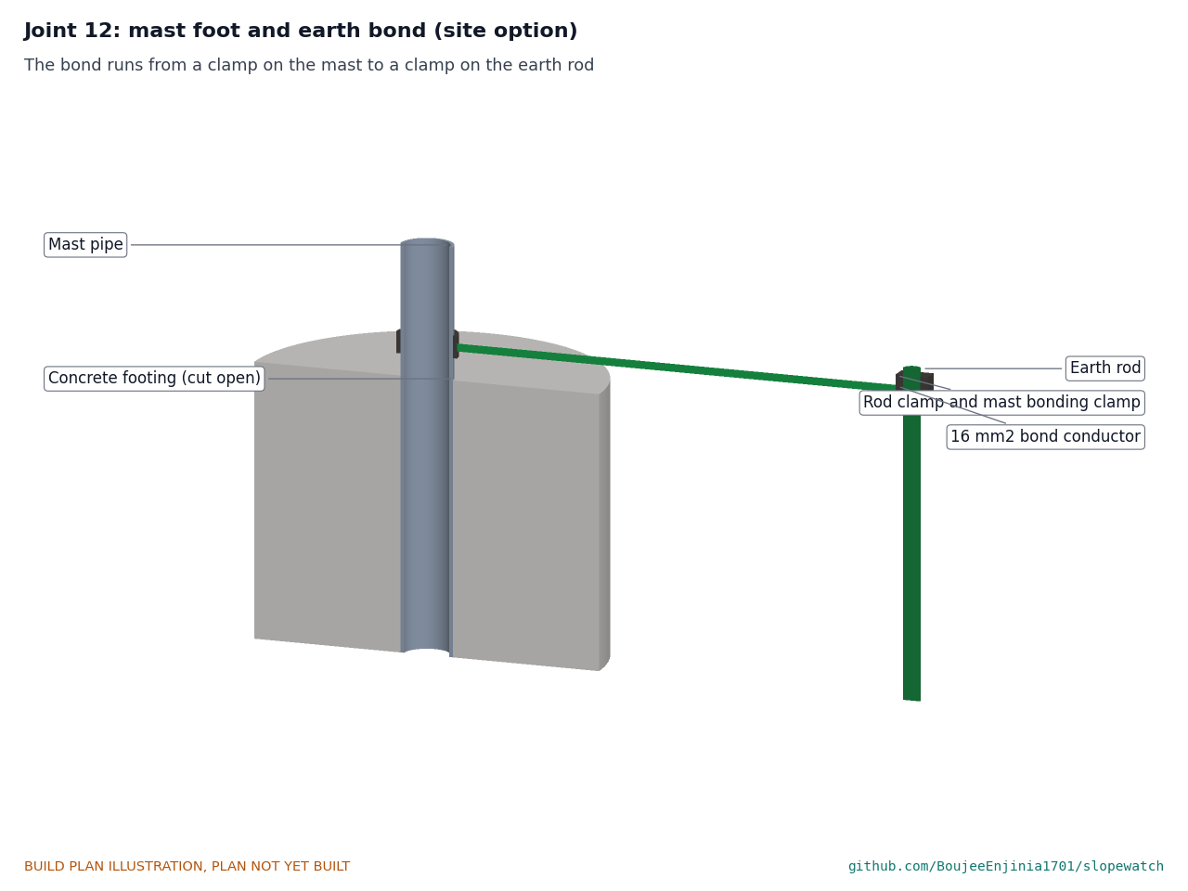
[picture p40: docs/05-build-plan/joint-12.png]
Figure 30. Joint 12: the mast foot and earth bond


*Figure 30. A bonding clamp round the mast just above the footing, a clamp on the earth rod 450 mm away, and a 16 mm² green and yellow conductor between them.*

The FieldNode core's bottom is 1,750 mm above the ground. The alert unit's back plate runs from 2,950 to 3,310 mm, with the siren's centre at about 3.2 m.

**Check before moving on.** Plumb within 1 degree once the concrete has set.

### 3.17 Bus and alert wiring

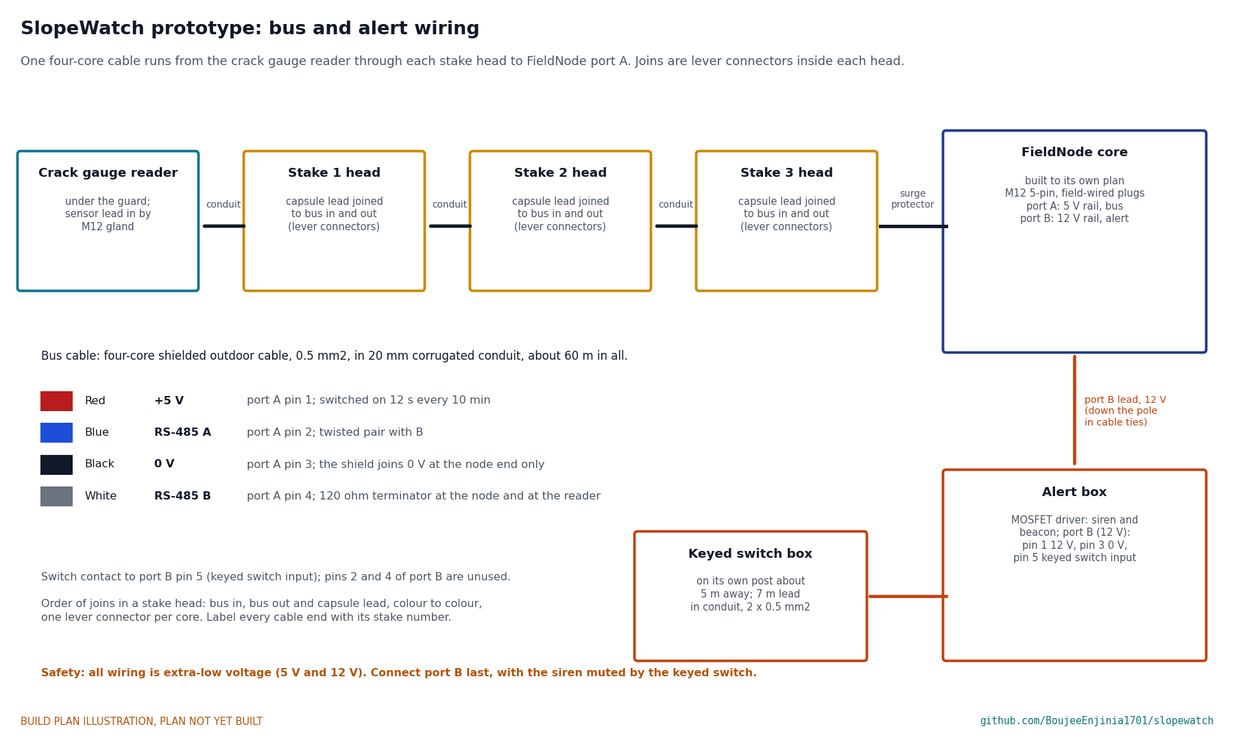
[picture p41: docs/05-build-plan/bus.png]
Figure 31. Bus and alert wiring


*Figure 31. Block-level wiring. One four-core cable chains the reader and the three stake heads to FieldNode port A; the alert box takes port B.*

The bus cable is four-core shielded outdoor cable, 0.5 mm², about 60 m in 20 mm corrugated conduit: red +5 V, black 0 V, blue RS-485 A and white RS-485 B, with the shield joined to 0 V at the node end only and a 120 ohm terminator across A and B at the node and at the reader. In each stake head, join bus in, bus out and the capsule lead colour to colour, one lever connector per core. The bus ends in a field-wired M12 5-pin plug with a surge protector at the node, on port A, the 5 V port: pin 1 +5 V (red), pin 2 RS-485 A (blue), pin 3 0 V (black), pin 4 RS-485 B (white). The alert box takes 12 V from port B, the 12 V port, on a 0.75 mm² lead with its own M12 plug, run down the pole in cable ties: pin 1 12 V, pin 3 0 V, pin 5 the keyed switch input, which joins it on a 7 m two-core lead in conduit; the alert unit leaves pins 2 and 4 of port B unused. Label each port on the node with its rail voltage, 5 V on port A and 12 V on port B, and label each plug with its port. Label every cable end with its stake or box.

**Check before moving on.** With nothing powered, every core reads continuous end to end and no core reads to any other core or to the shield.

### 3.18 Bought components

Buy to specification, not brand. Line numbers are those of the bill of materials.

- **Inclinometer (line 2).** Murata SCL3300 class, run in its ±90 degree mode, on the capsule board.
- **Crack displacement sensor (line 4).** Linear potentiometer, 100 mm stroke, 0.1 % linearity class, 25 mm body or smaller, with an M6 rod-end ball joint at each end and a removable plunger-end joint; plus a spare M6 rod-end ball joint, two M6 studs, an M6 coupling nut and two M8 set screws.
- **Stake head parts (line 3).** 110 x 50 mm concentric drainage reducer whose 50 mm socket is 50 to 51 mm inside; 110 mm drainage pipe and end cap; two M20 IP66 conduit fittings for 20 mm corrugated conduit; three five-way lever connectors per head; two M5 x 16 stainless self-tapping screws per head; for the marking, signal amber paint, 25 mm retroreflective tape about 0.35 m per head, a printed UV-stable vinyl ID label and a vinyl arrow.
- **Bus cable and conduit (line 5).** 60 m of four-core shielded outdoor cable, 0.5 mm², UV and burial rated; 20 mm corrugated UV-rated conduit; conduit clips with ground pegs, one per metre.
- **FieldNode core (line 6).** Built and checked to the FieldNode build plan (FND-BLD-001); its two band clamps fit the pole used here.
- **Alert unit (line 7).** 12 V piezo siren of about 110 dB(A) at 1 m with a sealing flange; 12 V amber LED beacon of about 0.2 A with a gasketed base; two-channel MOSFET driver board; IP65 boxes 120 x 90 x 120 mm and 100 x 60 x 70 mm with corner holes outside the seal; keyed switch rated IP65; two 12 mm stainless band clamps for the pole; two 20 to 32 mm stainless hose clips for the switch post; two M16 glands and one more for the switch box.
- **Mast extras (line 8).** 48 mm push-on plastic pipe cap, 16 mm x 1.2 m earth rod with its clamp, a pipe bonding clamp and 16 mm² green and yellow conductor.
- **Consumables (line 10).** Thread sealant, self-amalgamating tape, polyurethane potting compound and adhesive, zinc-rich paint, medium threadlocker, closed-cell foam backer rod 40 mm for the plugs, cable ties, heat-shrink, dielectric grease, surge protector, marking tape, ground pegs 8 mm x 300 mm, about 25 kg of bagged cement grout for three stakes, and 0.1 m³ of concrete for the mast footing where the mast is used.

## 4. Putting it together

In each picture the parts already fitted are grey and the part being fitted is in colour, with an arrow showing the way it goes in. Steps 1 to 7 are repeated for each of the three stakes. Install the stakes from the top of the slope down, and never work below a stake team.

### Step 1: end cap onto the stake pipe

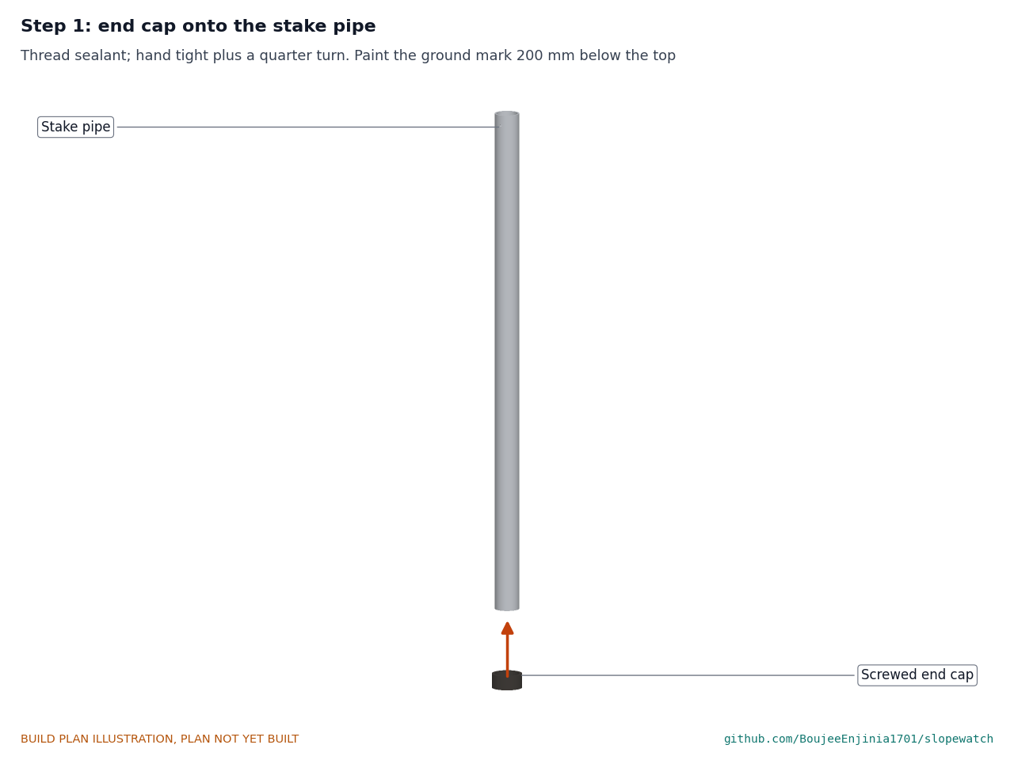
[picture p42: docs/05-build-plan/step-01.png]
Step 1


On the bench. Thread sealant on the thread; screw the cap on hand tight plus a quarter turn. Paint the ground mark 200 mm below the top.

### Step 2: set the pipe and pour the grout

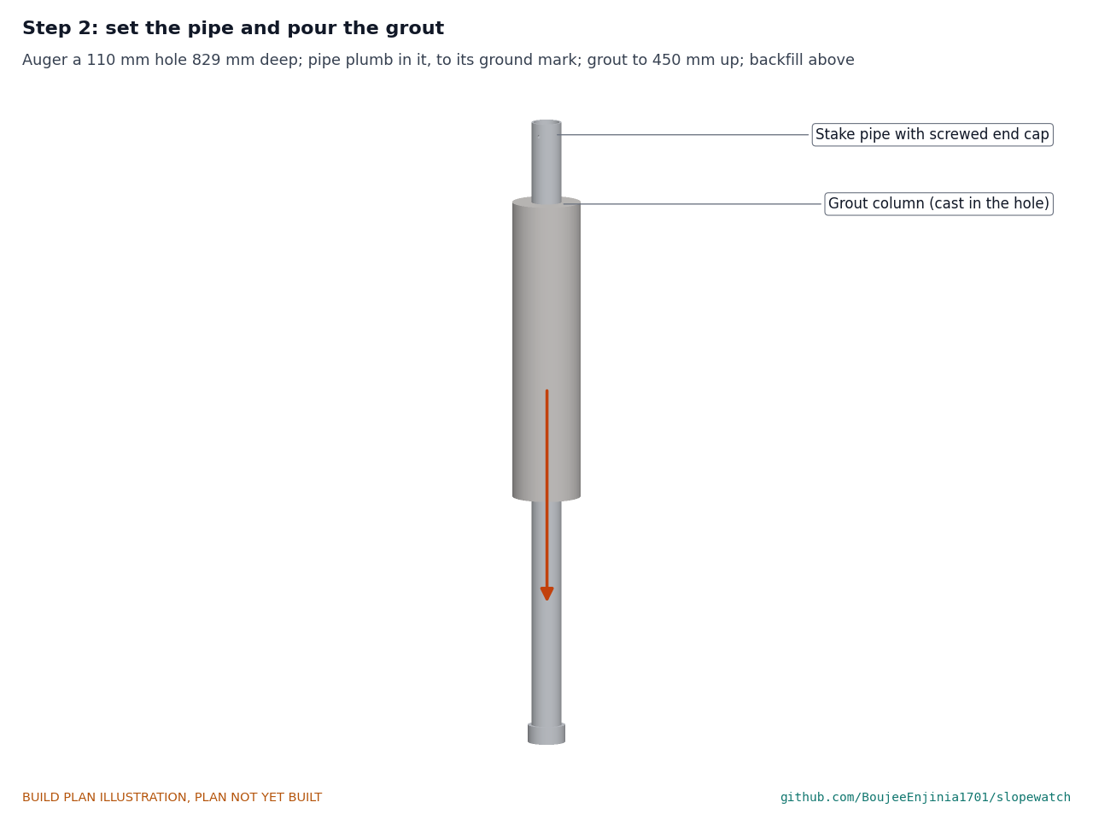
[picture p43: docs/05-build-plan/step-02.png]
Step 2


Auger a 110 mm hole 829 mm deep, square to the slope surface measured with a level on a straight edge laid down the fall line. Mix the grout by hand to a pourable paste. Pour about 20 mm into the bottom, stand the pipe in the hole to its ground mark, hold it plumb with two props, and pour grout round it to 450 mm above its bottom end, rodding out the air. Fill the rest of the hole with soil tamped in layers. **Hold point:** leave the grout 24 h to set before step 3.

### Step 3: stand tube down the pipe

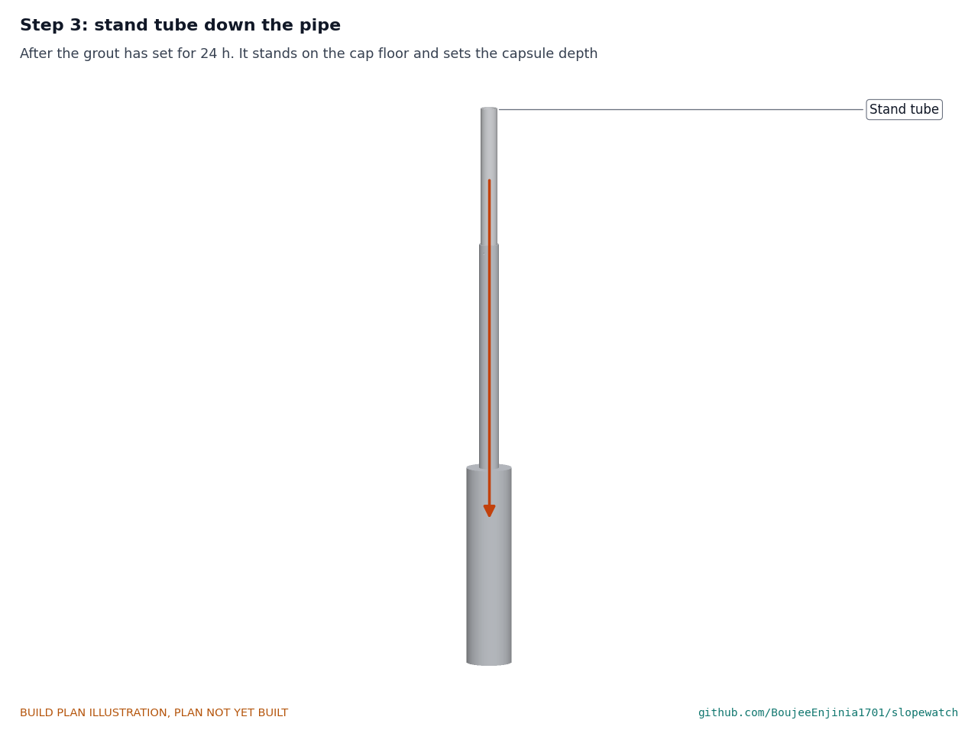
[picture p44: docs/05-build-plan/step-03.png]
Step 3


Drop the stand tube down the pipe; it stands on the cap's floor. Check with a marked rod that its top is 465 mm below the ground mark.

### Step 4: capsule down onto the stand tube

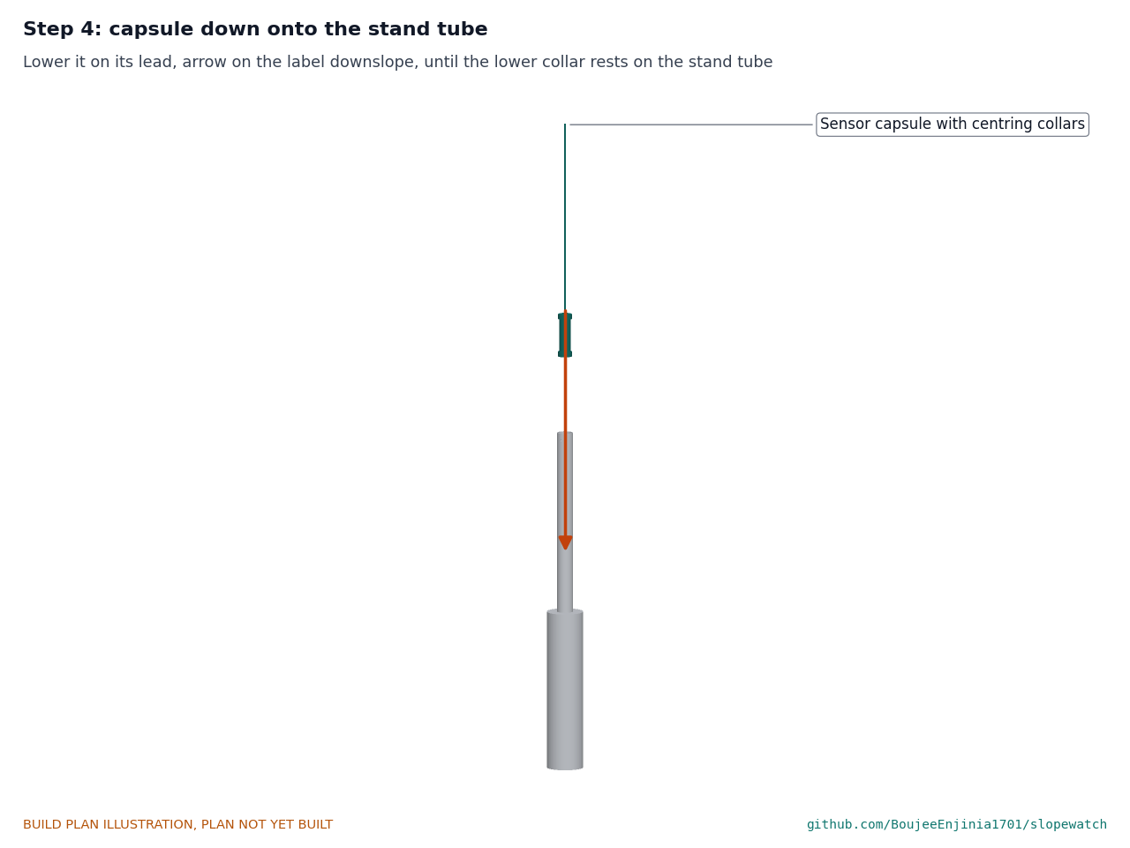
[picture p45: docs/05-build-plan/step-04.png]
Step 4


Turn the capsule so the arrow on its label points downslope, and lower it on its lead, without twisting it, until the lower collar rests on the stand tube.

### Step 5: foam plug above the capsule

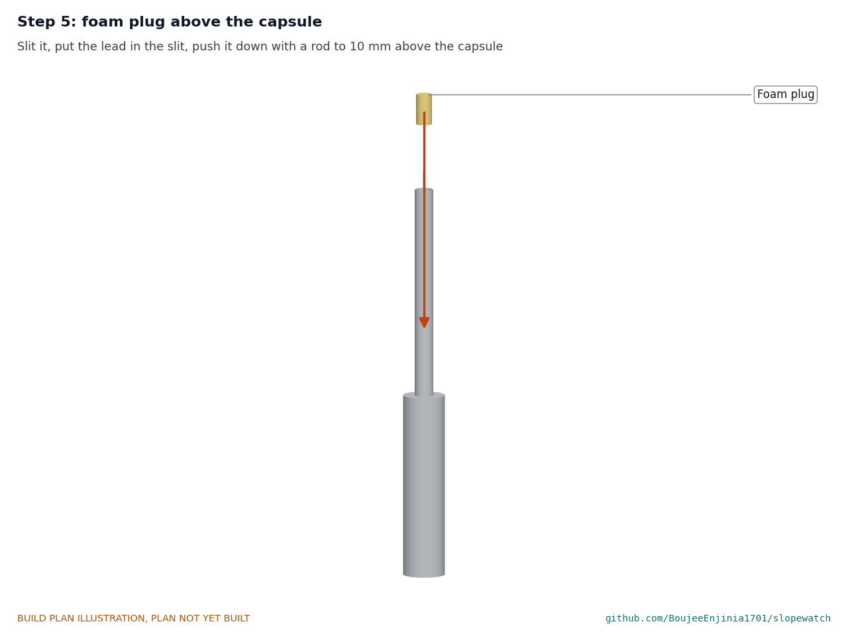
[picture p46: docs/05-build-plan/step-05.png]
Step 5


Slit an 80 mm length of foam backer rod along its length, put the lead in the slit, and push the plug down the pipe with a rod until it is 10 mm above the capsule.

### Step 6: head onto the pipe

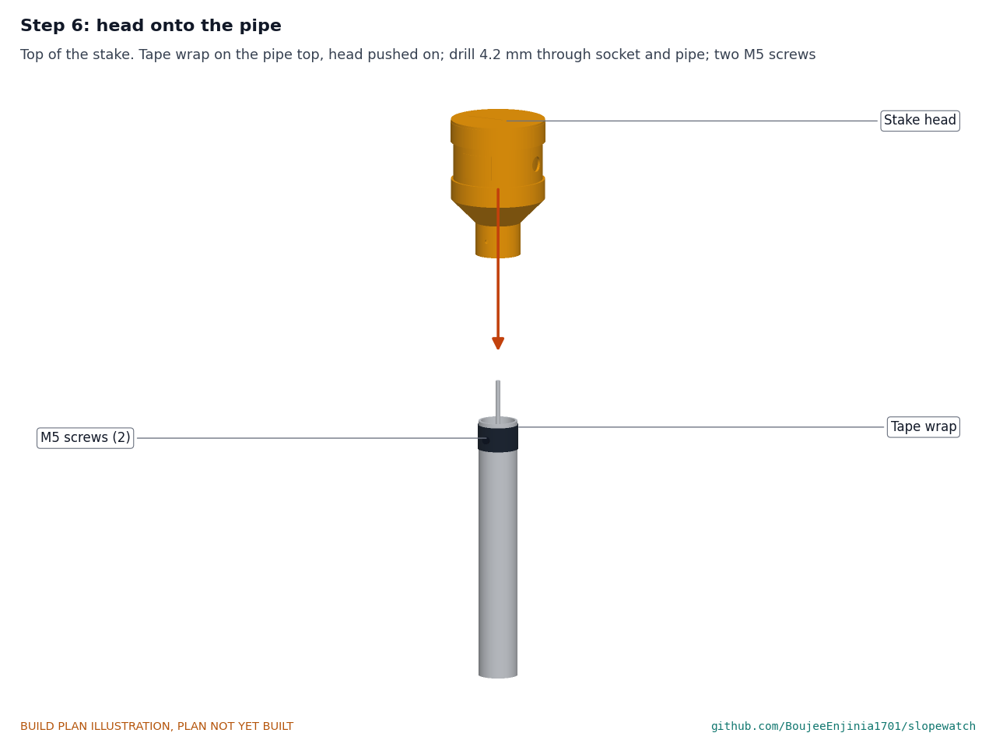
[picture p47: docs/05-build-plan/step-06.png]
Step 6


Wrap three turns of self-amalgamating tape round the top 30 mm of the pipe. Thread the capsule lead through the head and push the head's socket down over the tape until the pipe top meets the reducer. Turn the head so its fittings face upslope and downslope. Drill 4.2 mm through the socket into the pipe on each side, 20 mm above the socket's rim, and drive the two M5 screws.

### Step 7: conduit fittings and the bus

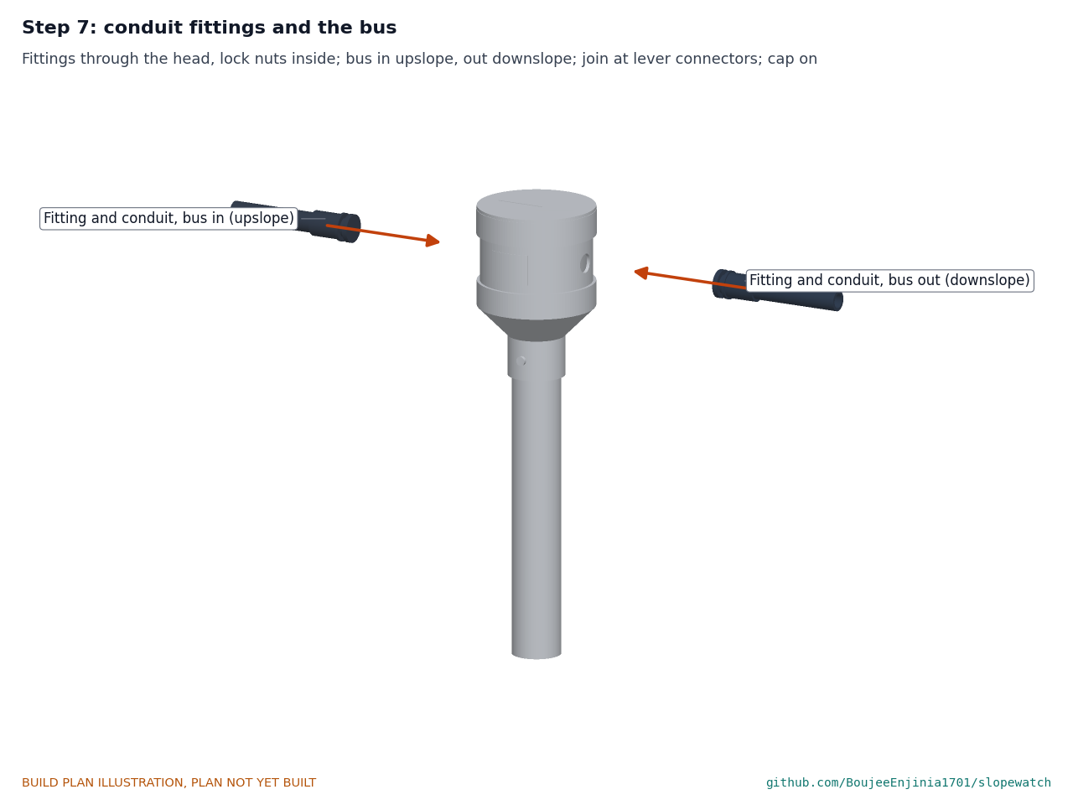
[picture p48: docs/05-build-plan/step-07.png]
Step 7


Fit the two conduit fittings through the head, lock nuts inside. Bring the bus conduit from upslope into the upslope fitting and on to the next stake from the downslope fitting. Join bus in, bus out and the capsule lead at the lever connectors (Figure 31), tuck them into the head, and cement the end cap on. **Hold point:** continuity check of section 3.17 passes for this stake.

### Step 8: drive the anchor pins

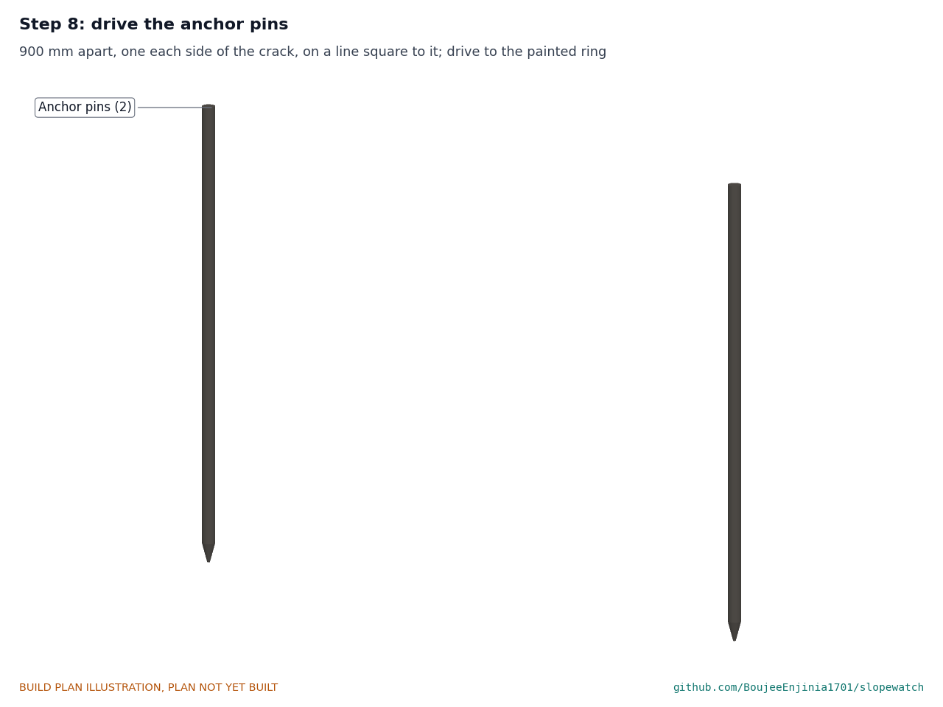
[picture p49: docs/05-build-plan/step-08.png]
Step 8


Mark a line square to the crack. Drive one pin 450 mm each side of the crack on that line, upright, to its painted ring, with a sledge and a driving cap.

### Step 9: clamp blocks onto the pins

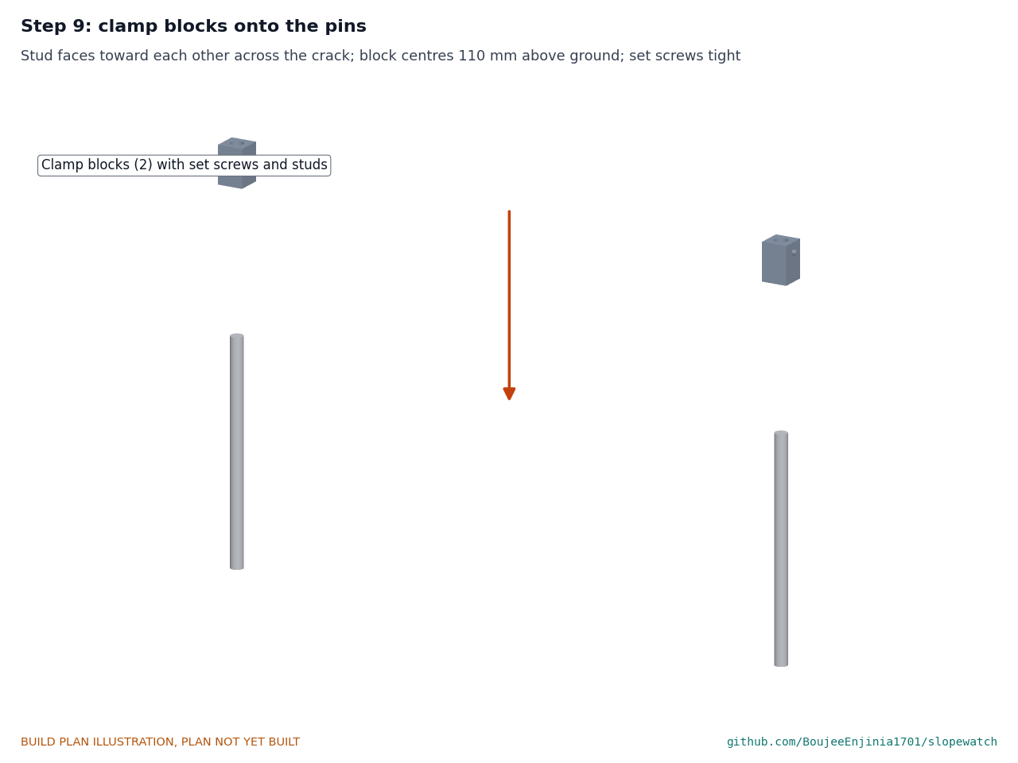
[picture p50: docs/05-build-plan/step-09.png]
Step 9


Slide a block onto each pin with its stud face toward the other pin and its centre 110 mm above the ground; tighten the set screws. Screw a ball joint's stud into each block.

### Step 10: sensor and extension rod onto the studs

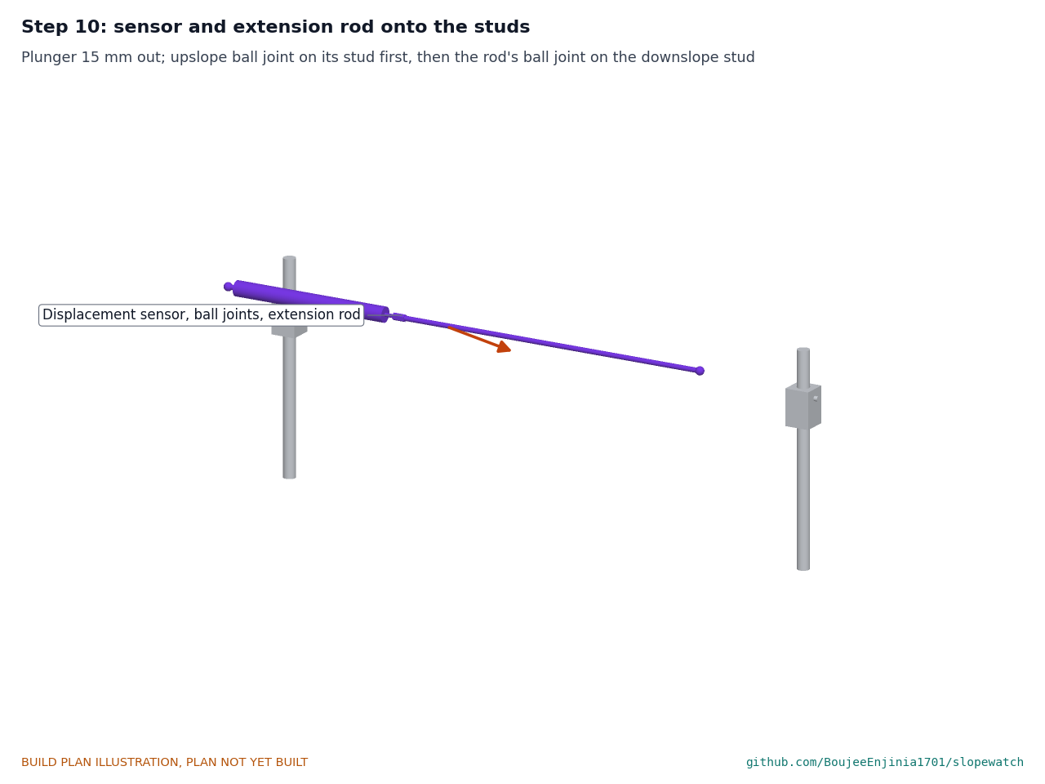
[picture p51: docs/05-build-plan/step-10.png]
Step 10


Set the plunger 15 mm out of the sensor body and tighten the coupling and rod onto it. Fit the sensor's upslope ball joint on the upslope stud, then the rod's ball joint on the downslope stud. Adjust the downslope block's height until the rod is level, then retighten its set screw.

### Step 11: reader box under the guard

Step 11

On the bench, with the guard upside down: two M4 screws with nylon washers through the web into the box's base, lid facing away from the web.

### Step 12: guard over the gauge

Step 12

Plug the sensor lead into the reader and connect the bus conduit to the reader's fitting. Lower the guard over the gauge onto its feet and drive four pegs through the upslope feet.

### Step 13: mast and earth rod (site option)

Step 13

Only where there is no 40 to 70 mm pole. Dig the footing hole 320 mm across and 600 mm deep, 15 m beyond the toe. Pour 50 mm of concrete, stand the mast in it to its ground mark, fill with concrete, plumb it and brace it for 3 days. Drive the earth rod 450 mm away, leaving 50 mm above ground, and fit the clamps and bond. **Hold point:** safety stop S5.

### Step 14: FieldNode core onto the pole

Step 14

Build and check the FieldNode core to its own plan, then clamp it to the pole with its V-blocks and band clamps, its bottom 1,750 mm above the ground, facing the same way as the horn will.

### Step 15: alert box onto its back plate

Step 15

On the bench. Screw the V-blocks to the back of the plate. Screw the alert box to the front through its four corner holes with M5 screws, nyloc nuts on the back of the plate.

### Step 16: alert unit onto the pole

Step 16

With a second person on a stable ladder, hold the unit with the pole in both V-blocks, the siren at least 3 m above the ground and the horn facing the work area. Pass each band round the pole and through its two slots, worm-drive housing behind the pole, and tighten. **Hold point:** safety stop S5.

### Step 17: drive the switch post

Step 17

About 5 m from the pole, on the side away from the horn, with a post driver, to the ground mark.

### Step 18: switch box onto its post

Step 18

Screw the switch box to its plate with four M4 screws. Hold the plate against the post with the box centre 1,300 mm above the ground and fit the two hose clips through the slots, above and below the box.

### Step 19: lay the bus and connect the node

Step 19

Lay the bus conduit on the surface from the reader down through each stake to the pole, pegged every metre, with a slack loop at each stake and at the crack. Run the switch lead in its conduit from the switch post to the pole. Fit the surge protector and the M12 plugs. **Hold point:** safety stops S6 and S7 before port B is connected.

## 5. First checks

These are the checks a TRL 4 test report would record; this plan only lists them. Requirement numbers are those of SLW-REQ-001.

*Table 2. First checks.*

| Check | Requirement | How | Pass when |
| --- | --- | --- | --- |
| Capsule on the bench | R1 | Each capsule on a level bench, then on a 5 degree wedge, read through a USB to RS-485 adapter | Reads level within 0.1 degree; the wedge within 0.1 degree of 5 |
| Capsule centred in the pipe | R1 | Lower a capsule with its collars into a pipe offcut; tilt the offcut 1 degree | The capsule's reading follows the offcut within 0.05 degree |
| Seals | R9 | Look at every gland, fitting, gasket and tape wrap; hose water over a stake head for 5 min | No water inside the head or the boxes |
| Bus continuity | R4, R12 | Meter each core end to end before power | Every core continuous; no core to another core or to the shield |
| Readings every 10 min | R4 | Node powered; log for 1 h | Six readings from each of the three capsules and the gauge |
| Crack gauge range | R3 | Slide the downslope block 10 mm along a test bar, then back | Reading changes by 10 mm within 0.2 mm and returns |
| Local alarm without a network | R5 | Network off; force a warning in the test firmware | Siren and beacon start within 60 s |
| Keyed silence | R5 | Turn the key during a test alarm | Siren stops, beacon stays on, siren re-arms after 30 min |
| Alert rail current | R8 | Clamp meter on the port B lead during a 30 min test alarm | 0.45 A or less, and the node's 12 V rail stays within 5 % |
| Stake installation time | R10 | Time two people installing one stake, steps 2 to 7 | 45 min or less, plus the 24 h grout set |
| Siren level | R7 | Sound level meter at 100 m in open ground and at the switch post | 65 dB(A) or more at 100 m; about 95 dB(A) at the switch post |

## 6. Safety stops

Stop at each point. Carry on only when everything listed is true.

- **S1. Before anyone goes onto the slope.** A competent person has looked at the slope that day; no one will work below an actively moving face or overhanging material; there is a spotter and a clear escape route; it is not raining hard and has not been; for a tailings dam, the owner's permit and the engineer of record's agreement are in hand.
- **S2. Before augering or driving.** Buried services have been checked with the site owner; the auger operator has a firm stance; no one stands downslope of the auger or the sledge.
- **S3. Before mixing grout.** Gloves, eye protection and long sleeves on; clean water at hand to wash off splashes.
- **S4. Before the FieldNode cell goes in.** Every safety stop of the FieldNode build plan has been passed.
- **S5. Before raising the mast or climbing to fit the alert unit.** Two people; a stable ladder footed by the second person; no overhead power line within reach of the mast or ladder; the mast's concrete has set for at least 3 days; the earth bond is fitted. The prototype mast stands only on a fenced test slope, and no one stands under it in high wind.
- **S6. Before the siren first sounds.** Hearing protection on everyone within 10 m; neighbours and site workers told that a test is coming, so a test is not taken for a real alarm.
- **S7. Before leaving the site.** The keyed switch is locked with its key held by the named person; every SMS recipient knows the system is a research prototype; signs at the site say what SlopeWatch cannot detect. Until a geotechnical partner has set the site's thresholds, the system logs only and raises no public alarm.

## 7. Tools, skills and workspace

**Tools.** Hacksaw with a 24 teeth per inch blade (or a bandsaw); pipe cutter and pipe wrench; bench vice with soft jaws; bench drill with a V-block; drills 2.5 to 20.5 mm; step drill to 20 mm; countersink; M4, M6 and M8 taps and tap drills; flat and half-round files; deburring tool; scriber, engineer's square, 45 degree square, steel rule, tape and calipers; aviation snips and two 1.2 m steel angles (or a sheet metal shop) for the guard; 3D printer that prints ASA; soldering iron, wire strippers and ferrule crimper; multimeter and clamp meter; USB to RS-485 adapter and laptop; hand post-hole auger 110 mm and an extension to 0.9 m; sledge hammer with a driving cap; post driver for the switch post; spirit level and a 1.5 m straight edge; bucket, trowel and rodding bar for grout; spade and shovel; stable ladder; sound level meter; stopwatch.

**Skills.** No certified trade is needed. Basic metalwork (marking out, sawing, drilling, tapping, filing), simple sheet folding or the use of a sheet metal shop, potting electronics, through-hole soldering and crimping, mixing and placing grout and concrete, and safe work on slopes with a trained team. All circuits are extra-low voltage: 5 V on the bus and 12 V on the alert unit, from the FieldNode cell. No mains wiring is part of this build.

**Workspace.** A workshop bench about 1.2 x 0.6 m with a metalwork corner kept apart from the electronics, a ventilated place for the printer and for potting, and a test slope with a partner's permission for steps 2 to 19.

**Personal protective equipment.** Safety glasses for cutting, drilling, driving and grouting; cut-resistant gloves for sheet and bar, chemical-resistant gloves for grout and potting; hearing protection when sawing, driving and testing the siren; safety boots and a hard hat on the slope; no gloves near a turning drill.

## 8. Where the numbers come from

- Model and constructability checks: `cad/src/model.py` (`python cad/src/model.py --check`, 79 checks); STEP and STL exports in `cad/step/` and `cad/stl/`.
- Pictures: `cad/src/build_plan_media.py`, using `.kit/build_views.py`; written to `docs/05-build-plan/` and `cad/drawings/SLW-DWG-101` to `SLW-DWG-116`.
- General arrangement: `cad/drawings/SLW-DWG-001.pdf`, Rev P5.
- Calculations: `docs/04-calcs/01-sizing.md` (SLW-CAL-001 v0.4) and `docs/04-calcs/sizing.py`; crack gauge [C2], siren level [E5], mast [H1] to [H4] and the site mast [H2b], [H2c], installation [I1], [I2], cost [K2], [K3].
- Bill of materials: `bom/bom.csv` and `bom/bom-notes.md`.
- Decisions: `docs/decisions/0003-design-for-construction.md` (SLW-DDR-003), with SLW-DDR-001 and SLW-DDR-002; design decisions register `docs/06-design-decisions.md` (SLW-DEC-001).
- Requirements: `docs/03-requirements.md` (SLW-REQ-001 v0.7).
- FieldNode core: the FieldNode repository, build plan FND-BLD-001 and decision record FND-DDR-003.

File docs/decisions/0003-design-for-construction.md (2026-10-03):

---
doc_id: SLW-DDR-003
title: SlopeWatch design for construction
project: SlopeWatch
doc_type: Design decision record
version: "0.3"
status: Draft
date: '2026-10-02'
author: Amish Chadha
license: CERN-OHL-S-2.0
revisions:
- version: "0.1"
  date: '2026-10-01'
  author: Amish Chadha
  change: Changes that make the concept physically buildable, with the reason for each; made under Amish's 2026-09-30 instruction to make the design physically buildable; open for his review
- version: "0.2"
  date: '2026-10-02'
  author: Amish Chadha
  change: Accepted by Amish, including A1 (sharpened), A2 and A3
- version: "0.3"
  date: '2026-10-02'
  author: Amish Chadha
  change: "A1 to A3 carried into the model, BOM, calculations and pictures: wall holes in the alert back plate, 60.3 mm site mast priced and calculated, cost USD 304.00 with the stake head marking"
---

# 0003: Design for construction

- **Date:** 2026-10-01
- **Status:** accepted. Amish, 2026-10-02: "i approve your recommendations for all 555 open decisions." This covers every change in Tables 1 and 2 and the recommendations for A1 to A3 in Table 3, as written for the register on 2026-10-01 (SLW-DEC-001); A1 was sharpened to set conditions for the prototype and for site installations. The changes were made under Amish's 2026-09-30 instruction to make the design physically buildable.

## Context

On 2026-09-30 Amish asked for every repo to get an illustrated prototype build plan and wrote: "If you are realising that the design cannot be built as per concept - fix the design assumptions to match and be physically feasible as you draw the illustrations." The SlopeWatch model of SLW-DDR-002 showed what the system does but several of its parts could not be made, fixed or joined as drawn. Checking the concept model with build123d (overlap volumes and gaps between parts) and going through how each part is made and fixed found the eleven problems in Table 1.

The changes keep what SlopeWatch does: the same three grouted tilt stakes 0.8 m deep with the capsule 0.4 m below ground, the same crack gauge span and stroke, the same bus, FieldNode core, siren, beacon, keyed switch post and optional mast, the same alert rules and the same reference site. Every change is in `cad/src/model.py`, which now builds each component separately and runs 79 constructability checks (`python cad/src/model.py --check`): parts that must touch do touch, and parts that must not touch are apart by at least the stated clearance. All 79 pass.

## Decision

*Table 1. Changes made to the model, the BOM and the calculations.*

| # | Problem in the concept | Change made | Why this way |
| --- | --- | --- | --- |
| P1 | The capsule (34 mm) sat loose in the 41.9 mm pipe bore between two foam plugs, 3.95 mm from the wall, with nothing setting its depth or holding it on the pipe axis. A tilt sensor that can lean in its bore does not read the pipe's tilt. | Two 3D-printed ASA centring collars (41.5 mm outside, 15 mm long) glued flush on the capsule ends, a slip fit in the bore (0.2 mm clearance). A 40 mm PVC stand tube, 335 mm long, stands on the bottom cap inside the pipe; the lower collar rests on its rim, which puts the capsule centre 0.4 m below ground. The foam plug above the capsule stays; the one below is replaced by the stand tube. | The collars make the capsule turn with the pipe; the stand tube sets the depth without measuring down a hole. The closed air column inside the stand tube still stops convection below the capsule, so the thermal case of SLW-CAL-001 section B stands. |
| P2 | The pipe bottom was "plugged" with an unspecified 20 mm internal plug. | The pipe is bought threaded at the bottom and closed with a screwed 1.5 in malleable-iron end cap with thread sealant. The hole is augered 829 mm deep (was 820) so 20 mm of grout runs under the cap. | A stock fitting that keeps grout and ground water out; the merchant who cuts the pipe threads it. |
| P3 | The stake head was a 120 mm PVC cap with a "reducer ring" inside, which is not a stock part, and nothing fixed it to the pipe. | A head from stock 110 mm PVC drainage parts: a 110 x 50 mm concentric reducer whose 50 mm socket slides over the pipe on a self-amalgamating tape wrap, 94 mm of 110 mm pipe and a 110 mm end cap, solvent-cemented. Two M5 stainless self-tapping screws go through the socket into the pipe wall, drilled in place. Head height above ground unchanged (330 mm). | Every part is sold by plumbers' merchants; the tape takes up the 1.9 mm between the 50.2 mm socket and the 48.3 mm pipe and seals it; the screws stop the head being lifted or turned. The bare pipe between ground and head stays 160 mm, so the pipe-heating case is unchanged. |
| P4 | One M20 cable gland on the head, facing downslope, for a bus that must come into every stake and go on to the next. A cable gland also cannot grip corrugated conduit. | Two M20 IP66 conduit fittings for 20 mm corrugated conduit, one upslope (bus in) and one downslope (bus out), with lock nuts inside the head. The bus in, bus out and capsule lead are joined core to core with lever connectors inside the head. | A daisy-chained bus needs an in and an out at each stake; the fittings are the high point of each conduit run, so water in the conduit drains away from the head. |
| P5 | The crack gauge clamps were solid 60 x 60 x 80 mm blocks round the pins with no way to fix the sensor, and the sensor body and rod simply butted against them. | Clamp blocks from 40 x 40 mm aluminium bar, 60 mm tall, bored 20.5 mm for the pin and held by an M8 set screw on their outer face; an M6 rod-end ball joint on a stud on each block's inner face. The sensor body hangs on the upslope ball joint; its plunger joins an 8 mm stainless extension rod through an M6 coupling nut; the rod's far end screws into the downslope ball joint. | Ball joints let the crack open, close or shear without bending the sensor; the set screws let the blocks be re-set on the pins after 100 mm of opening. Both blocks are the same part. The rod is 501 mm (was 580 mm), which lowers the gauge's thermal swing from 0.39 to 0.36 mm a day [C2]. |
| P6 | The guard intersected both anchor pins (12,566 mm³ of overlap) and floated 50 mm above the ground with no fixing. | A channel folded from 1.5 mm galvanized sheet, 1,150 long, 200 wide and 250 high, with 25 mm feet, standing on the ground 48 mm above the pin tops, held by four 8 mm ground pegs through the feet on the upslope half only. | Clears every part of the gauge; pegging only the upslope half lets the ground open under the downslope half without the guard holding the crack together. |
| P7 | The reader box floated 20 mm from the gauge with no fixing. | The box hangs under the guard web at the upslope end, lid down, on two M4 screws with nylon sealing washers, 12 mm clear of the upslope pin; the bus leaves through an M20 conduit fitting on its downslope end and out of the open downslope end of the guard. | Protected by the guard, fixed to the half of the guard that is pegged, and reachable by lifting the guard. |
| P8 | The alert unit (siren box, horn, beacon) stood on the open top of the mast pipe with no fixing, and could not go on an existing pole, which is the reference site (SLW-DDR-002). | The siren driver is in a bought IP65 alert box (120 x 90 x 120 mm) with the horn on its front and the beacon on its top. The box is screwed through its corner holes to a 160 x 360 x 3 mm aluminium back plate, which clamps to the pole or mast with two V-blocks and two band clamps through slots, the same fixing as the FieldNode core. On the mast, the plate's top stands 110 mm above the mast top so the beacon clears it; the siren centre is 3.23 m above ground (was 3.26 m). The mast gets a push-on top cap. | One fixing that works on an existing 40 to 70 mm pole and on the mast; the parts are the FieldNode's (FND-DDR-003), so the maker learns one method. |
| P9 | The keyed switch box floated 5 mm off its post. | A 100 x 160 x 3 mm galvanized back plate bears on the post and is held by two stainless hose clips through slots, above and below the box; the box is screwed to the plate through its corner holes. | Hose clips fit the 26.9 mm post and need no drilling of the galvanized tube. |
| P10 | The FieldNode massing showed the concept V-blocks (50 x 20 x 30 mm boxes 0.9 mm off the pole) and bracket posts floating 13.5 mm off the back plate. | The massing now follows the FieldNode constructable design (FND-DDR-003): V-blocks 60 x 33 x 20 mm with a true 90 degree V touching the pole, two band clamps through slots 51 mm each side of centre, and bracket bars meeting the plate and panel. FieldNode is still built to its own plan (FND-BLD-001). | SlopeWatch shows the node as it will be built, without taking over its design. |
| P11 | The earth bond ran into the mast pipe with no clamp at either end. | A bought earth-rod clamp on the rod, a bonding clamp round the mast 20 to 40 mm above the footing and a 16 mm² green and yellow bond conductor between them. | The usual way to bond a steel mast to an earth rod. |

*Table 2. Knock-on changes.*

| Item | Change | Reason |
| --- | --- | --- |
| BOM | Lines 1, 2, 3, 4, 7, 8 and 10 respecified and repriced. Reference site $245.00 to $296.50, $46.50 over the unchanged $250 value-engineering target (`budget_usd`); $324.50 with the optional mast [K2], [K3]. | Parts added to make the design buildable. |
| Calculations | SLW-CAL-001 v0.3: crack gauge thermal swing 0.36 mm a day [C2]; siren height 3.23 m, level at the keyed switch 95.5 dB(A), 42 min NIOSH allowance [E5]; mast in a 35 m/s gust 136 MPa, factor 1.7 on yield (was 113 MPa, 2.1), footing factor 2.2 (was 2.7), because the alert unit's back plate is now counted in the wind area [H1] to [H4]; hole 829 mm, 3.68 L of grout [I1]; installation 44 min (was 43) [I2]. No requirement changes status except R11, now reported against the value-engineering target. | Follows the model. |
| Drawing | SLW-DWG-001 Rev P3 to P4; making sketches SLW-DWG-101 to 116 added. | Follows the model. |
| Documents | SLW-PRC-001 v0.5, SLW-REQ-001 v0.5, SLW-CAL-001 v0.3; build plan SLW-BLD-001 and design decisions register SLW-DEC-001 added. | Follows the model. |
| Appearance model | `cad/src/product_model.py` and the photoreal renders (`media/render-*.png`), `media/card.png` and `media/social-preview.png` still show the concept head (120 mm cap, single gland, drip loop) and are stale. The appearance session's proposed cap screws (2026-09-26 item 3) are now part of the design as the two head screws; its conduit stub (item 4) is replaced by the two conduit fittings. | Renders are made on Amish's Mac. |

*Table 3. Proposed for Amish; A1 to A3 decided on 2026-10-02.*

| # | Question | Options | Recommendation |
| --- | --- | --- | --- |
| A1 | The side-mounted alert unit lowers the optional mast's margin in a 35 m/s gust from a factor of 2.1 to 1.7 on yield [H2]. | (a) accept 1.7 for the prototype; (b) narrow the alert back plate below the box to cut its wind area; (c) a 60.3 mm mast where the mast option is used. | (a) for the prototype, with the mast checked against local wind data before a site installation. Decided on 2026-10-02: (a) for the prototype on a fenced test slope with no one under the mast in high wind; any site installation uses (c), the 60.3 mm mast, unless local gust data show winds well below 35 m/s. |
| A2 | The pole fixing (V-blocks and band clamps) fits round poles of 40 to 70 mm. The reference site says "an existing pole or building", and many existing poles are larger timber poles. | (a) state the reference site as a 40 to 70 mm round pole, the mast otherwise; (b) add four wall holes to both back plates so the node and alert unit can be coach-screwed to a timber pole or wall; (c) longer bands and a wider V for large poles. | (b): it keeps the "pole or building" scope with no new part. Accepted by Amish, 2026-10-02; the back plate change is to be agreed with FieldNode. |
| A3 | Which pole the first prototype goes on. | (a) build the optional mast, so the prototype stands alone on a test slope; (b) use an existing 48 mm pole at the test site. | (a). Accepted by Amish, 2026-10-02. |

## Consequences

- With A1 to A3 decided (and now carried into the model, BOM and calculations: the alert back plate has four 6.5 mm wall holes, the 60.3 mm site mast is calculated as SLW-CAL-001 [H2b] and priced as BOM line 11, and the reference site is USD 304.00, USD 54.00 over the target with the stake head marking), the first prototype stands on the optional mast on a fenced test slope, both back plates get four wall holes (to be agreed with FieldNode), and site installations use the 60.3 mm mast unless local gust data allow the 48.3 mm one.
- `design_state: constructable` in `project.yaml`. The build plan SLW-BLD-001 shows every component and step in pictures generated from the model (`cad/src/build_plan_media.py`).
- Requirement status (SLW-CAL-001 v0.3): 0 not met, 4 at risk (R6, R7, R8, R9), 4 met on paper, 2 met by design, 2 not verifiable at TRL 3, and R11 over the value-engineering target by $46.50.
- The capsule's board size, the stake head's socket fit on the pipe, the sensor's rod ends and the alert and switch boxes' corner holes are checked when parts are bought (SLW-DEC-001).
- TRL 4 stays on hold by Amish's instruction; nothing here authorizes building or testing.

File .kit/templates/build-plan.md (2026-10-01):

---
doc_id: PRJ-BLD-001
title: Project prototype build plan
project: Project name
doc_type: Build plan
version: "0.1"
status: Draft
date: YYYY-MM-DD
author: Amish Chadha
license: CERN-OHL-S-2.0
revisions:
  - version: "0.1"
    date: YYYY-MM-DD
    author: Amish Chadha
    change: First build plan; design made constructable
---

# Project prototype build plan

**Plan, not yet built.** How to build the first proof-of-concept prototype, component by component. Building and testing to it is TRL 4 work. Decisions still to be made are kept in the design decisions register (`docs/06-design-decisions.md`), not here.

## 1. What you are building

Every component, pulled apart and numbered in build order

One short paragraph: what the prototype is, how many components, which are made and which are bought, and the main ways they are made.

## 2. What changed to make it buildable

| Component | The concept had | The buildable design has | Why |
| --- | --- | --- | --- |

## 3. Making the components

### 3.1 Component name

Making sketch

**What it is and what it is made from.**

**How to make it.**

1. Mark out ...
2. Cut ...

**How it fits the parts next to it.**

Close-up of the joint

**Check before moving on.**

## 4. Putting it together

### Step 1: ...

Step 1

## 5. First checks

| Check | Requirement | How | Pass when |
| --- | --- | --- | --- |

## 6. Safety stops

## 7. Tools, skills and workspace

## 8. Where the numbers come from

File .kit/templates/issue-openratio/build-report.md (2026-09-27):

---
name: Build report
about: Tell us what happened when you built, printed or tested part of this design
title: "Build report: "
labels: build-report
---

This is a research and educational prototype, not a medical device. It is a TRL 3 concept and is not released for fabrication. If you build any part of it, you do so at your own risk. Reports help everyone.

**What you built** (part, sub-assembly or test)

**Materials, tools and settings**

**What worked**

**What did not work, with photos or measurements if you have them**

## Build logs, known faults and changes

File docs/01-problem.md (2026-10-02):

---
doc_id: SLW-PRB-001
title: SlopeWatch problem statement
project: SlopeWatch
doc_type: Problem statement
version: "0.5"
status: Draft
date: '2026-10-02'
author: Amish Chadha
license: CERN-OHL-S-2.0
revisions:
- version: "0.1"
  date: '2026-09-25'
  author: Amish Chadha
  change: Initial scaffold
- version: "0.2"
  date: '2026-09-25'
  author: Amish Chadha
  change: Populate to TRL 2 (users, context, constraints, scope limits, cited prior work)
- version: "0.3"
  date: '2026-09-25'
  author: Amish Chadha
  change: Reflect SLW-DDR-001 (budget covers SlopeWatch-specific parts; tailings dams kept with limits); open questions updated
- version: "0.4"
  date: '2026-09-25'
  author: Amish Chadha
  change: Recommendations accepted by Amish (DDR-002)
- version: "0.5"
  date: '2026-10-02'
  author: Amish Chadha
  change: First partner and site type to approach, decided on 2026-10-02 (SLW-DEC-001)
---

# SlopeWatch problem statement

Many slope failures at mines and on hillsides are preceded by hours to months of slow, accelerating movement, but the people most exposed (workers at small mines and communities below waste dumps and steep slopes) rarely have any instrument that would show it. SlopeWatch aims to give them a low-cost, open network of tilt and crack sensors that measures the rate of movement and sounds a local alarm when it accelerates. Design with, not for: requirements must come from co-design sessions and field trials with the intended users through a local partner.

## The problem

Landslides are a large and growing cause of death. A global database of non-seismic fatal landslides recorded 4,862 events that killed 55,997 people from 2004 to 2016, 75 % of them in Asia, and found that landslides triggered by human activity, in particular construction, illegal mining and hill cutting, are increasing ([Froude and Petley, 2018](https://nhess.copernicus.org/articles/18/2161/2018/)). Mining adds its own hazards: tailings dams, waste dumps and pit walls. The failure of the Fundão tailings dam at Mariana, Brazil, in 2015 killed 19 people ([UK House of Commons Library](https://commonslibrary.parliament.uk/research-briefings/cdp-2023-0133/)), and the collapse at Brumadinho in 2019 killed 270 and released 9.7 million m³ of tailings ([Zhu, Zhang and Puzrin, 2024](https://www.nature.com/articles/s43247-023-01086-9)).

Many of these failures give warning through movement that speeds up before collapse. Satellite radar analysis of the 2020 Hpakant jade mine disaster in Myanmar, which killed at least 172 miners, found accelerated motion in the half year before the failure ([Hpakant multi-sensor study, 2021](https://www.sciencedirect.com/science/article/pii/S0924271621001489)). Plotting the inverse of surface velocity against time has been used since the 1980s to forecast the time of slope failure ([Fukuzono, 1985](https://www.jstage.jst.go.jp/article/jls1964/22/2/22_2_8/_article)).

Three gaps keep this knowledge from protecting people at small sites:

1. **Cost and skill.** Slope radar, robotic total stations and in-place inclinometer strings are designed for large operations with geotechnical staff. An estimated 44 million people work in artisanal and small-scale mining in 80 countries ([World Bank, 2021](https://www.worldbank.org/en/news/press-release/2021/05/03/better-working-conditions-can-improve-safety-and-productivity-of-artisanal-and-small-scale-miners-around-t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)), and almost none of their pits, dumps or nearby hillsides are instrumented.
2. **No local alarm.** Where low-cost sensors are used, data often goes to a remote server that a site worker never sees. People on or below the slope need a siren and a light that work even when the network is down.
3. **Rate, not position.** A single survey of position says little. What matters is whether movement is steady, slowing or accelerating, which needs frequent, automatic readings and a simple rule that turns them into a warning.

Not every failure gives useful warning. The Brumadinho dam showed only about 30 mm of surface displacement in the year before a brittle failure, despite being fully instrumented ([Zhu, Zhang and Puzrin, 2024](https://www.nature.com/articles/s43247-023-01086-9)). SlopeWatch targets slopes that move progressively, and must say plainly that it cannot warn of every failure mode.

## Users and context

| User | Need | Context |
| --- | --- | --- |
| Small-scale or artisanal mine operator | Know when a pit wall, bench or waste dump is starting to move, and clear people from it in time | Open pits and dumps, often informal; little or no geotechnical support; workers below the slope all day |
| Mine or quarry site manager at a medium site | A low-cost first layer of monitoring on dumps and benches not covered by the main system | Some engineering staff; mobile coverage variable |
| Community below a slope or dump | A siren and light they trust, and a named person who receives alerts | Villages below waste dumps, road cuts or landslide-prone hillsides |
| Local government or civil protection officer | Readings they can act on, and a record of what happened | District disaster office, often with one staff member for a large area |
| Geotechnical engineer or university partner | Raw, time-stamped data in an open format to interpret movement and set thresholds | Visits occasionally; works remotely |

### Operating environment

- **Ground:** residual soil, weathered rock, loose dump material or compacted fill; slopes of about 15 to 45 degrees; stakes installed in the upper 1 m.
- **Climate:** ambient -10 to 50 °C at the surface in sun; heavy monsoon or tropical rain (the main trigger for most landslides); dust in the dry season.
- **Power and data:** no mains on the slope; mobile coverage patchy; a LoRaWAN gateway may be several kilometers away or absent.
- **People:** installers are site workers or community volunteers trained by a partner, working with hand tools on slopes that may already be moving.

## Constraints

- Garage-buildable prototype: the SlopeWatch-specific parts of one site within about $250 USD, with the FieldNode core costed in its own project (SLW-DDR-001 D1, decided by Amish on 2026-09-25, SLW-DDR-002). The reference site mounts the node on an existing pole, with a new mast as a site option; SLW-CAL-001 v0.2 puts the parts at $245, or $269 with the mast.
- Built on the lab's shared FieldNode power and radio core for power, logging and LoRaWAN, so SlopeWatch designs only its sensors, alert unit and rules.
- Installed and serviced by two trained people with hand tools; no drilling rig.
- A local alarm that does not depend on the network; remote alerts in addition, not instead.
- Open data format and any LoRaWAN server (for example the lab's TwinKit gateway or The Things Network).
- Must not be presented as a substitute for engineered monitoring. On tailings dams it may be installed only with the permission of the owner and the engineer of record, as a supplementary layer under the site's surveillance plan.

## Out of scope

- Detecting brittle failures, static liquefaction or internal erosion inside a tailings dam; these need piezometers, seepage monitoring and engineering review.
- Deep-seated movement below about 1 m (needs borehole inclinometers).
- Rainfall-only early warning (can be added later with a FieldNode rain gauge).
- Designing slope stabilization, drainage or evacuation plans; SlopeWatch informs them.
- The FieldNode core and the LoRaWAN gateway themselves (covered by FieldNode and TwinKit).

## Prior work

- **Low-cost MEMS tilt sensors on slopes.** Uchimura and colleagues placed MEMS tilt sensors in the surface layer of slopes in Japan and China and proposed tilt-rate thresholds of 0.01 degrees per hour for precaution and 0.1 degrees per hour for warning ([Uchimura et al., 2015](https://www.sciencedirect.com/science/article/pii/S0038080615001122)). SlopeWatch adopts this surface-tilt approach.
- **Wireless landslide networks.** Amrita University's wireless sensor network, with tiltmeters, inclinometers, pore pressure and moisture sensors, delivered real-time warnings in the Munnar district of Kerala in 2009 that led to evacuation alerts ([Amrita](https://www.amrita.edu/center/awna/landslide/)).
- **Inverse-velocity forecasting.** The Fukuzono method remains the common first tool to estimate time to failure from accelerating displacement ([Fukuzono, 1985](https://www.jstage.jst.go.jp/article/jls1964/22/2/22_2_8/_article)).
- **Satellite radar (InSAR).** InSAR can reveal slow precursory movement over wide areas, as at Hpakant, but revisit times of days and processing delays make it a planning tool rather than a local alarm.
- **Tailings governance.** The Global Industry Standard on Tailings Management (2020) sets 77 auditable requirements covering design, monitoring and emergency response ([UNEP](https://www.unep.org/news-and-stories/press-release/new-global-industry-standard-tailings-management-aims-improve-safety)); the Global Tailings Portal lists more than 1,800 facilities disclosed by about 100 companies ([GRID-Arendal](https://tailing.grida.no/about)). Small and informal operators are largely outside both.

## Open questions

- Which partner and which first site type? Decided by Amish on 2026-10-02 (SLW-DDR-001 O2): the first candidate to approach is an operating aggregate quarry with a geotechnical engineer on staff, testing on a bench away from the work face; a hillside community and its district disaster office only after TRL 4. Not yet agreed with any partner.
- Tailings dams stay in the pitch with the scope limits above (SLW-DDR-001 D2; decided by Amish, 2026-09-25: go with recommendation, SLW-DDR-002).
- Who receives alerts and who is allowed to sound or silence the siren? This is a community decision, to be settled in co-design.
- What stake spacing and how many stakes per site are needed on typical small-mine benches and dumps?
- Is there LoRaWAN coverage at candidate sites, or does each site need its own gateway?

## User research and co-design

This design is for communities the author is not part of, so requirements come from the people who will use it.

- [ ] Identify a local partner organization. First candidate to approach (decided 2026-10-02, not yet agreed): an operating aggregate quarry with a geotechnical engineer on staff, testing on a bench away from the work face; a hillside community and its district disaster office only after TRL 4
- [ ] Run co-design sessions with intended users; record who, where and what was learned
- [ ] Validate load, distance, terrain and cost assumptions in the field
- [ ] Revise requirements (REQ) from findings before freezing the design

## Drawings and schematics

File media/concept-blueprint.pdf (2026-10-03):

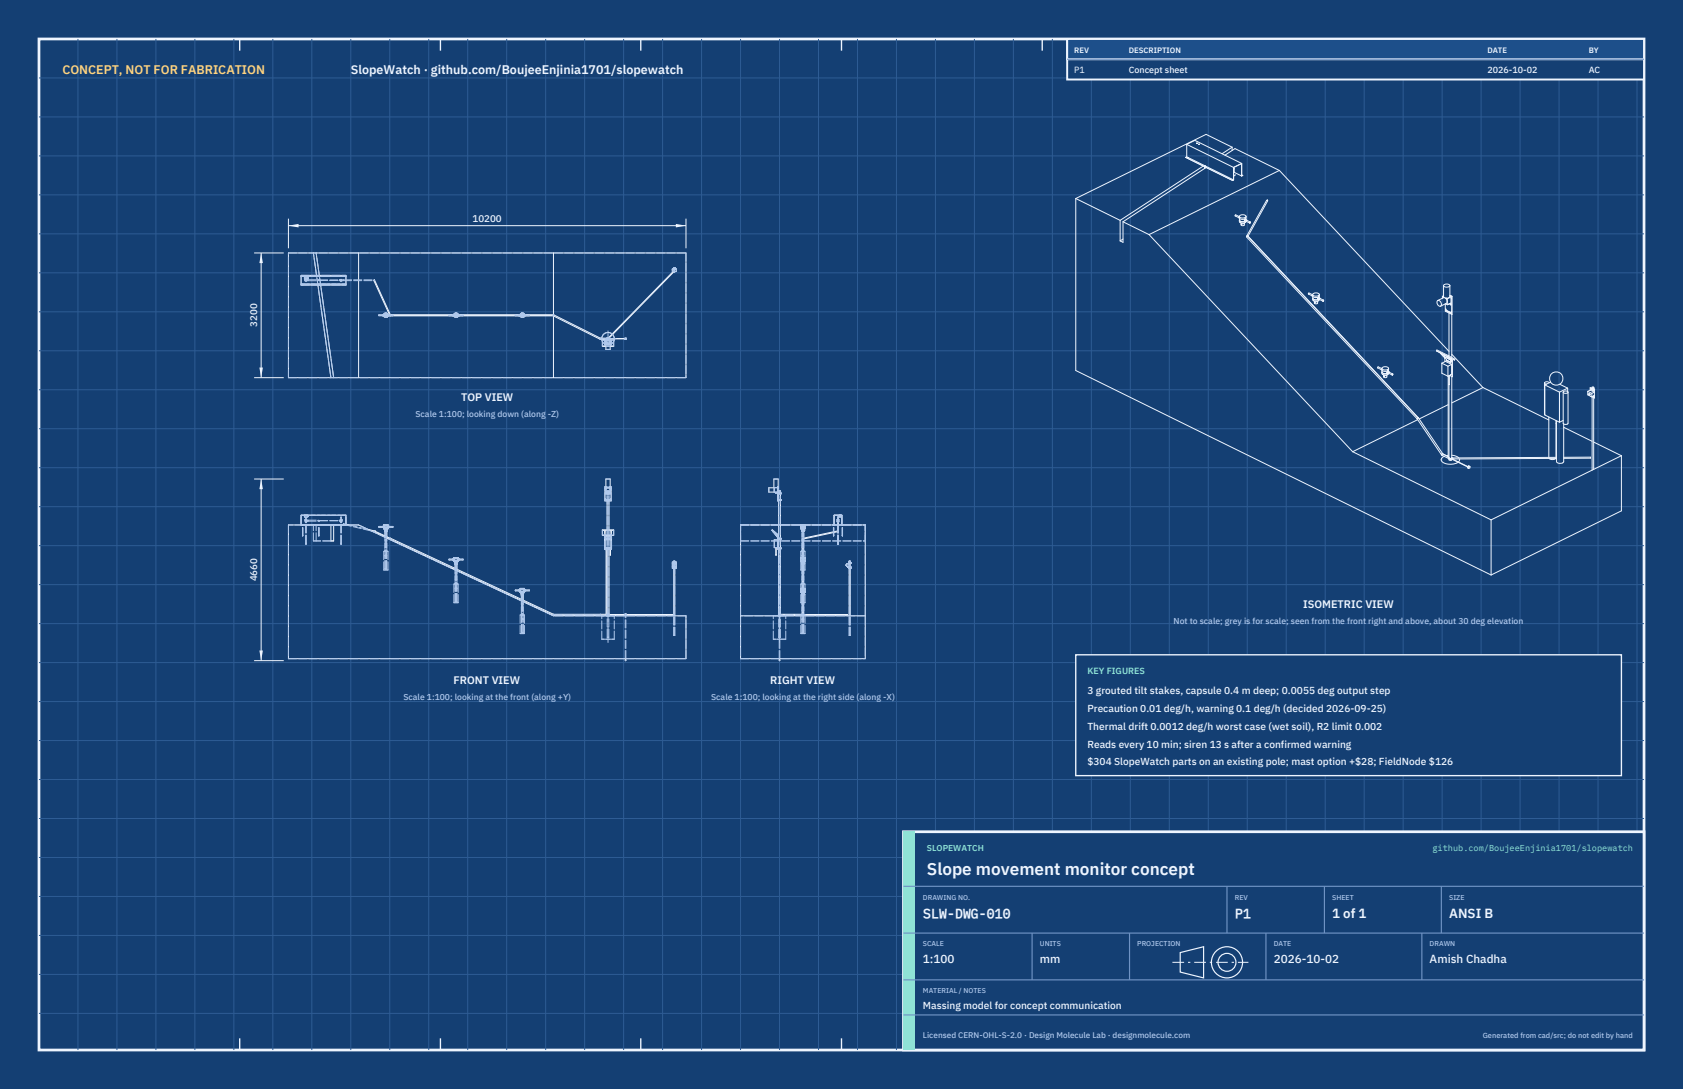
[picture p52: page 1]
CONCEPT, NOT FOR FABRICATION; SlopeWatch · github.com/BoujeeEnjinia1701/slopewatch; FRONT VIEW; TOP VIEW; RIGHT VIEW; ISOMETRIC VIEW; REV; DESCRIPTION; DATE; Concept sheet; SLOPEWATCH; github.com/BoujeeEnjinia1701/slopewatch; DRAWING NO. SLW-DWG-010; REV P1; SHEET 1 of 1; SIZE ANSI B; SCALE 1:100; UNITS mm; PROJECTION; DRAWN Amish Chadha; Licensed CERN-OHL-S-2.0 · Design Molecule Lab · designmolecule.com; Generated from cad/src; do not edit by hand

Scale 1:100; looking down (along -Z)

Not to scale; grey is for scale; seen from the front right and above, about 30 deg elevation

KEY FIGURES
3 grouted tilt stakes, capsule 0.4 m deep; 0.0055 deg output step
Precaution 0.01 deg/h, warning 0.1 deg/h (decided 2026-09-25)
Thermal drift 0.0012 deg/h worst case (wet soil), R2 limit 0.002
Reads every 10 min; siren 13 s after a confirmed warning
$304 SlopeWatch parts on an existing pole; mast option +$28; FieldNode $126

Scale 1:100; looking at the front (along +Y)

Scale 1:100; looking at the right side (along -X)

Slope movement monitor concept

MATERIAL / NOTES
Massing model for concept communication

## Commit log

2026-09-25 Initial scaffold: standard open hardware layout, CERN-OHL-S v2 + MIT licenses
    Claude-Session: https://claude.ai/code/session_01XuhhSU4W6fYhgCfURbrkut
    [bom.csv]
2026-09-25 Populate to TRL 2: problem, requirements, precis, concept media, BOM and README use cases
    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
    [bom.csv]
2026-09-26 Advance to TRL 3: DDR-001, CAL-001 sizing, parametric model with STEP/STL, GA drawing, priced BOM; TRL 4 on hold
    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
    [bom.csv, results.csv, slopewatch-arrangement.step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]
2026-09-26 Accept all recommendations (DDR-002), switch footer to designmolecule.com, add README write-up with new inspiration point
    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
    [bom.csv, results.csv, slopewatch-arrangement.step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]
2026-09-27 Product appearance model and photoreal renders
    Adds cad/src/product_model.py (appearance model for renders only, all main
    dimensions from model.py) and Blender renders in media/render-*.png,
    captioned with the project, repository and viewing direction. README leads
    with the product render; trl stays 3.
    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
2026-10-01 Image quality pass: legible exploded views, flow diagrams and drawing sheets
    Kit 1.6.1 image layout: the parts list sits in its own column, number bubbles sit on visible parts and never overlap, small parts get a leader, pictures are cropped to the subject, flow labels keep numbers with their units, and sheet captions and the revision table no longer overprint. Concept images, blueprint and general arrangement sheet regenerated; repo-specific labels moved clear of other text and lines.
2026-10-01 Kit 1.7.0: constructable design, illustrated build plan and design decisions register
    The design is now constructable: every part can be made and fits its neighbours, with each change recorded in a Design for construction decision record (made under Amish's 2026-09-30 instruction; ope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
    FlexHand also credits Dr. Geeti Chadha as a contribut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
    [bom.csv, results.csv, slopewatch-arrangement.step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]
2026-10-02 Record Amish's approval of the open-decision recommendations
    Amish approved the recommendation on every open decision in the design decisions register ("i approve your recommendations for all 555 open decisions.", 2026-10-02). Each decision is moved to Decisio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
2026-10-03 Carry approved follow-ups into the design and redo photoreal renders
    Amish approved the follow-up actions from the open-decision sign-off ("APPROVED CHANGES, COMPLETE THESE", 2026-10-02), the design-for-construction change tables in ten repos, the last wave's open dec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
    [bom.csv, results.csv, slopewatch-arrangement.step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]

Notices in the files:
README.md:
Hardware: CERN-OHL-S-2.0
